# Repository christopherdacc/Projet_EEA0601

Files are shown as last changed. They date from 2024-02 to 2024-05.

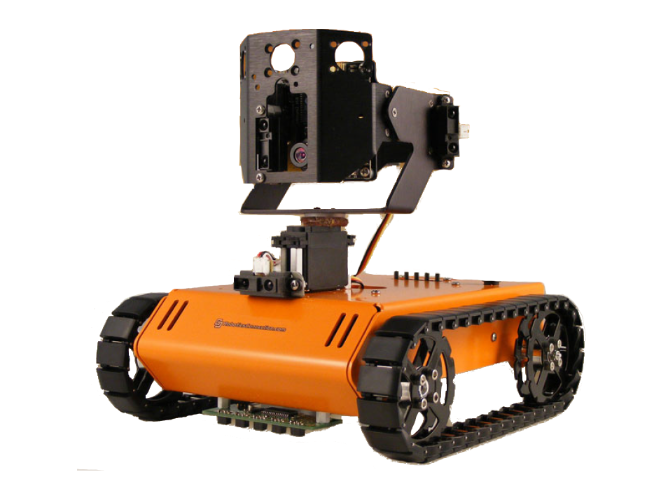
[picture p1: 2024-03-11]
Compte_rendu/pics and files/Screenshot 2024-02-27 at 23-01-09 Guide de réalisation du projet EEA0601.pdf.png

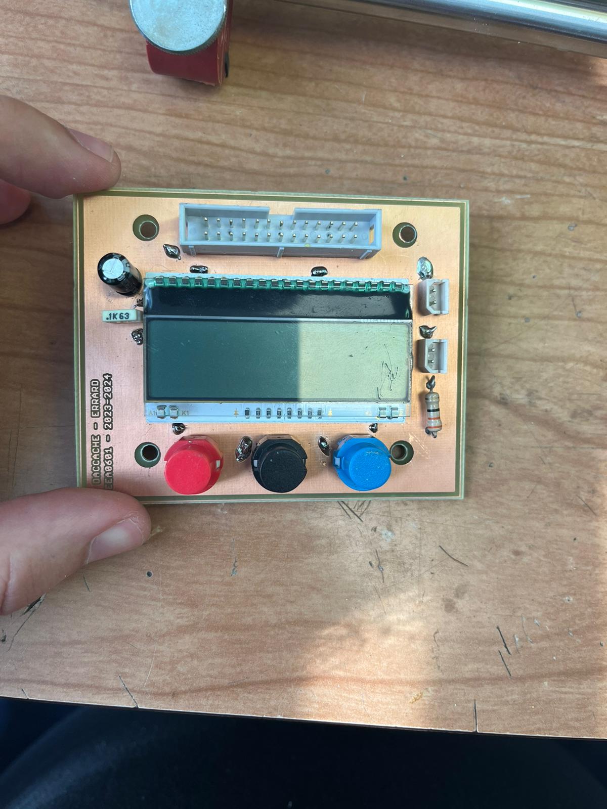
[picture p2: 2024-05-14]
Compte_rendu/IMG-20240328-WA0003.jpg

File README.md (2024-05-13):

# Projet_EEA0601 (Partie IHM)

Programmation en langage C sur MPLAB X IDE d'un microcontrôleur (dsPIC30F4012) pour un système d'IHM d'un robot.
Ce robot a pour fonction de suivre une trajectoire (suit une ligne dessinée par terre), détecter les obstacles et changer de direction pour poursuivre son chemin et une interface IHM pour pouvoir entrer des informations au microcontrôleur avec 3 boutons.

"Séances de travail surveillées et supplémentaires avec tâches réalisées"

* Séance 1 (24/01/2024):
      Explication du projet par les professeurs.
  
* Séance 2 (31/01/2024):
      Branchement d'un afficheur LCD (EA DOGM163W-A) et allumage du rétroéclairage.

* Séance 2.1 sup (02/02/2024):
      programmation et affichage de 'Bonjour le monde!' sur l'écran LCD.
  
* Séance 3 (07/02/2024):
      Branchement des boutons avec leurs résistances spécifiques.

* Séance 4 (14/02/2024):
      Programmation des boutons pour savoir s'ils sont appuyés ou non en affichant leurs états sur l'écran LCD.

* Séance 5 (21/02/2024):
      Rajout des librairies sur Eagle.
      Réalisation du schéma de la carte électronique sur Eagle.

* Séance 5.1 sup (22/02/2024):
      Finalisation du schéma de la carte électronique sur Eagle.
      Début de la réalisation de la carte électronique sur Eagle ainsi que le typon.
* Séance 5.2 sup (23/02/2024):
      Début de la programmation d'un menu avec les options de test des boutons et changement de l'éclairage de l'écran.

* Travail Vacances 6 (du 24/02/2024 au 02/03/2024):
      Finalisation du code menu (prototype)
      Erreur de Build du code.

* Séance 6.1 test du code (05/03/2024):
      Test du code et correction du build error.
      Nouveau probleme code ne marche pas comme on veux.

* Séance 7 (06/03/2024):
      Correction du Schéma de la carte.
      Correction de la carte par rapport au changements du schéma.
      Un peut de modification du code pour qu'il marche (ne marche toujours pas).

* Séance 7.1 sup (07/03/2024):
      Correction de l'affichage du menu (sélection de choix marche bien mais les choix ne marchent pas a 100%)

* Séance 7.2 sup (11/03/2024):
      Correction de la fonction délai.
      Travail sur le compte rendu.

* Séance 8 (13/03/2024):
      On a continué le routage des pistes.
      On a changer les pates des boutons et de l'ecran pour mettre les pates des boutons sur les pates CN qui permettent les interuptions sur front.
  
* Séance 9 (20/03/2024):
      On a finit la carte électronique avec le dimentionnement des pistes de +5V (0.05 inch) et pistes de signaux (0.024).
      On a cassé les angles et tout ca pour evité le rayonnement electromagnetique.

* Séance 10 (27/03/2024):
      On a percé la carte pour pouvoir souder les composants decu.

* Séance 10.1 sup (28/03/2024):
      On a réalisé le test de continuité a l'ohm mètre.
      On a resouder une piste défectueuse.
      On a souder tout les composants sur la carte.
* Séance 11 (03/04/2024):
      Reprogrammation du test des boutons en utilisant des iterruptions.
      Interruptions fonctionnent mais que sur le bouton 3.

* Séance 11.1 sup (09/04/2024):
      Correction du code de l'interruption (Fonctionnement parfait des boutons).
      Essai d'integrer la structure Keyboard avec les objets, mais pas de success.
      Changement du bouton rouge.
      Pendant le test du code, on a rencontrer un probleme de fonctionnement du microcontrolleur.
      Probleme de cablage au niveau de l'alimentation du microcontrolleur.

* Séance 12 (10/04/2024):
      Réglage du probleme de cablage au niveau de l'alimentation du microcontrolleur.
      Le code fonctionne a nouveau.
      Ajout de la fonction menu_principale() pour afficher le menu avec les different choix.
      Programmation de la navigation du curseur pour selectionner 1 des 3 choix avec prog de la saisier du choix 1 (Actions).
* Pour la prochaine séance :        - Essayer de remplacer les statusB, statusN et statusR par la structure keyboard.
                                    - Implémanter cette structure dans la fonction menu_principale().
                                    - Continuer la programmation de l'affichage.
  
* Séance 12.1 sup (13/04/2024):
      On a realiser les taches pécedantes (remplacement statusB.../implementer la struct keyboard.../ continuer la programmation de l'affichage).
      On a essayer d'implémenter les strcutures Menu, MenuItem et MenuValue mais on a pas réussi.

* Séance 12.2 sup (16/04/2024):
      On a continuer l'affichage du menu et differente options du menu avec des if et else if.
      On a réessayer d'implenter les structures Menu, MenuItem et MenuValue maus on a toujours pas réussi.
      On a essayer d'ajouter le keybord->upstate=2 pour une appuie de 2s sur le bouton rouger, mais on a pas réussi.

* To do: try using macros to simplify and reduce memory usage.

* Séance 13 (17/04/2024):
      On a utiliser macros (#define) pour l'operation moyenne%3
      On pu utiliser ticks.c pour pouvoir determiner l'appui de 2s sur un bouton.
      On a continuer la partie parametres->reglage detection obs pour essayer d'afficher un chiffre et l'incrémenter mais l'addition de chiffre et considere comme un char.
      On a vite fait compris le fonctionnement des differentes struct du menu(Menu, MenuItem et MenuValue) et l'utilisation d'une array pour stocker les differents MenuItems.

* To do: implementer les 3 structures du menu a la fonction menu_principale, réessayer la configuration de l'affichage d'un int modifiable sur l'ecran,

* Séance 13.1 sup (19/04/2024):
      On a réussi a configurer l'affichage d'un int qu'on peut incrémenter et décrémenter a l'aide des boutons pour la partie Parametres->Detection obstacle.
  
* Séance 14 (07/05/2024):
      On a finaliser le menu (partie affichage et manupulation du menu).
      Il nous reste la partie parametre (PID et vitesse) a réglé.
      Il nous reste les interruption pour recevoir et transmettre les info des capteurs et moteurs.
      il nous reste a configurer la structure MenuValues pour pouvoir envoyer les parametres au moteur.

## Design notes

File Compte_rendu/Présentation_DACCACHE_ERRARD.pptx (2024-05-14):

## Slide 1

SOMMAIRE

I. Introduction
II. Initiation à la programmation
III. Construction du programme final
IV. Conclusion

## I. Introduction

- Conception d’un robot suiveur de ligne
- Divisé en trois parties
- 13 séances obligatoires
- Capteurs de position et détecteur d’obstacles
- 2 moteurs indépendamment
- Ecran LCD
- Trois boutons
- Microcontrôleurs (carte DsPic)

## II. Initiation à la programmation

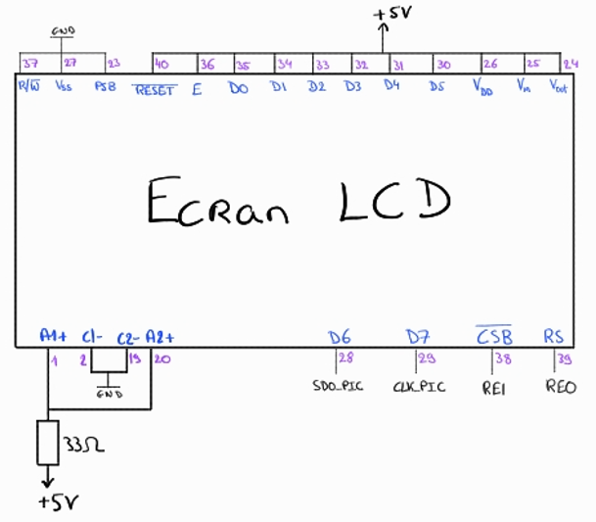
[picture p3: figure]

a) Câblages

- Ecran : 22 pin sur 40 d’utilisés
- Résistance : 33Ω
- 2 Capacités : 100µF et 100nF

## II. Initiation à la programmation

a) Câblages

- 3 Boutons sur le port B : CN

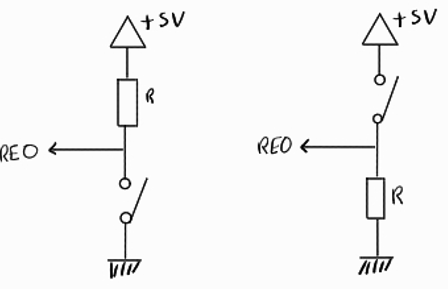
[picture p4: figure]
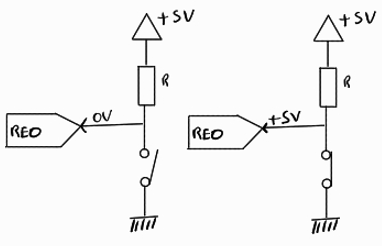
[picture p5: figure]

## II. Initiation à la programmation

b) Eagle

- Schéma électronique
- Carte élecronique
- Dimensionnement
- Cassure des coudes
- Perçage et soudure

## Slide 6

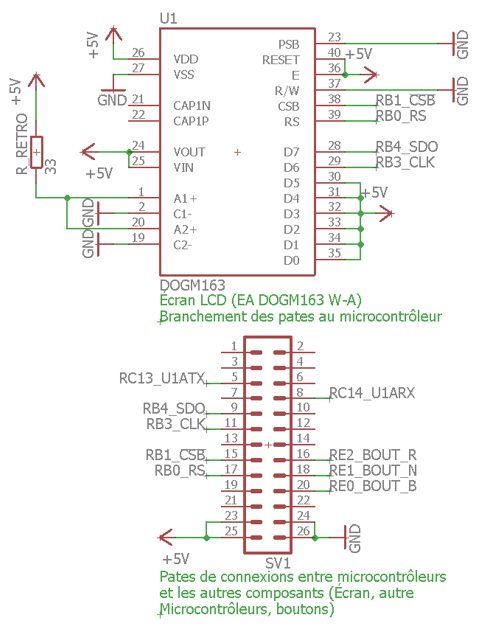
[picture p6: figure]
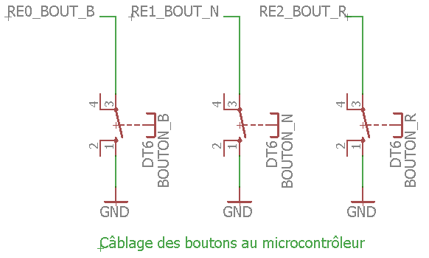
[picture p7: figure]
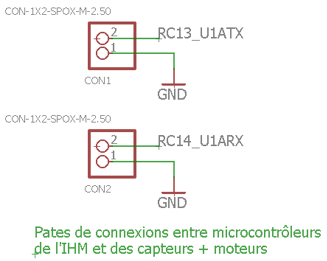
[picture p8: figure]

Schéma de la carte électronique

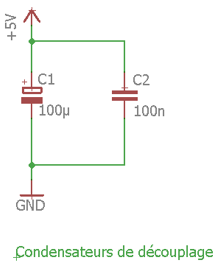
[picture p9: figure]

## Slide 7

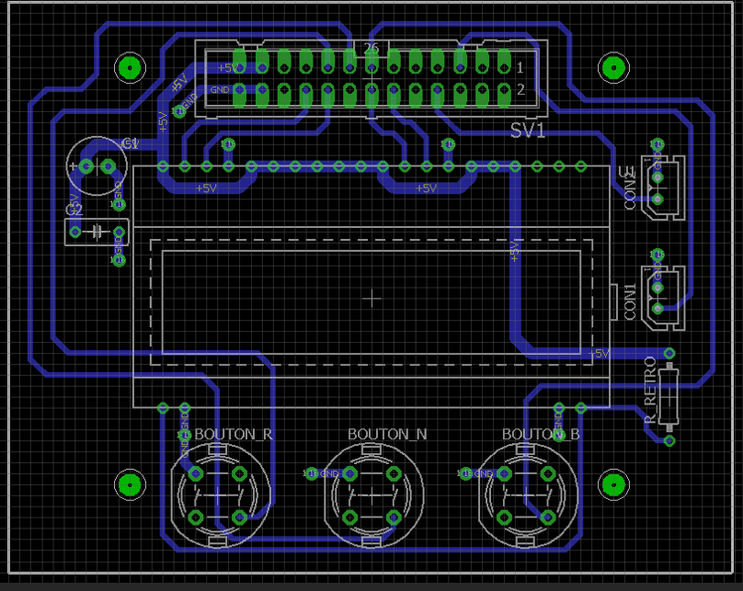
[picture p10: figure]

Board de la carte électonique

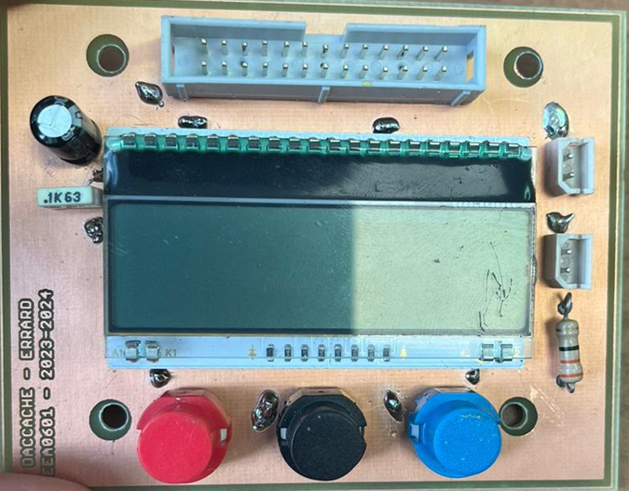
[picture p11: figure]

Carte électronique après soudure

## II. Initiation à la programmation

c) Affichage et test des boutons

- Premier programme simple :
« InitLCD();
LCDDisplayOn();
LCDGoto(0,0);
LCDWriteStr(« Bonjour"); »
- LCDGoto(X,Y);
X : nombre de ligne
Y : Position sur la ligne

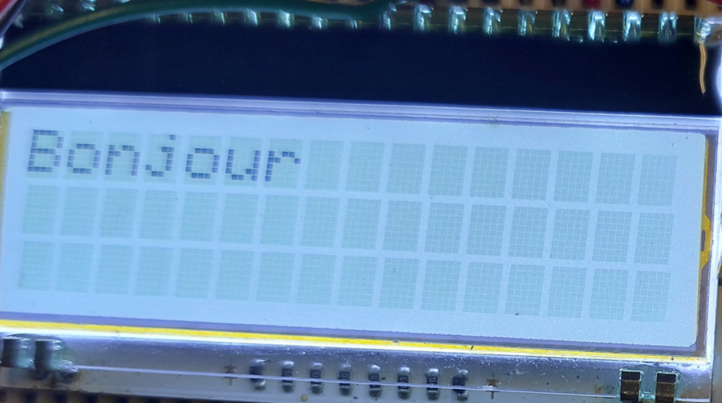
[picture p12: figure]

## II. Initiation à la programmation

c) Affichage et test des boutons

- Programmation des boutons :
« #define BUTTON1_PIN PORTBbits.RB0
#define BUTTON2_PIN PORTBbits.RB1

#define BUTTON3_PIN PORTBbits.RB2

void init_pins() {
TRISBbits.TRISB0 = 1;
TRISBbits.TRISB1 = 1;
TRISBbits.TRISB2 = 1;
CNPU1bits.CN2PUE = 1;
CNPU1bits.CN3PUE = 1;
CNPU1bits.CN4PUE = 1;
}»

do{
while (myKeyboardptr->enterEdge==1)
{
LCDGoto(0,0);
LCDWriteStr("Button 1 = 1");
}

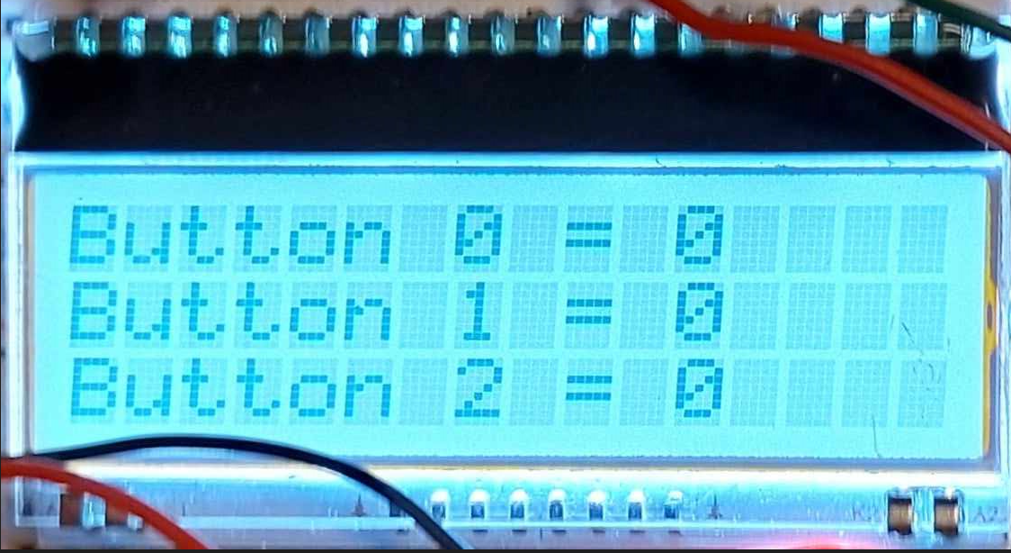
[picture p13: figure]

## II. Construction du programme final.

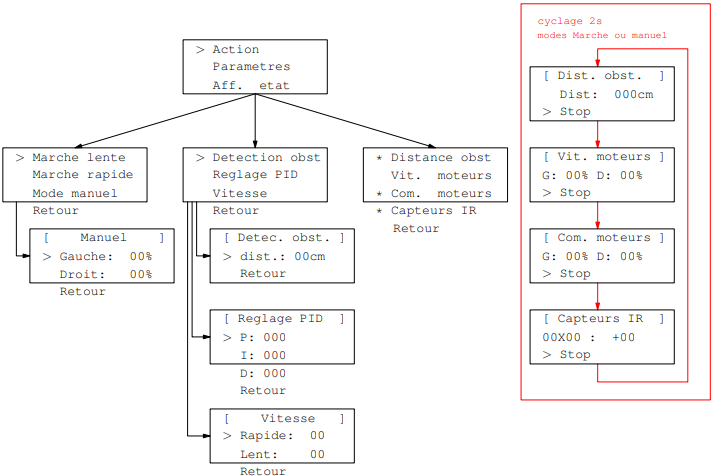
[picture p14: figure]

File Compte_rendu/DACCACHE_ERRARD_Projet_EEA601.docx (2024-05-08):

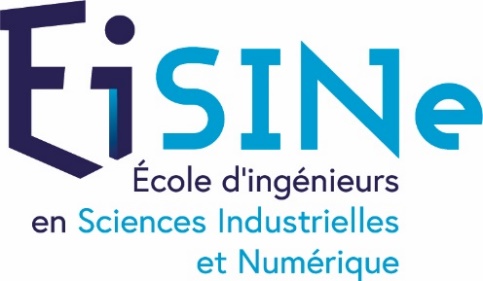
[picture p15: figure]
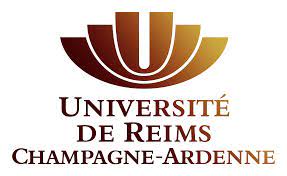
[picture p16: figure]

DACCACHE Christopher

ERRARD Mathéo

Licence 3 – EEEA

Projet : Robot suiveur de ligne

Module EEA 0601

TP Transdisciplinaire

# ---------- INTRODUCTION ----------

Dans le cadre de la matière EEA0601, nous avions comme responsabilité de mettre en place la conception d'un robot suiveur de ligne. Ce projet est une opportunité d'appliquer les connaissances que l’on a pu acquérir tout au long de nos études dans le domaine de l’électronique et de l’automatique. Pour mener à bien ce projet, il a été divisé en trois parties distinctes :

- Motorisation,
- Interface Homme-Machine (IHM)
- Capteurs

Chaque groupe possédait de treize séances obligatoire dont dix encadrées et trois en autonomie. Ce rajoute à ça, les séances personnelles. Un planning récapitulatif de nos séances est affiché un peu plus loin dans ce rapport.

Ce projet vise à développer une solution technique complète pour un robot capable de suivre une trajectoire préalablement tracée sur le sol qu’il détecte grâce à des capteurs à photodiodes. Muni de deux moteurs indépendants, il peut se déplacer de manière linéaire et angulaire en modifiant la vitesse de rotation des moteurs. Ainsi, par le biais de ces moteurs, il peut corriger sa position selon son décalage par rapport à la trajectoire voulue.

Notre binôme s’est concentré sur la partie IHM, une composante essentielle qui permet la communication entre l'utilisateur et le robot. Notre objectif principal est de concevoir une interface intuitive et fonctionnelle, intégrant des éléments de contrôle permettant à l'utilisateur de communiquer efficacement avec le robot. Pour ce faire, nous disposons de trois boutons et d'un écran d'affichage, des éléments clés qui seront utilisés pour configurer les paramètres du robot et définir ses actions.

Le succès de notre projet dépendra de la collaboration étroite entre les différentes équipes travaillant sur les différentes parties du robot. Nous devons assurer une intégration fluide de notre système IHM avec les systèmes de motorisation et de capteurs, garantissant ainsi le bon fonctionnement global du robot suiveur de ligne.

La présentation du travail effectué par notre binôme sera présentée en trois parties. La première consistera à présenter le cahier des charges, le matériel utilisé ainsi qu’un planning d’avancement du projet. La seconde, elle, décrira toute la partie électronique que nous avons pu réaliser. Quant à la dernière qui expliquera la partie programmation et asservissement du moteur.

# ---------- DEVELOPPEMENT ----------

I) Initialisation
a) Cahier des charges

La cahier des charges peut se décrire en plusieurs points.

Le premier est de concevoir et implémenter une interface homme-machine pour un robot suiveur de ligne afin de pouvoir configurer différents paramètres.

En deux, l’IHM doit être équipée de trois boutons, chaque bouton étant assigné à une fonction spécifique.

Un écran d'affichage doit y être intégré, permettant à l'utilisateur de visualiser les paramètres du robot et de sélectionner différentes actions.

Le troisième point est de pouvoir afficher différentes informations telles que la vitesse du robot, les données des capteurs comme la distance par rapport à un obstacle ou encore sa déviation par rapport à la ligne. Mais également la sélection des actions à effectuer par le robot, comme une marche lente ou rapide ou encore la correction de trajectoire.

En quatrième point, l'IHM doit être capable de recevoir et de traiter les données des capteurs du robot et de pouvoir envoyer des instructions aux moteurs du robot en fonction des informations reçues des capteurs et de la configuration que souhaite l'utilisateur.

b) Description du matériel

Pour mener à bien à bien ce projet une liste du matériel nécessaire pour chaque partie a été établit :

Capteurs | Moteurs | IHM
Carte DsPic | Carte DsPic | Carte DsPic
Capteurs de position (photos diodes) IR TCRT 5000 | Moteur | 3 boutons de type DT6
Capteurs d’obstacles (à ultrasons) : SRF 05 | BTN 8982 | Ecran LCD: EA DOGM163W-A

c) Planning

Date | Descriptions | Membre
31/01 | Câblage de l’écran LCD et allumage du rétroéclairage. | C /M[^1]
02/02 | Programmation et affichage d’un message sur l’écran LCD. | C/M
07/02 | Branchement des boutons et choix des résistances qui leurs sont associées. | C/M
14/02 | Programmation des boutons et affichage de leurs états (appuyé ou relâché) sur l’écran. | C/M
21/02 | Début sur Eagle : ajout des librairies et réalisation du schéma de la carte électronique. | C/M
24/02 au 02/03 | Réalisation d’un programme « Menu » permettant de choisir une action à l’aide des boutons. (Vacances) | C
05/03 | Test du code « Menu » mais échec. | C/M
06/03 | Correction du schéma de la carte de la carte et début de réalisation du typon et correction du code « Menu » mais non opérationnel à 100% | C/M
13/03 | Routage des pistes. Modification du choix des pattes des boutons : utilisation des CN (port B) pour les interruptions | C/M
20/03 | Finalisation de la carte électronique sur Eagles. | C/M
27/03 | Perçage de la carte, test de continuité à l’ohmmètre, soudure | C/M
03/04 | Modification du programme en utilisant les interruptions sur les boutons | C/M
09/04 | Essai de la structure Keyboard (échec). Changement du bouton rouge car légèrement défectueux. Problème au niveau des câbles d’alimentation de la carte µC. | C/M
10/04 | Changement de carte µC. Ajout de la fonction menu_principale() et affichage du menu demandé (Actions/ Paramètres/Affiche Etat) | C/M
13/04 | Insertion de la structure Keyboard dans le programme. Essai d’insertion des structures Menu, MenuItem et ManuValue | C/M
16/04 | Avancement de l’affichage avec la réalisation des sous menu. Essai de la programmation de la durée d’appui sur les boutons (échec) | C/M
17/04 | Utilisation de « ticks.c » pour gérer la durée d’appui sur les boutons. Finalisation des sous menus et insertion des structures Menu, MenuItem et MenuValue | C/M

II) Conceptions électroniques.
1. Câblage de l’afficheur

L’afficheur utilisé est un afficheur LCD sept segment de référence EA DOGM163W-A alimenté en 5V. Il possède 40 pins de connection et permet d’afficher seize carctères par ligne. Il est piloté par une interface SPI. Le branchement entre le micro-contrôleur et l’afficheur se fait par une nappe.

D’après la notice de celui-ci, il faut brancher une résistance de 30Ω relié au +5V, branché en parallèle entre les pins 1/2 et 19/20 comme on peut le voir sur la figure suivante. Dans notre cas, nous avons utilisé une résistance de 33Ω car il n’y avait de 30Ω. Les pins 1 et 20 correspondent à des anodes et les pins 2 et 19 à des cathodes. Sur les 40 pins du µC, seulement 22 ont été utilisés.

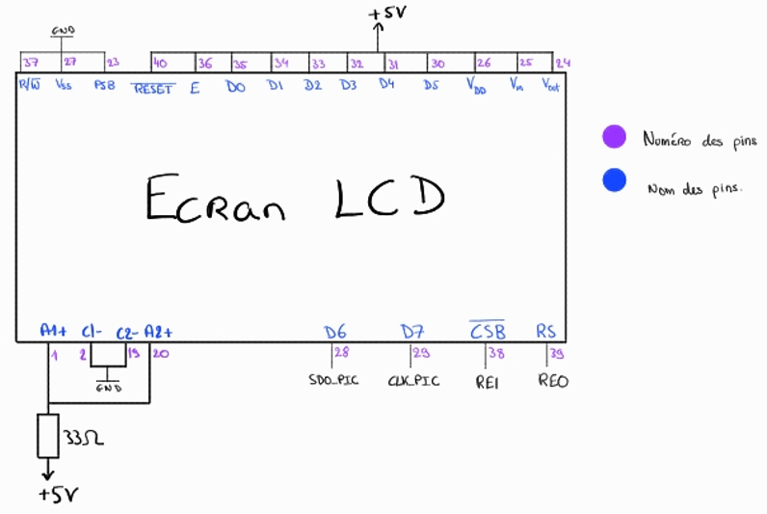
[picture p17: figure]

FIGURE

D’après la documentation qui nous a été transmise, les pins correspondant au RS, CSB, RESET sont branché sur le port B. Cependant, nous avons du changer le port B pour le port E pour garder les pattes du port B pour pouvoir utililser les interruptions du port B. Le pin 40 correspondant au RESET a été mit au +5V au lieu du port RE2 pour éviter tout problème de reset.

Pour éviter les distorsions de la tension d’entrée et donc avoir une entrée non bruitée, on a placé deux capacités de découplage en parallèle afin de protéger l’écran des fluctuation de tension. L’une est une électrochimique de valeur 100µF et l’autre est en plastique de valeur plus faible de 100nF.

2. Câblage des boutons

Pour le branchement de noq trois boutons DT6, il nous a fallut mettre des résistances en série avec les boutons et nous avons pris des résistances de 10kΩ. Dans un circuit, ils se comportent comme des interrupteurs normalement ouvert ou normalement fermé selon la configuration. La figure suivante nous montre les deux façons possibles de câbler les boutons.

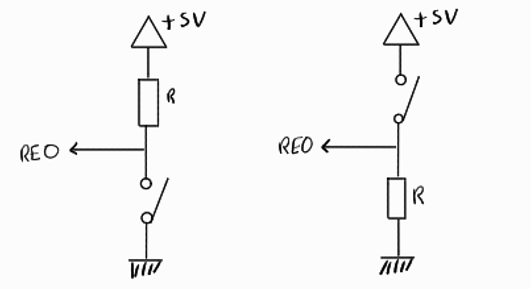
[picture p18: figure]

FIGURE CONFIGURATION BOUTON

Dans notre cas nous avons choisit la configuration 1. Dans celle-ci les boutons sont normalement ouvert et renvoient donc 0V sur les pattes sur lesquelles ils sont connectés. Un appui sur un bouton envoi du 5V sur sa patte de connection. La figure suivante nous résume ceci :

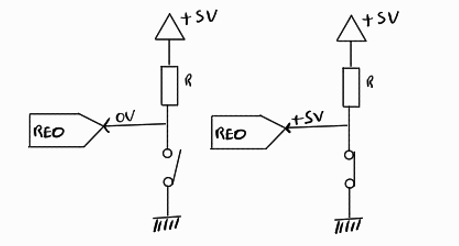
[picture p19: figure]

FIGURE LECTURE D’APPUI SUR UN BOUTON

Pour savoir si un bouton est appuyé ou non il suffit de lire la valeur reçue sur la pin correspondante.

Nos trois boutons sont de couleurs différentes : un rouge, un bleu et un noir. Leurs actions sont les suivantes :

- Rouge (+) : Incrémenter des valeurs numériques ou de monter dans un menu ou sous-menu
- Bleu (-) : Décrementer des valeurs numériques ou de descendre dans un menu ou sous-menu
- Noir (entrée) : Valider une valeur ou sélectionner une entrée dans un menu ou sous-menu

Ils vont nous permettre de naviguer, de rentrer, de sortir des menus et sous menus ainsi que d’y sélectionner différentes actions.

3. Construction schématique de la carte électronique

Après le câblage de l’écran ainsi que des boutons sur plaque à essai, nous avons réalisé sur l’application Eagles le schéma de la carte électronique comme on peut le constater sur la figure suivante.

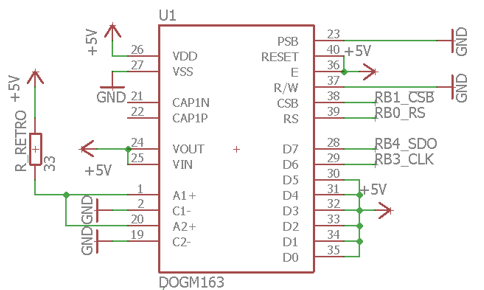
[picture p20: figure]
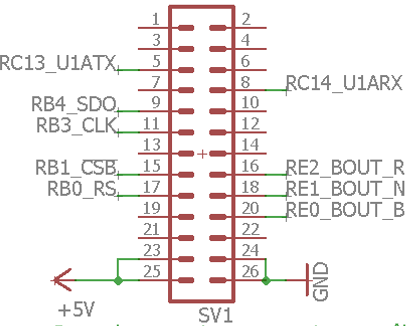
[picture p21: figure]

FIGURE ECRAN EAGLE

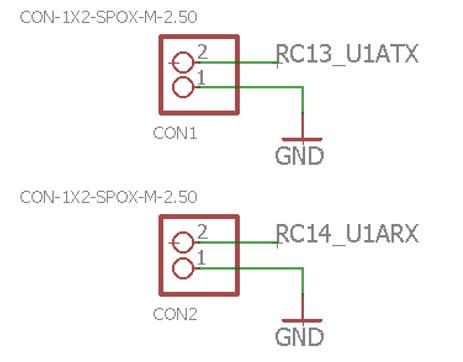
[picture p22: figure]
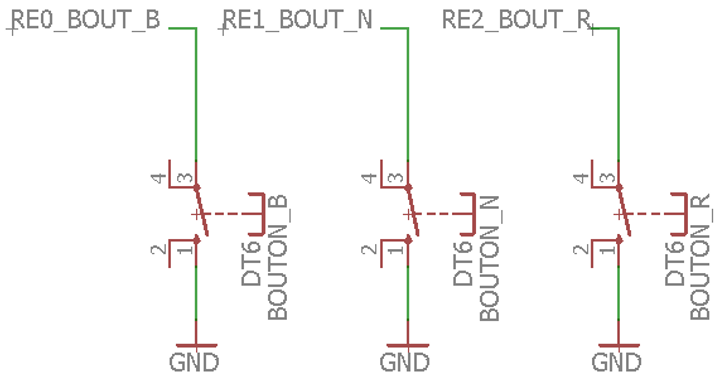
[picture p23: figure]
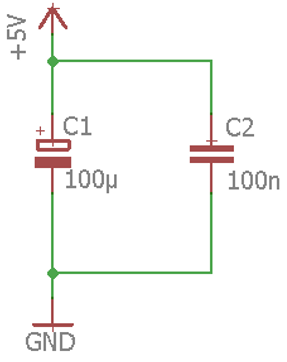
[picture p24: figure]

Pour pouvoir communiqué avec les autres groupes (capteurs et motorisaton) à l’aide d’une liaison RS232, nous avons donc placé deux connectiques Molex 22035025. L’un servira à recevoir des informations des capteurs et l’autre d’envoyer des informations à la motorisation. L’image suivante nous montre comment se fait la connexion :

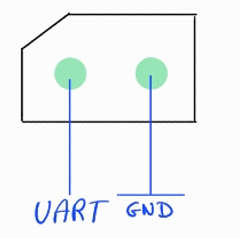
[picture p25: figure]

FIGURE CONNECTIQUES

La connexion se fait par les pattes UART du µC. La patte U1ATX sert à la réception de données et la patte U1ARX sert à la transmission de données.

III) Conceptions informatique.
1. Initiation à la programmation

Dans un premier temps, nous avons commencé par programmer et afficher un message simple pour se familiariser avec le logiciel. Nous avons afficher le message « Bonjour le monde ». Le code d’affichage de ce message est en annexe 1 et la figure suivante correspond à l’organigramme de ce message.

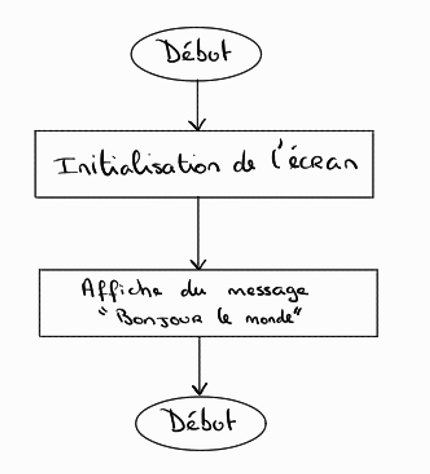
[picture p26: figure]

Figure : Organigramme du premier code

Dans un second temps, nous avons fait le branchement des boutons qu’on peut retrouver sur l’annexe 2. Nous avons d’abord programmé l’appui d’un seul bouton à la fois est d’afficher à 1 lorsque le bouton est appuyé. La figure suivante nous montre l’organigramme de ce code. Ensuite, on a modifié ce code pour pouvoir lire et afficher l’appuie sur un ou plusieurs bouton. Dans cette étape, on a d’abord fait la programmation sans utiliser les interruptions seulement avec des « if » ou « else if » puis après avec les interruptions. Et en faisant ces deux méthodes, on a observé que la méthode des interruptions étaient plus rapide.


[^1] C : Christopher / M : Mathéo

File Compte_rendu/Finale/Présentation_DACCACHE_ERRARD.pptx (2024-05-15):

## Projet : Robot suiveur de ligne


Sujet : Interface Homme Machine d’un Robot Suiveur de Ligne
Réalisé par ERRARD Mathéo et DACCACHE Christopher
Enseignants responsables : COLAS Maxime et CARTON David

Module EEA 0601
TP Transdisciplinaire Année 2023/2024

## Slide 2

SOMMAIRE

- Introduction
- Conceptions électroniques
- Conceptions Informatiques
- Conclusion


## I. Introduction

- Cahier des charges
- Matériel Utilisé


## I. Introduction


- Planning

## II. Conceptions électroniques

a) Câblages

- Ecran : 22 pins sur 40 d’utilisés
- Résistance : 33Ω
- 2 Capacités : 100µF et 100nF


## II. Conceptions électroniques

a) Câblages

- 3 Boutons sur le port RB : CN


## II. Conceptions électroniques

b) Réalisation Carte Électronique

- Schéma électronique
- Carte électronique
- Dimensionnement
- Prévention des perturbations électromagnétiques
- Perçage et soudure

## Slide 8


Schéma de la carte électronique


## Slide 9


Board de la carte électonique


Carte électronique après soudure

## III. Conceptions Informatiques

a) Affichage et test des boutons

- Premier programme simple :
« InitLCD();
LCDDisplayOn();
LCDGoto(0,0);
LCDWriteStr(« Bonjour"); »
- LCDGoto(X,Y);
X : nombre de ligne
Y : Position sur la ligne


## III. Conceptions Informatiques

a) Affichage et test des boutons

- Programmation des boutons :
#define BUTTON1_PIN PORTBbits.RB0

#define BUTTON2_PIN PORTBbits.RB1

#define BUTTON3_PIN PORTBbits.RB2

void init_pins() {
TRISBbits.TRISB0 = 1;
TRISBbits.TRISB1 = 1;
TRISBbits.TRISB2 = 1;
CNPU1bits.CN2PUE = 1;
CNPU1bits.CN3PUE = 1;
CNPU1bits.CN4PUE = 1;
}

do{
while (myKeyboardptr->enterEdge==1)
{
LCDGoto(0,0);
LCDWriteStr("Button 1 = 1");
}


## III. Conceptions Informatiques

b) Structure du Menu


## III. Conceptions Informatiques

b) Structure du Menu


## III. Conceptions Informatiques

c) Initialisation du Menu


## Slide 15

d) Paramètres du Menu


## IV. Conclusion

- Difficultés
- Solutions
- Projet finale
- Conclusion

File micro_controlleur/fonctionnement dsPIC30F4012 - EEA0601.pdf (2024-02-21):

EEA0601

L3 EEEA
année 2022-2023

### TP transdisciplinaire en EEA Principes de programmation du dsPIC30F4012

## 1 Structure d’un microcontrôleur

Un microcontrôleur est un composant associant dans un même boitier un coeur de microprocesseur, de la mémoire et des périphériques.

### 1.1 Microprocesseur

Le microprocesseur a pour rôle d’éxécuter un programme composé d’une succession d’instructions rangées en mémoire. Pour cela, il dispose d’une unité de décodage d’instructions, d’une unité arithmétique et logique et de registres. Ces derniers sont destinés :
- à manipuler les données (registres de travail ou W) ;
- à indiquer l’état du processeur (registres SR) ;
- ou à piloter le moteur DSP intégré au microprocesseur.

SFR; RAM; Flash; EEPROM; µProc; PWM; Timers; ADC; Osc.; Watch D; DCI; SPI; UART; CAN; m´emoire donn´ee; m´emoire prog.; bus synchrones bus asynchrones; Interruption Config./Contrˆole; Microcontrˆoleur

Fig. 1 : Structure interne d’un micro-contrôleur
Dans un langage évolué tel que le C, les registres ne sont presque jamais manipulés par le programmeur.

### 1.2 Mémoire

Le programme et les données sont stockées différemment selon l’architecture du microcontrôleur. Dans le cas de la structure de type Harvard utilisée par Microchip, trois types de mémoires sont disponibles et utilisés comme suit :
- la RAM représente quelques ko de mémoire volatile : elle accueille les variables utilisées par le programme ;
- la FLASH représente quelques centaines de ko voire quelques Mo : elle accueille le programme ainsi que les données constantes. Cette mémoire est conservée en cas de rupture de l’alimentation ;
- l’EEPROM est disponible pour stocker les données de configuration critiques d’un programme en cas de perte d’alimentation et les restituer au redémarrage. Généralement chaque microcontrôleur en embarque 1 ou 2 ko.
M. COLAS | 1

Espace programme
Les mémoires FLASH et l’EEPROM sont accédées par un bus de 24bits permettant d’adresser potentiellement 16Mo appelés espace programme. l’espace programme est pointé par un registre appelé compteur programme ou PC dont le rôle est de dépiler les instructions du programme. L’ensemble de cet espace d’adressage n’est pas uniquement occupé par du code programme ou par les données de l’EEPROM. Le début de la zone accueille la table des adresses des routines d’interruption et les 8Mo d’adresse haute sont réservés pour stocker quelques éléments tels l’identifiant du microcontrôleur ou ses bits de configuration. Finalement, la majorité de l’espace programme ne contient pas réellement de mémoire physique. Une grande partie des adresses sont inutilisées et pointent dans le vide.
M´emoire donn´ees | M´emoire programme

0x0000

0x07FE
0x0800

0x1000

0x8000

0xFFFE

SFR

RAM dsPIC30F4012 (2ko)

Non utilis´e

Fenˆetre m´emoire prog.

Vecteurs
d’interruption

0x000000

0x0000FE

M´emoire prog. 48kInst.

Non utilis´e

EEPROM 1ko

Zone de config.

0x017FFE
0x018000

0x7FEFFE
0x7FF000

0x7FFFFE
0x800000

0xFFFFFE

Fig. 2 : Espaces d’adressage données et programme

Espace données
Le microprocesseur accède à la mémoire RAM à l’aide d’un bus de données 16bits qui ne permet d’adresser que 64ko de mémoire. Une partie de cet espace d’adressage (environ 2ko) est réservée pour accéder aux registres de périphériques appelés SFR (special function registers). Ces registres permettent de configurer et de piloter chacun des périphériques présents dans le microcontrôleur. Le découpage des espaces mémoire est présenté sur la figure 2 dans le cas spécifique du pic30F4012.

### 1.3 Périphériques

Les périphériques intégrés au microcontrôleur sont nombreux et aux fonctionnalités multiples :
- interfaces dédiées aux bus de communications synchrones (SPI, DCI, I2C) ;
- interfaces dédiées aux bus de communication asynchrones (UART, CAN) ;
- entrées-sorties TTL ou à collecteur ouvert ;
- timers ;
- input-capture ;
M. COLAS | 2

- output-compare ;
- générateur de modulation de largeurs d’impulsions (PWM).
Grâce au mécanisme d’interruption décrit en section 2.1, chacun de ces périphériques est apte à indiquer au microprocesseur l’ocurrence d’évènements nécessitant un traitement immédiat.

## 2 Structure d’un programme sur microcontrôleur

Les programmes implantés sur les microcontrôleurs possèdent tous la même structure : les actions périodiques ou déclenchées par les périphériques sont insérées au sein de routines d’interruption. Parmi ces actions, on peut citer :
- l’acquisition de valeurs analogiques à intervalle de temps régulier ;
- la lecture d’une valeur reçue sur un bus de communication ;
- la détection d’un front sur une entrée à fréquence élevée ou lorsque l’instant du front doit être consigné avec précision.
Les actions dont la prise en charge n’est pas urgente ou dont le traitement est long sont insérées dans une boucle sans fin. Il s’agit généralement des actions d’interaction avec un opérateur humain parmi lesquelles on trouve :
- la détection d’un appui sur un bouton (méthode de scrutation aussi appelée pooling) ;
- la mise à jour d’un afficheur LCD.

### 2.1 Routines d’interruption

Une routine d’interruption est une fonction particulière qui ne prend pas de paramètre et qui ne retourne
aucun résultat.Elle n’est jamais explicitement appelée par le programme mais son exécution est
déclenchée sur évènement d’un périphérique (timer, réception d’un octet sur un bus de communcation, fin de transmission d’un octet, fin de conversion analogique, détection d’un front, overflow de certains registres …)

### 2.1.1 Fonctionnement

Lorsqu’un périphérique souhaite signaler un évènement, un drapeau est positionné dans l’un des registres IFSx. L’interruption n’est appelée que si le programme l’a autorisée. A cet effet, les registre nommés IECx contiennent un ensemble de bits dont chacun est lié à une interruption autorisée (valeur à 1) ou non prise en compte (valeur à 0). Lorsque l’interruption est autorisée, le passage à 1 du drapeau correspondant du registre IFSx déclenche immédiatement les actions suivantes :
1. les contenus du pointeur d’exécution et du registre d’état sont mémorisés sur la pile ;
2. le registre d’exécution est chargé avec l’adresse de la routine d’interruption qui s’éxécute immédiatement ;
3. la routine efface le drapeau d’interruption pour éviter une relance immédiate de l’interruption une fois la routine quittée ;
4. après exécution de la dernière instruction de la routine, le pointeur d’exécution et l’état du processeur sont restitués ;
5. l’exécution du programme principal reprend là où il avait été quitté.
Pour le compilateur C30, chaque source d’interruption est liée à une routine grâce à son nom : ainsi l’interruption du timer 1 doit être nommée _T1Interrupt(), l’interruption indiquant la réception d’un octet sur l’UART se nomme _U1RXInterrupt().
M. COLAS | 3

### 2.2 Structure type d’un programme

Le code est organisé comme suit :
1. les routines d’interruptions sont définies ;
2. au sein de la fonction main, les périphériques sont initialisés, puis activés ;
3. les sources d’interruptions pour lesquelles les routines ont été définies sont autorisées (i.e. demasquées) ;
4. une boucle sans fin est ajoutée, vide si l’ensemble des actions est déclenchée sur interruption ou contenant les actions dont le traitement ne revet pas de caractère d’urgence.
Un tel code type est présenté ci-dessous et l’organigramme correspondant sur la figure 3 .
La communication de données entre les routines d’interruption et le corps du programme (main) est assurée par des variables globales, c’est à dire déclarées en dehors de tout corps de fonction.

### 1 void __attribute__((__interrupt__,no_auto_psv)) _[Periph1Name]Interrupt( void ){

2
3 | ... | // Actions à exécuter dans la routine

4
5 | IFSxbits.[Periph1Name]IF=0; | // Acquittement de l'interruption
6 }

7
8 ...

### 9 void main(void){

10
11 | init[Periph1Name]([Init args]); | // Appel des fonctions
12 | init[Periph2Name]([Init args]); | // d'initialisation des périphériques
13 ...
14 | enable[Periph1Name]Interrupt(); | // autorisation des interruptions
15 // déclenchées par Periph1

16

### 17 while(1){ 18 if([Event]){

19 | [Low priority action]; | // pooling d'évènements peu prioritaires
20 }
21 }
22 }

### 2.3 Les entrées-sorties numériques (I/O)

Les entrées-sorties numériques sont groupées en ports 16 bits (A0 à A15, B0 à B15, …) et sortent sur des broches respectivement nommés RA0 à RA15, RB0 à RB15 ... Le nombre de broches dédiés aux I/O effectivement présentes sur un microcontrôleur dépend de sa taille et tous les bits d’un port ne sont pas nécessairement présents physiquement sous forme d’une broche. La figure ?? présente le brochage du
| dsPIC30F4012.
Chaque broches I/O admet en entrée ou fixe en sortie, selon sa direction, des tensions TTL. Par défaut, après reset du microcontrôleur, les broches configurées pour utiliser les ports d’entrées-sorties sont programmeés en entrées pour éviter d’imposer des tensions sur des broches connectées à des circuits externes fixant leur propre niveau de tension. Sur le dsPIC30F4012, il n’est pas possible de fournir ou d’absorber un courant supérieur à 25mA par broche avec une limite supérieure à 200mA pour l’ensemble du
| microcontrôleur.
M. COLAS | 4

Action interrupt.

Acquittement

Initialisations; D´emasquage interruptions; Action 1; Action 2; Oui; Non

Programme principal

Routine d’interruption

´ev`enement IT

Fig. 3 : Organigramme d’un programme type sur micro-contrôleur


Fig. 4 : Brochage du dsPIC30F4012

☞ Attention :
Les broches d’un microcontrôleur sont généralement associées à différentes fonctionnalités multiplexées : le nom de la broche indique alors ces fonctionnalités par priorité décroissante. Ainsi, une broche AN7/RE8 est utilisée en entrée analogique dès lors que le module de conversion analogique est activé et que la programmation de la voie AN7 le prévoit. Selon cette nomenclature, le module I/O est généralement le moins prioritaire : il est donc important de vérifier qu’aucun périphérique ne masque ce module sur les broches devant être utilisées en I/O.

### 2.3.1 Programmation

Chaque bit d’un port est paramétrable en entrée ou en sortie individuellement. Pour cela, on utilise le registre TRISn où n indique le port (A, B C, ...). Un bit à 1 place de bit en entrée alors qu’un bit à 0 le programme en sortie. Une fois la direction du port choisie, on lit l’état électrique ou on écrit la valeur TTL à imposer sur la broche à l’aide du registre PORTn. Enfin, il est possible que l’état électrique d’une broche soit différent de l’état logique fixé par le programme (court circuit, pilotage d’un circuit capacitif en fréquence élevée). L’état logique peut alors être relu à l’aide du registre LATn alors que la lecture de PORTn fournira l’état électrique de la broche. La circuiterie interne des entrées-sorties est illustrée sur la figure 5 .

M. COLAS | 5

IO pad; data; WR DATA; WR TRIS; RD TRIS; RD LAT; RD PORT

Fig. 5 : Circuiterie des entrées-sorties

### 2.4 Programmation des timers

Les timers sont des modules utilisés pour produire des actions à intervalle de temps constant ou pour mesurer des durées entre deux évènements successifs. Dans le premier cas, on parle du mode output-compare et dans le second de mode input-capture. Sur les microcontrôleurs Microchip, chacun de ces modes est mis en oeuvre en combinant un timer et un module spécifique au mode. Le dsPIC30F4012 dispose de 3 timers indépendants.

### 2.4.1 Utilisation du timer seul

Chaque timer est constitué d’un compteur de 16 bits permettant de balayer les valeurs de 0 à 65535. Le quantum temporel d’incrémentation est donné par le temps de cycle Tcy =
1
Fcy

où la fréquence de cycle
Fcy est donnée par :

Fcy =

7.372 × 10⁶ × MP LL
4

Hz
MP LL est un facteur multiplicatif programmable qui vaut au maximum 16. Ainsi on obtient la fréquence
maximale Fcy = 29.488Mhz soit Tcy = 34ns.
A ce rythme, chaque compteur 16 bits atteint 65535 en 0,2ms, ce qui est un temps souvent trop court en regard des signaux à générer ou à mesurer. Pour allonger la durée de comptage, on peut exploiter deux pistes :
- cascader les timers 2 et 3 afin de produire un timer 32 bits et atteindre une durée de comptage pouvant atteindre de 145s ;
- ralentir l’horloge de comptage en divisant Fcy : c’est le rôle des prescalers.

Principe de fonctionnement
Le fonctionnement du timer est le suivant (voir figure 6) :
1. le compteur 16 bits TMRi s’incrémente toute les αTcy où α représente la valeur de prescaler ;
2. lorsqu’il atteint la valeur cible définie dans le registre PRi,
- il est remis à 0 ;
- une demande d’interruption est levée ;
En mode 32 bits le fonctionnement est identique, la valeur finale de comptage est inscrite dans la concaténation des registres PR3 (mot de poids fort) et PR2 (mot de poids faible). le registre de comptage TMR3 est incrémenté sur overflow du registre de comptage TMR2. Lorsque TMR3:TMR2 = PR3:PR2, les registres de comptage sont remis à 0 et une demande d’interruption est levée émanant du timer 3.
M. COLAS | 6

Fcy | Prescaler 1,8,64,256 | 16bits counter

TMRi

Target

PRi

=

reset

Interrupt

Fig. 6 : Utilisation d’un timer en générateur d’évènements périodiques

Programmation du Timer pour le déclenchement d’actions périodiques
Une librairie constituée des fichiers periph_tmr.c et periph_tmr.h, disponible sur votre environnement numérique de travail (Moodle du cours EEA0601) permet de simplifier le déclenchement d’actions à intervalles réguliers. Afin de répondre à la majorité des besoins, cette librairie exploite les timers 2 et 3 en mode 32 bits. Les fonctions disponibles sont :
- InitTimer3(unsigned long periode) permet d’initialiser le timer 3 en mode 32bits afin qu’il lève une demande d’interruption toute les 3, 39 × periodeµs avec period ∈ {0, . . . , 2

32 − 1}.
- Timer3InterruptEnable(void) autorise le déclenchement d’interruptions par le timer 3 et active le comptage.
☞ Attention :
La déclaration de la routine d’interruption _T3Interrupt( void) est indispensable préalablement à l’utilisation de la fonction Timer3InterruptEnable(void) sous
peine de plantage.

### 2.4.2 Mode output-compare

En association avec le module output-compare, un timer peut être utilisé pour activer une sortie TTL à chaque fois que le compteur atteint une valeur cible primaire inscrite dans le registre OCxR puis la désactiver lorsqu’il atteint une valeur cible secondaire inscrite dans le registre OCxSR. On peut ainsi générer des impulsions de durée variable et précise sans gestion logicielle ou même des modulations de largeur d’impulsion (MLI¹

). Ce mode n’étant généralement pas utilisé dans les projets d’EEA0601, il n’est pas décrit davantage ici.

### 2.4.3 Mode input-capture

En association avec le module input-capture, un timer est utilisé pour mesurer précisément l’intervalle de temps entre deux évènements sans scrutation logicielle. Le fonctionnement de ce mode est illustré sur la figure 7.
Sur l’occurrence d’un front sur la broche ICx, le contenu du timer y est instantanément mémorisé dans le registre ICxBUF. Le type de front détecté est paramétrable. Simultanément, l’exécution de la routine d’interruption ICxInterrupt est déclenchée (voir section 2.1) : cette routine a principalement pour objectif de traiter la valeur du timer mémorisée. Ainsi pour calculer la largeur ∆t = t2 − t1 de l’impulsion rectangulaire illustrée sur la figure 7, on utilisera l’organigramme présenté sur la figure 8 . Le PIC30F4012 ne propose que deux broches d’entrées en input-capture (IC7 et IC8).

Programmation du mode input-capture
Le mode input-capture est facilement utilisable grâce à la librairie constituée de periph_ic.c et periph_ic.h présents sur votre environnement numérique de travail.
Toutefois, il sera souvent nécessaire de modifier cette librairie ainsi que periph_tmr afin de les adapter aux spécificités de votre application. En particulier la gestion du timer destiné à horodater l’instant d’occurrence des fronts (timer 3 par défaut) est laissée à la charge du développeur qui doit veiller à ne

1Cette dernière fonctionnalité est plus simple à implémenter au moyen du module PWM spécifique décrit en section 15 de la documentation de référence.

M. COLAS | 7

ICx; Prescaler; TMRy Fcy; ICxBUF

Fig. 7 : Fonctionnement du mode input-capture

´ev`enement IT; Front ↓; Non; Oui; b ← ICxBUF; a ← ICxBUF; Acquittement

Fig. 8 : Détermination d’un intervalle de temps entre deux fronts (∆n est une image de ∆t)

pas interférer avec les timers en charge de la génération d’évènements à intervalles réguliers (c.f. section 2.4.1).
La librairie ne contient qu’une fonction déclinée pour chaque entrée ICx x ∈ {7, 8} :
- ICxInterruptEnable(unsigned int edge) active la détection de fronts de type edge sur l’entrée ICx et autorise le déclenchement d’une interruption lors de l’occurrence de cet évènement. edge peut prendre les valeurs RISING, FALLING, ou EVERY.
☞ Attention :
- La déclaration de la routine d’interruption _ICxInterrupt( void)
est indispensable préalablement à l’utilisation de la fonction ICxInterruptEnable(unsigned int edge) sous peine de plantage.
- Si vous êtes amené à modifier ou compléter la librairie, il est important de renommer les fichiers associés afin de ne pas confondre votre code avec sa version originelle.

### 2.4.4 Détermination de la valeur d’un prescaler

Comme expliqué précédemment, le prescaler a pour rôle de diviser la fréquence d’horloge Fcy et donc de ralentir la vitesse d’incrémentation des timers. Sa valeur doit être fixée en fonction :
- de la durée ∆t maximale souhaitée entre deux déclenchements d’actions successives ;
- de l’estimation de l’intervalle de temps maximum observable ∆t entre deux fronts successifs sur ICx en mode input-capture.
M. COLAS | 8

Dans les deux cas, le prescaler doit satisfaire :

P r > ∆tFcy
2

16
☞ Attention :
Dès lors que cette condition est respectée, il est préjudiciable de surévaluer la valeur du prescaler sous peine de perdre en résolution temporelle (incréments par seconde) : en particulier, la mesure d’intervalle entre 2 fronts rapprochés sur ICx peut devenir imprécise.

### 2.5 Le module de génération d’une modulation de largeur d’impulsion

Le microcontrôleur dsPIC30F4012 intègre un module permettant de générer jusqu’à 6 signaux PWM (Pulse Width Modulation) de période commune dont les sorties sont couplées deux à deux. Le fonctionnement de ce module est précisément décrit en section 15 du dsPIC30F Family reference manual
. (http://ww1.microchip.com/downloads/en/devicedoc/70046d.pdf)

### 2.5.1 Fonctionnement du module PWM

Chaque broche PWMxH et PWMxL, x∈ {1, 2, 3} peut, au choix être utilisée par le module PWM ou comme une I/O logique. La période de la modulation est commune et produite par un unique timer 16 bits programmable intégré au module PWM et incrémenté au rythme Fcy
N

où N ∈ {1, 4, 16, 64} désigne une valeur de prescaler programmable.
Dans le mode Edge aligned, l’ensemble des sorties PWMxH utilisées passent à l’état haut lorsque le compteur du timer PTMR atteint sa valeur finale . En revanche, chaque sortie passe et à l’état bas lorsque le timer atteint une valeur spécifiée dans le registre DCYx pour cette voie comme le montre la figure 9 . Ce fonctionnement permet de générer un signal MLI de période et de rapport cyclique souhaités. Lorsque des voies PWMxL sont utilisées par le module PWM, elles fonctionnent en opposition des voies PWMxH associées à moins que le mode independent output n’ait été explicitement requis. Ce fonctionnement complémenté facilite la commande des hacheurs en interdisant aux transistors haut et bas d’un même bras de pont d’être simultanément passants ou bloqués (avec l’adjonction d’un éventuel temps mort

programmable).; PTPER; Prescaler; PTMR; Fcy; reset; DCY1; DCY2; PEN1H; PEN2H

Fig. 9 : Fonctionnement du module PWM

### 2.5.2 Programmation du module PWM

Les fichiers periph_pwm.c et periph_pwm.h présents sur le cours Moodle offrent une librairies de fonctions de base permettant de programmer le module PWM. Les fonctions disponibles sont :
- InitPWM(unsigned int period,enum PWM_PIN_INIT_FLAGS PIN_Init) : initialise le module PWM pour un signal de période period × 2.17µs. PWM_PIN_INIT_FLAGS PIN_Init fixe les broches à utiliser pour la PWM et doit être choisi selon une combinaison (et logique) de PEN1L, PEN2L, PEN3L,
M. COLAS | 9

PEN1H, PEN2H et PEN3H. Il est aussi possible de dissocier les broches L et H de la voie i (independant mode) en adjoignant l’élément INDEPi.
Ainsi InitPWM(460,PEN1L&PEN1H) initialise une PWM de période 1ms dont les sorties sont en opposition sur PEN1L et PEN1H.
- PWMEnable(enum MOD_ENABLE onoff) : active le module PWM.
- PWM1PulseWidth(unsigned int Ton) : fixe le rapport cyclique sur la voie 1 selon α =

Ton
period.
- PWM2PulseWidth(unsigned int Ton) : fixe le rapport cyclique sur la voie 2.

### 2.6 Le module de conversion analogique-numérique

Le dsPIC30F4012 possède 9 entrées analogiques multiplexées vers quatre échantillonneurs bloqueurs étiquetés CH0 à CH3. Les sorties de ces bloqueurs sont quantifiées séquentiellement sur 10 bits par un unique convertisseur analogique-numérique à approximations successives. L’étendue de mesure des données converties est paramétrable
- soit entre AVSS et AVDD (images filtrées de la tension d’alimentation du microcontrôleur) i.e. entre 0 et 5V
- soit entre Vref- et Vref+ qui doivent cependant rester tels que AVSS≤Vref-<Vref+≤AVDD Comme présenté sur la figure 10, le multiplexeur 1 permet de choisir les voies à numériser, en mode single ended (référencées à la masse) ou différentiel (différence de potentiel entre deux ANx). Toutes les combinaisons d’entrées ne sont pas disponibles et on se réfèrera à la documentation du microcontrôleur
- (http://ww1.microchip.com/downloads/en/devicedoc/70046e.pdf) pour plus de détails. Lorsque les entrées à numériser sont connectées à différents bloqueurs, cela rend possible l’acquisition d’une image simultanée des tensions présentes sur ces entrées. L’unique convertisseur analogique-numérique est alors successivement connecté à chaque bloqueur (multiplexeur 2) afin de quantifier les tensions bloquées. Les valeurs converties sont ensuite stockées dans les registres ADCBUFx,
x ∈ {0, · · · 15}.
Selon la programmation du module, il est possible de numériser en séquence une même voie ou plusieurs voies bloquées simultanément. De même les registres ADCBUFx peuvent être utilisés comme une FIFO ou au contraire en correspondance (stockage de la valeur associée à ANi dans ADCBUFi).

Multiplexeur 1; Multiplexeur 2; CAN; Vref+ Vref-; contrˆole; ADCBUF15; ADCBUF14; ADCBUF13; ADCBUF12; ADCBUF11; ADCBUF10; ADCBUF9; ADCBUF8; ADCBUF7; ADCBUF6; ADCBUF5; ADCBUF4; ADCBUF3; ADCBUF2; ADCBUF1; ADCBUF0

Fig. 10 : Fonctionnement du module de conversion analogique-numérique

### 2.6.1 Programmation du module de conversion analogique-numérique

La programmation du module de conversion analogique-numérique est grandement facilitée par la librairie constituée des fichiers periph_adc.c et periph_adc.h présents sur le cours Moodle de la matière. Les fonctions fournies sont les suivantes :
- InitADC0(void), InitADC0and1(void), InitADC4and5(void) et InitADC0to3(void) sont destinées à initialiser le module pour une acquisition simultanée sur les voies AN indiquées.
M. COLAS | 10

- InitADC0Seq0to4(void) et InitADC0Seq0to5(void) sont destinées à initialiser le module pour une acquisition séquentielle des voies AN indiquées.
- StartADC0(unsigned int* ADCxValue0) bloque la valeur analogique présente sur AN0 puis lance la quantification de la voie bloquée et attend la fin de conversion. Le résultat est stocké dans la variable ADCxValue0 qui doit être déclarée préalablement à l’appel de la fonction (passage par adresse).
- StartADC0to3(unsigned int* ADCxValue0, unsigned int* ADCxValue1, unsigned int* ADCxValue2, unsigned int* ADCxValue3) bloque simultanément les valeurs analogiques présentes sur ANi
i ∈ {0, 1, 2, 3} puis lance successivement la conversion de chaque voie bloquée et attend la fin de l’ensemble des conversions. Les résultats sont stockés dans les variables ADCxValuei, i ∈ {0, 1, 2, 3}
qui doivent être déclarée préalablement à l’appel de la fonction (passage par adresse).
- StartADC0seq0to4(unsigned int* ADCxValue0, unsigned int* ADCxValue1, unsigned int* ADCxValue2, unsigned int* ADCxValue3, unsigned int* ADCxValue4) bloque et convertit successivement les entrées AN0 à AN4.

### 2.7 Le module de communication série asynchrone

Le module UART (Universal Asynchronous Receiver Transmitter) est un contrôleur de communication série présent dans de très nombreux équipements (microcontrôleurs, PC, automates, appareillage de mesure …) et habituellement associé au standards RS-232. Une communication asynchrone série consiste en l’envoi successif de valeurs binaires transcodées en impulsions électriques sur une paire filaire. Le caractère asynchrone de cette communication provient du fait que le signal d’horloge cadençant la communication n’est pas transmis en parallèle des données : cette horloge doit être reconstituée coté réception à l’aide d’informations a priori communes à l’émetteur et au récepteur (le débit par exemple) ou/et de l’observation des trames reçues. Ce format de communication nécessite de fixer certains paramètres identiquement à l’émission et à la réception :
- niveaux électriques ;
- débit symbole (en Bauds) ;
- longueur des trames ;
- signalétique de début et de fin de trame ;
- contrôle d’erreur.
Le premier item est fixé par une norme d’interconnexion électrique telle le standard RS-232. Les autres paramètres sont réglés par programmation de l’UART.

### 2.7.1 Fonctionnement du module UART

La structure du module UART est illustrée sur la figure 11. A l’émission, les données à transmettre sont écrites dans une pile FIFO à 4 emplacements. la donnée la plus ancienne dans la pile est mise en trame (ajout de la signalisation de start, de stop et de l’éventuel bit de parité) puis transférée dans le registre à décalage d’émission dès que ce dernier est vide. La trame est alors immédiatement transmise bit par bit sur TxD au rythme de l’horloge du Baud Rate Generator (BGR). Une interruption peut être déclenchée dès que la pile FIFO est vidée, ce qui permet à l’application de venir à nouveau la remplir.
A la réception du bit de start, le signal électrique acquis sur RxD est suréchantillonné à un rythme 16 fois plus rapide que l’horloge BGR pour pouvoir se synchroniser au mieux à l’émetteur et les données sont stockées dans le registre à décalage de réception. Lorsque la trame est complète et sans erreur, la donnée utile est transférée dans une FIFO à 4 emplacements et prète à être lue par le programme. Une interruption peut éventuellement être générée lors de l’occurrence de cet évènement.
Le fonctionnement de ce module est précisément décrit en section 19 du dsPIC30F Family reference
manual . (http://ww1.microchip.com/downloads/en/devicedoc/70046d.pdf)
M. COLAS | 11

Fcy; BRG; Tx shift register; Rx shift register; TxD; RxD; Tx FIFO Rx FIFO; Control reg.; Parity Start bit Stop bit

Fig. 11 : Fonctionnement du module UART

### 2.7.2 Programmation du module UART

Afin de faciliter la programmation du module, un ensemble de fonctions sont mises à votre disposition dans les fichiers uart_periph.c et uart_periph.h présents sur le Moodle du cours. Ainsi :
- serialInit(baudRate) permet d’initialiser la liaison UART sur les broches alternatives (broches 11 et 12 sur la figure 4) sans contrôle de parité et avec un débit fixé à baudRate ;
- serialCharReceived() retourne une valeur non nulle lorsqu’un ou plusieurs octets sont présents dans la FIFO de réception ;
- serialRead() lit un octet dans la FIFO de réception et supprime l’octet lu de cette pile ;
- serialWrite() écrit un octet dans la FIFO d’émission et attend la fin de transmission.
Cette librairie n’exploite pas le mécanisme d’interruption sur occurrence d’un évènement de réception : par conséquent le programme doit capter l’évènement de réception par polling.
M. COLAS | 12

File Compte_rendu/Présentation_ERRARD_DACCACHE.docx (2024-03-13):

I. Cahier des charges

1. Contexte du projet

Le but de ce projet est de réaliser un robot autonome qui pourra suivre une trajectoire à l’aide de marqueurs au sol et de corriger sa trajectoire selon les obstacles qu’il rencontre ou encore le décalage qu’il a suivant les marqueurs. Ce robot, doit interagir avec l’homme qu’on appelle IHM (Interactions Homme-Machine) :

- Boutons Marche/Arrêt,
- Affichage des informations en temps réel (position par rapport aux marqueurs, vitesse, par exemple)
- Choix d’une fonctionnalité dans un menu

2. Description du matériel

Pour mener à bien à bien ce projet, trois équipes vont travailler sur un sujet différent. Les trois sujets sont les suivants :

- Capteurs
- Moteurs
- IHM

Voici la liste du matériel pour chaque sujet :

Capteurs | Moteurs | IHM
Carte DsPic | Carte DsPic | Carte DsPic
Capteurs de position (photos diodes) IR TCRT 5000 | Moteur | 3 boutons
Capteurs d’obstacles (à ultrasons) : SRF 05 | BTN 8982 | Écran LCD: EA DOGM163W-A

Le sujet choisi par notre binôme est celui de l’IHM. Jusqu’à présent, nous avons réalisé les câblages sur la plaque à essai, les premiers programmes et la réalisation de la carte schématique sur Eagle. Chacune des réalisations est présentée dans les pages suivantes.

Dans un premier temps, voici le calendrier d’avancement de notre projet :

Date | Objectifs | Résultats | Membre
31/01 | Câblage de l’écran LCD et allumage du rétroéclairage. | Réussite. | C /M[^1]
02/02 | Affichage d’un message sur l’écran LCD. | Réussite. | C/M
07/02 | Branchement des boutons et résistances. | Branchement non convenable. | M
14/02 | Programmation des boutons et affichage de leurs états (appuyé ou relâché) sur l’écran. | Réussite + Correction du branchement des Boutons. | C/M
21/02 | Début sur Eagle : réalisation du schéma de la carte électronique. | Réussite sans capacités de découplage. | C/M
24/02 au 02/03 | Réalisation d’un programme « Menu » permettant de choisir une action à l’aide des boutons. (Vacances) | Erreur de construction du projet. | C
05/03 | Test du code « Menu » et correction. | Réussite. | C/M
06/03 | Correction du schéma électrique et début de réalisation de la carte. | Réussite + en cours de réalisation de la carte. | C/M

II. Câblage électronique et raccordement au Micro-crontrôleur

1. Connexion Ecran/Micro-contrôleur (µC)

Pour ce projet, l’écran LCD utilisé est le EA DOGM163W-A. Il est composé de 40 pins mais seulement 22 sont utilisés.


On peut lire sur la figure ci-dessous : C̅S̅B̅, RS, SDO et CLK qui correspondent à des pins du µC. Ces pins ont été choisis vu leur fonction de contrôle d’affichage. Afin d’éviter tout problème avec le RESET, le pin 40 à été mit au +5V et non relié au RB2 du µC. Afin d’éviter un tirage trop important en courant, le +5V nécessaire à l’éclairage de l’écran à être prit par la plaque à essai. Après lecture de la datasheet de cet écran, on y lit qu’il faut placer entre les pins 1, 2, 3, 4 une résistance de 30Ω. De plus, pour avoir une entrée non bruitée, on a branché 2 capacités de découplages, une électrochimique de 100µF en parallèle avec une en plastique de 100nF.

2. Connexion Boutons/Micro-contrôleur


Comme premier code nous avons affiché sur l’écran « Bonjour le monde ». Nous avons ensuite câblé les boutons sur les pins RE0, RE1, et RE2 du micro-contrôleur. Après câblage, nous avons codé les boutons afin d’afficher leur état sur l’écran LCD (cf figure suivante).

Dans notre cas R=10kΩ.

Nous avons choisi les pins RE0, RE1 et RE2 vu que ses pates ont une fonction d’interruption à des évènements externes. Dans le câblage des boutons nous avons retiré les résistances vues la présence de résistance (Pull-up resistors) dans le micro-contrôleur sur les pates RE0, RE1 et RE2.

3. Connexion avec les Micro-contrôleur des capteurs et du moteur

Pour finaliser la réalisation du schéma de la carte il nous restait à ajouter des supports de pins pour pouvoir brancher et connecter d’autres micro-contrôleurs avec la nôtre. Ceci a été realisé à l’aide de 2 connecteurs avec lesquels on a connecté les pates RC13(UA1TX) et RC14(U1ARX) de notre micro-contrôleur avec celui des capteurs et celui du moteur. La pâte RC13 va nous servir à envoyer des commandes au moteur et la pâte RC14 à recevoir des informations des capteurs.


II. Programmation

1. Affichage du message d’allumage


Afin d’avoir une interface simple on a programmé l’affichage d’un message de bienvenue qui dure 5 secondes afin de vérifier d’un premier temps que le programme fonctionne bien et d’informer l’utilisateur du démarrage de l’écran. Ce code, ci-contre, situé dans la fonction main, va nous permettre d’afficher le message du démarrage du programme.

2. Initialisation du menu


Nous avons créé une fonction menue qu’on a mis dans un fichier nommé « fonctions_sup.c ». Ensuite nous avons créé le fichier nommé « fonctions_sup.h » pour les prototypes des fonctions créées dans « fonctions_sup.c ». La première fonction qu’on a codée est la fonction ‘ delay_en_s(temps) ’. Cette fonction nous permet de créer un délai en seconde pour pouvoir bien visualiser les messages sur l’écran. Ensuite on a créé la fonction « menu_principale() » qui va nous permettre de faire la sélection des différentes options dans le menu. Lors du déclenchement de la fonction « menu_principale() », un message s’affichera pour indiquer à l’utilisateur qu’il est dans le menu. Ensuite l’utilisateur aura la possibilité de sélectionner une des 2 options dans le menu en utilisant le bouton rouge pour monter, le bouton noir pour descendre et le bouton bleu pour confirmer la sélection.

Fichier « fonction_sup.h »

Fonction délai en secondes dans « fonctions_supp .c »

Code dans « menu_principale() » qui affiche le message dans « fonctions_supp .c »

Code dans « menu_principale() » qui nous permet de sélectionné une option dans « fonctions_supp .c »

III. Conclusion

En conclusion, la réalisation de notre partie (IHM) est sur la bonne voie. Nous n'avons pas de retard dans notre planning. Actuellement, nous sommes en train de finaliser les dernières optimisations nécessaires dans la partie programmation, tandis que la carte est pratiquement achevée. De plus, le menu de l'IHM est en phase finale de développement. Nous sommes persuadés que ces dernières étapes seront menées à bien dans les délais impartis. Nous sommes impatients de présenter un produit final de qualité, prêt à être intégré harmonieusement dans le projet global du robot suiveur de ligne.

[^1] C : Christopher / M : Mathéo

DACCACHE Christopher EEA 0601 L3 EEA ERRARD Mathéo IHM Pilotage

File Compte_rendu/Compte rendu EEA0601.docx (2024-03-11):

# Compte Rendu de Travail Personnel


EEA0601 - TP Longue Durée Transdisciplinaire

Sujet : Interface Homme Machine d’un Robot Suiveur de Ligne

Réalisé par ERRARD Mathéo et DACCACHE Christopher

Enseignants responsables : COLAS Maxime et CARTON David

# Sommaire

No table of contents entries found.

# Introduction

EEA0601-TP Longue Durée Transdisciplinaire ERRARD-DACCACHE

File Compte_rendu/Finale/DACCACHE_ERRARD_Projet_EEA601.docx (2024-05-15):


Projet : Robot suiveur de ligne

Module EEA 0601

TP Transdisciplinaire Année 2023/2024

Sujet : Interface Homme Machine d’un Robot Suiveur de Ligne

Réalisé par ERRARD Mathéo et DACCACHE Christopher

Enseignants responsables : COLAS Maxime et CARTON David

# a. Description du matériel3

# b. Planning 4

  c. Câblage de l’afficheur5
  d. Câblage des boutons6
  e. Schéma électronique7
  f. Carte électronique8
  g. Premier programme9
  h. Programme Boutons 19
  i. Programme Boutons 2 10
  j. Programme Menu10
  k. Programme Paramètres Menu14
  l. Programme Acquisition Données Capteurs15
  m. Programme Envoi Correction Moteur16

Références18

Annexe19

SOMMAIR

Dans le cadre de la matière EEA0601, notre responsabilité consistait à concevoir un robot suiveur de ligne. Ce projet représente une opportunité précieuse d'appliquer les connaissances acquises tout au long de notre formation en électronique et en automatique. Pour mener à bien cette mission, le projet a été subdivisé en trois composantes distinctes :

- Motorisation
- Interface Homme-Machine (IHM)
- Capteurs

Chaque groupe a bénéficié de treize séances, dont dix encadrées et trois en autonomie, en plus des séances personnelles. Un planning détaillé des séances est présenté ultérieurement dans ce rapport.

L'objectif global du projet est de développer une solution technique complète pour un robot capable de suivre une trajectoire prédéfinie grâce à des capteurs à photodiodes. Muni de deux moteurs indépendants, il peut se déplacer de manière linéaire et angulaire en modifiant la vitesse de rotation des moteurs. Ainsi, par le biais de ces moteurs, il peut corriger sa position selon son décalage par rapport à la trajectoire voulue.

Notre binôme s'est focalisé sur la conception de l'interface Homme-Machine (IHM), un élément crucial facilitant la communication entre l'utilisateur et le robot. Notre objectif principal était de développer une interface intuitive et fonctionnelle, intégrant des éléments de contrôle permettant à l'utilisateur de communiquer efficacement avec le robot. Pour ce faire, nous avons travaillé avec trois boutons et un écran d'affichage, des composants clés utilisés pour configurer les paramètres du robot et définir ses actions.

Le succès de notre projet dépendra de la collaboration étroite entre les différentes équipes travaillant sur les différentes parties du robot. Nous devons assurer une intégration fluide de notre système IHM avec les systèmes de motorisation et de capteurs, garantissant ainsi le bon fonctionnement global du robot suiveur de ligne.

La présentation de notre travail sera articulée en trois parties principales. La première consistera à présenter le cahier des charges, le matériel utilisé ainsi qu’un planning d’avancement du projet. La deuxième partie décrira la partie électronique réalisée, tandis que la dernière partie expliquera la programmation et l'asservissement des moteurs.

I. Section Préliminaire

# a. Cahier des charges

    i) Concevoir et implémenter une interface homme-machine pour un robot suiveur de ligne afin de pouvoir configurer différents paramètres.
    ii) L’IHM doit être équipée de trois boutons, chaque bouton étant assigné à une fonction spécifique. Un écran d'affichage doit y être intégré, permettant à l'utilisateur de visualiser les paramètres du robot et de sélectionner différentes actions.
    iii) Afficher différentes informations telles que la vitesse du robot, les données des capteurs comme la distance par rapport à un obstacle ou encore sa déviation par rapport à la ligne. Mais également la sélection des actions à effectuer par le robot, comme une marche lente ou rapide ou encore la correction de trajectoire.
    iv) L'IHM doit être capable de recevoir et de traiter les données des capteurs du robot et de pouvoir envoyer des instructions aux moteurs du robot en fonction des informations reçues des capteurs et de la configuration que souhaite l'utilisateur.

# b. Description du matériel

Pour mener à bien à bien ce projet une liste du matériel nécessaire pour chaque partie a été établit :

Capteurs | Moteurs | IHM
Carte DsPic | Carte DsPic | Carte DsPic
Capteurs de position (photos diodes) IR TCRT 5000 | Moteur | 3 boutons de type DT6
Capteurs d’obstacles (à ultrasons) : SRF 05 | BTN 8982 | Ecran LCD : EA DOGM163W-A

Partie Interface Homme-Machine
Composants | Quantité
Boutons DT6 | 3
LCD (EA DOGM163W-A) | 1
Nape électrique (26 pates) | 1
Résistance (33ohm) | 1
Condensateur électrochimique (100µF) | 1
Condensateur électrique (100nF) | 1
CON-1X2 | 2

# c. Planning

Voici un tableau indiquant les dates et descriptions de toutes les séances réalisées (Encadrées et Autonomie).

Date | Descriptions | Membre
24/01 | Explication du projet par les professeurs. | C /M[^1]
31/01 | Câblage de l’écran LCD et allumage du rétroéclairage. | C /M
07/02 | Programmation : Affichage d’un message sur l’écran LCD. Branchement des boutons et leurs résistances. | C/M
14/02 | Programmation : Affichage de l’état des boutons (appuyé ou relâché) sur l’écran. | C/M
21/02 | Eagle : Ajout des librairies et réalisation du schéma de la carte électronique. Réalisation de la carte électronique. | C/M
24/02 au 02/03 | Programmation : « Menu » permet de choisir une action à l’aide des boutons. (Vacances). | C
06/03 | Eagle : Correction du schéma et de la carte électronique. Programmation : Correction du code « Menu ». | C/M
13/03 | Eagle : Routage des pistes. Modification du choix des pattes des boutons : utilisation des CN (port B) pour les interruptions. | C/M
20/03 | Eagle : Finalisation de la carte électronique. | C/M
27/03 | Perçage de la carte, test de continuité à l’ohmmètre et soudure. | C/M
03/04 | Programmations : Modification du programme en utilisant les interruptions sur les boutons. Ajout des structures (Keyboard et Menu) | C/M
10/04 | Changement de carte µC. Ajout de la fonction menu_principale() et affichage du menu demandé (Actions/ Paramètres/Affiche Etat) | C/M
17/04 | Programmation : on a géré la durée d’appui des boutons. Finalisation des sous menus et insertion des structures MenuItem et MenuValue | C/M
22/04 au 29/04 | Programmation : Fonction menu_principale() quasiment fini. Affichage d’un int qu’on peut modifier à l’aide des boutons (Vacances). | C/M
07/05 | Finalisation du menu avec paramétrages | C/M

Un total de 9 séances ont été réalisé en dehors des horaires de TP afin d’avancer le plus possible sur le projet.

Séances | Nombre de Séances | Travail Effectué
Encadré | 10 | Développement
Autonomie | 5 (2 vacances) | Tests et Développement
Supplémentaires | 9 | Tests

II. Conception électronique

# a. Câblage de l’afficheur

L’afficheur utilisé est écran LCD de référence EA DOGM163W-A de dimention 16x3. Il possède 24 pates de connection dont treize sont relié au +5V, cinq a la masse, quatre au microcontrôleur et deux non utilisé. Le branchement entre le micro-contrôleur et l’afficheur se fait par une nappe de 26 pates.

Selon les spécifications fournies dans la notice (document 10 en référence), pour activer l’écran (rétro-éclairage), il est nécessaire de connecter une résistance de 30Ω en parallèle avec les broches 1 et 20 vers le +5V, tel que représenté sur la figure ci-dessous. Dans notre cas, nous avons utilisé une résistance de 33Ω a cause de l’indisponibilité d’une resistance de 30Ω. Les pins 1 et 20 correspondent à des anodes et les pins 2 et 19 à des cathodes.


FIGURE 1 : Brochage de l’écran LCD

Pour les broches de communication RS, CSB, D6 et D7 celles-ci sont respectivement connectées aux broches RE0, RE1, RE3 et RE4. Initialement, nous avions sélectionné les broches RB pour cette fonctionnalité. Cependant, ce choix a été revu afin de réserver les broches RB pour le raccordement des boutons, ces broches représentant également les broches CN utilisées pour les interruptions. La broche 40, correspondant à la fonction RESET, a été relié au +5V plutôt qu'au port RE2, afin d'éviter toute interférence potentielle avec la fonction de réinitialisation.

Afin de maintenir une alimentation stable et minimiser les distorsions de tension d'entrée, deux condensateurs de découplage ont été installés en parallèle, à proximité des broches d'alimentation de l'écran. Le premier est un condensateur électrochimique de 100 µF, utilisé pour atténuer les variations lentes de tension sur l'alimentation. Le second est un condensateur en plastique de 100nF, destiné à lisser les fluctuations rapides de tension sur l'alimentation, assurant ainsi une tension stable sur une plage de fréquences élevées.

# b. Câblage des boutons

Pour le câblage de nos trois boutons DT6, nous avons inclus des résistances (10KΩ) en série avec ces derniers. Dans un circuit, ces boutons fonctionnent comme des interrupteurs, pouvant être configurés en tant qu'interrupteurs normalement ouverts ou normalement fermés, selon la configuration requise. La figure ci-dessous illustre les deux configurations possibles pour le câblage des boutons.


FIGURE 2 : CONFIGURATION BOUTON

Dans notre cas, nous avons opté pour la configuration de gauche. Dans cette configuration, les boutons sont normalement ouverts, ce qui signifie qu'ils renvoient un signal de 0V sur les broches auxquelles ils sont connectés lorsqu'ils ne sont pas enfoncés. Lorsqu'un bouton est enfoncé, il envoie un signal de 5V sur sa broche de connexion. La figure suivante nous résume ceci :


FIGURE 3 : LECTURE D’APPUI SUR UN BOUTON

Pour déterminer si un bouton est enfoncé ou non, il suffit de lire la valeur reçue sur la broche correspondante du microcontrôleur. Nos trois boutons sont de couleurs différentes : un rouge, un bleu et un noir, et leurs fonctions sont définies comme suit :

- Rouge (+) : Incrémenter des valeurs numériques ou de monter dans un menu ou sous-menu.
- Bleu (-) : Décrementer des valeurs numériques ou de descendre dans un menu ou sous-menu.
- Noir (entrée) : Valider une valeur ou sélectionner une entrée dans un menu ou sous-menu .

Ces boutons nous permettent de naviguer dans les menus et les sous-menus, de sélectionner des options et de valider des actions.

Ce cablage de boutons a été modifié, puisque le microcontroleur a des résistances intégrer aux pates RB appeler pull-up resistors. Ces resistances vont guarentire un état logique (0) lorsque le bouton n’est pas enfoncé.

  c. Schéma électronique


Après le câblage de l’écran ainsi que des boutons sur la plaque à essai, et après verification du bon fonctionnement de notre circuit, nous avons réalisé sur le logiciel Eagle le schéma de la carte électronique.

FIGURE 4 : SCHÉMA EAGLE


Pour pouvoir communiqué avec les autres microcontroleurs (capteurs et motorisaton) à l’aide d’une liaison RS232, nous avons donc placé deux connectiques Molex 22035025. L’un servira à recevoir des informations des capteurs et l’autre à envoyer des informations à la motorisation. L’image suivante nous montre comment se fait le branchement:


FIGURE 5 : CONNECTIQUES

La connexion se fait par les pattes UART du µC. La patte U1ATX sert à la réception de données et la patte U1ARX sert à la transmission de données.

# d. Carte électronique


Figure 6 : carte électronique finale

Après la conception du schéma électrique, le logiciel Eagle a permis la génération des composants à placer pour la fabrication de la carte. La réalisation de la carte s'est déroulée en trois étapes principales :

- Placement des composants :

Les composants ont été positionnés initialement de manière à faciliter l’utilisation des boutons, à optimiser la visibilité de l'écran et à simplifier le raccordement de la nappe et des connecteurs au microcontrôleur.

- Routage des pistes :

Lors de la conception du routage des pistes, une réorganisation de l'emplacement des condensateurs a été réalisée afin de les placer aussi près que possible de l'entrée d'alimentation de l'écran. Ceci visait à garantir une alimentation la plus stable possible en entrée, limitant ainsi les interférences et les distorsions du signal.

- Optimisation :

Des mesures d'optimisation ont été prises, notamment la création d'un plan de masse, la réduction de la longueur des pistes et la minimisation des angles droits. Ces actions visaient à atténuer les perturbations électromagnétiques potentielles et à améliorer la qualité globale du signal.

Enfin, des trous ont été prévus et dimensionnés pour permettre une fixation appropriée de la carte sur le support du robot, assurant ainsi une intégration harmonieuse dans le système global.

III. Conceptions informatiques

# a. Premier programme

Initialement, nous avons entamé la programmation et l'affichage d'un message simple afin de nous familiariser avec le logiciel. Nous avons choisi d'afficher le message "Bonjour le monde". La figure suivante correspond à l’organigramme de ce message.


InitLCD();

LCDDisplayOn();

LCDGoto(0,0);

LCDWriteStr("Bonjour le monde");

Figure 8 : Code du premier programme

Figure 7 : Organigramme du premier code

# b. Programme Boutons 1

Initialement, nous avons élaboré un code de test afin de vérifier le bon fonctionnement de la fonction detect_button_pressed(). L'organigramme de ce code est illustré dans la figure suivante. Par la suite, nous avons apporté des modifications à ce code afin de détecter et afficher l'appui sur un ou plusieurs boutons. Durant cette phase, nous avons commencé par programmer sans utiliser les interruptions.


Le programme de cet organigramme est présent dans la partie annexe (III.b.1)du compte rendu.

FIGURE 9 : Organigramme Programme Boutons 1

  c. Programme Boutons 2


Dans une deuxième étape, nous avons réécrit cette même fonction en utilisant des interruptions. L'utilisation des interruptions garantit une exécution plus fluide du programme. En plus de l'implémentation des interruptions, pour rendre le code plus structuré, nous avons utilisé une structure de type "typedef" déclarée globalement, qui enregistre l'état des trois boutons lors de l'interruption. La figure suivante illustre l'organigramme de ce code.

Figure 10 : Organigramme Programme Bouton 2

*Le programme de cet organigramme est présent dans la partie annexe (III.b.2).

  d. Programme Menu

Une fois la conception et les tests du programme de contrôle des boutons terminés, et leur bon fonctionnement confirmé, nous avons entrepris le développement du menu permettant l'interaction avec notre robot. Ce menu a été divisé en trois parties principales, chacune comprenant ses propres sous-parties. Dans sa première version, le menu était peu structuré et principalement implémenté à l'aide d'instructions conditionnelles "if" et "else if". Afin d'améliorer la lisibilité et la maintenabilité de notre code, nous avons décidé de restructurer notre programme en le dissociant de notre code principal. Pour ce faire, nous avons créé deux fichiers distincts : un fichier .c (fonctions_sup.c) et un fichier .h (fonctions_sup.h), où nous avons déplacé les fonctionnalités liées au menu.

fonctions_sup.c fonctions_sup.h mains.c

Ensuite, nous avons ajouté des structures "typedef" dans le fichier .h pour initialiser de manière plus structurée les différentes parties et sous-parties du menu de façon globale. La structure du menu est représentée par l'organigramme suivant (référence : Guide de réalisation du projet EEA0601.pdf) :


Figure 11 : Organigramme de la structure du menu

Les structures "typedef" qui renferment toutes les informations du menu ont été nommées "Menu, MenuItem, MenuValue". La structure Menu contient 5 types d'informations (titre, root, items, offset et selected), la structure MenuItem contient 4 types d'informations (label, action, type et checked) et enfin, la structure MenuValue contient 5 types d'informations (tuningValue, tunedValue, min, max et type). Le code d'initialisation des structures est présenté ci-dessous :

Lexique :


La structure Menu comprendra 8 sous-parties (root, action, param, affetat, manu, detec, PID et vit). Pour accéder aux paramètres de chaque Menu, la syntaxe sera la suivante : par exemple, « rootMenu.title = NULL ».

La structure MenuItem comportera 7 sous-parties (root, action, param, manu, detec, PID et vit). Pour accéder aux paramètres de chaque MenuItem, la syntaxe sera de la forme : par exemple, « rootItems[0].label = ‘Actions’ ».

La structure MenuValue comprendra 4 sous-parties (manu, dist, pid, vit). Pour accéder aux paramètres de chaque MenuValue, la syntaxe sera de la forme : par exemple, « distValue[0].tuningValue = 10 ».

Figure 12 : Programme initialisation Structures

*La definition de chaque valeur dans les structures Menu, MenuItem et MenuValue est expliquer en annexe (III.d.1).


Ensuite, nous avons créé une fonction void menu_principale() qui contient l'intégralité du code du menu. Après la création de cette fonction, nous avons initialisé toutes les structures du menu en leur attribuant leurs valeurs désignées. Voici ci-dessous un exemple de chaque structure:

Figure 13 : Exemple Initialisation des Structures

*Le code complete de l’initialisation des structures est en annexe (III.d.2).

*N.B : les #define ACTIONS ‘’Actions’’ sont appeler des macros

Après la création et l'initialisation de toutes les structures du menu, nous avons commencé à programmer l'affichage du menu sur l'écran LCD. Cette partie a été réalisée à l'aide d'une boucle "do while". Cette boucle comporte plusieurs niveaux, représentés par la variable "choix_menu", qui est de type "int". Cette variable peut prendre 3 valeurs : {0 = menu principal, 1 = sous-menu 1 (Actions, Paramètres et Aff. État), et 2 = sous-menu 2 (Mode Manuel, Détection obst., Réglage PID et Vitesse)}.

À chaque pression du bouton "entrer", si une option de sous-menu est sélectionnée par le curseur, "choix_menu" s'incrémente de 1. Si le curseur est positionné sur l'option "retour", "choix_menu" subit une décrémentation de 1. Si une modification de variable des paramètres est en cours et que le bouton "entrer" est pressé, "choix_menu" subit une décrémentation de 1 pour revenir au menu ou sous-menu précédent.

La fonction menu_principale(Keyboard *keyboard) prend comme paramètre une structure de type Keyboard. Cette structure nous permet d'utiliser les valeurs qu'elle contient pour détecter l'appui des boutons et assurer le bon fonctionnement fluide du menu.

*L’organigramme du menu sera réalisé d’une facon simplifier vue la grandeur et complexiter du code du menu.


Figure 14 : Organigramme Simplifié du Menu

*Le code complet du menu est en annexe (III.d.3).

Enfin, après la configuration et la programmation du menu, nous sommes capables de naviguer librement. La partie suivante est cruciale car c'est là que les données nécessaires au déplacement du robot entrent en jeu.

  e. Programme Paramètres Menu

Cette section de la programmation est intégrée dans le menu mais elle fait également partie du programme de correction de trajectoire. Les paramètres que nous devons spécifier avant de lancer le code de démarrage du robot sont les suivants :

- Distance d'Obstacle : Cette configuration nous permet de définir une distance maximale [0, distmax] à laquelle le robot doit corriger sa trajectoire avant de heurter l'obstacle.
- PID : Il comprend trois valeurs (facteur proportionnel, facteur intégrateur et facteur dérivatif). Ces trois valeurs sont utiles pour obtenir une réponse plus précise lors de la correction de la trajectoire du robot avec le moins de fluctuations possible.
- Vitesse : Cette valeur nous permet de définir la vitesse maximale pour la "Marche Rapide" et la "Marche Lente" dans le menu "Actions".


L’organigramme du programme des paramètres du menu est ci-dessous :

Figure 15 : Organigramme code paramètres du menu

* Le code complet du paramètrage du menu est en annexe (III.d.4).

Nous avons eu un problème concernant l’affichage de variable sur le menu, car la fonction d’affichage de l’écran ne prend qu’un paramètre de type « char ». Pour résoudre ce problème, nous avons créé une chaîne de caractères, « distance[]={'0','1','2','3','4','5','6','7','8','9'}, contenant les chiffres de 0 à 9, et nous avons configuré l'appui du bouton "+" pour incrémenter et l'appui du bouton "-" pour décrémenter l'indice de la chaîne de caractères "distance[]".

  f. Programme Acquisition Données Capteurs

Pour faciliter la communication entre notre microcontrôleur et celui des capteurs, nous connectons la broche U1ATX de notre microcontrôleur à la broche U1RTX de celui des capteurs. Après avoir établi cette liaison physique, il est nécessaire de programmer une interruption des deux parties à une fréquence égale afin de recevoir toutes les données envoyées. La période des signaux envoyés et reçus est de 100 ms.

Nous recevrons deux types de données : une valeur variant entre [-64, 64], qui représente l'information envoyée par les capteurs infrarouges, et une autre valeur variant entre [0, 127], qui correspond à la distance en centimètres entre le capteur ultrasonore et l'obstacle.

Les informations seront reçues sous forme binaire de taille 8 bits. Si le bit 7 est égal à 0, il s'agit de la donnée envoyée par les capteurs infrarouges, tandis que si le bit 7 est égal à 1, il s'agit de la donnée envoyée par le capteur ultrasonore.

Pour recevoir correctement ces informations et les stocker, nous devons créer une interruption au niveau du Timer3, qui s'active toutes les 100 ms et stocke l'information reçue des capteurs dans des variables qui seront mises à jour toutes les 100 ms.

Une fois les données du capteur stockées, il est nécessaire de les analyser et de générer une correction de trajectoire afin que le robot continue à suivre la ligne et évite de heurter des obstacles.

*La partie réception des informations n'a pas pu être réalisée en raison de contraintes de temps.

  g. Programme Envoi Correction Moteur

Pour permettre la communication entre notre microcontrôleur et celui du moteur, nous relions la broche U1RTX de notre microcontrôleur à la broche U1ATX de celui du moteur. Après avoir établi cette liaison physique, il est nécessaire de programmer une interruption des deux parties à une fréquence égale pour pouvoir envoyer la correction de la trajectoire sous forme de vitesse linéaire et de vitesse de rotation. La période des signaux envoyés et reçus est de 100 ms.

Les informations à envoyer seront déterminées à l'aide de l'algorithme écrit pour corriger la trajectoire du robot en fonction des données reçues par les capteurs. Une fois cette correction générée, nous la traduirons en vitesse linéaire et vitesse de rotation pour changer la direction du robot.

*L'algorithme de correction de trajectoire et le code des interruptions et de l'envoi des données aux moteurs n'ont pas été réalisés en raison de contraintes de temps.

IV. Conclusion

Après un investissement de 15 séances régulières et 9 supplémentaires dédiées, nous avons réussi à mettre en place le programme complet du menu, incluant le système de modification des paramètres. Le menu fonctionne de manière fluide et répond parfaitement à nos attentes. Cependant, nous avons été confrontés à une contrainte majeure : le temps. Malheureusement, cette contrainte ne nous a pas permis de finaliser notre contribution au projet à 100 %. En particulier, la mise en œuvre de la communication entre les cartes et la correction de trajectoire reste inachevée. Malgré cette limitation temporelle, nous avons consacré tous nos efforts à la conception de l'interface de communication homme-machine, tant du point de vue électronique que du point de vue programmation. Si nous avions disposé de plus de temps, nous aurions pu mener à bien ces aspects manquants du projet.

Références :

⁽¹⁾ Schema_de_la_carte_Dspic.pdf

⁽²⁾dspic30f4012-2010-02-23-maj-2018-03-21.pdf

⁽³⁾dsPIC30F_Family_Reference_Manual_-_70046E.pdf

⁽⁴⁾dsPIC30F4011-4012_Data_sheet_-_70135G.pdf

⁽⁵⁾16-bit_MCU_and_DSC_Programmer_s_Reference_Manual_-_70157F.pdf

⁽⁶⁾EEA0601 - Communications.pdf

⁽⁷⁾Guide de réalisation du projet EEA0601.pdf

⁽⁸⁾EEA0601 - Mode demploi synthétique du logiciel Eagle - 2022-2023.pdf

⁽⁹⁾EEA0601 - Principes de réalisation dune carte électronique - 2022-2023.pdf

⁽¹⁰⁾dog-me_DOG_SERIES_3.3V.pdf

Annexe:

Github : https://github.com/christopherdacc/Projet_EEA0601

II.b.1) Programme Boutons 1


II.b.2) Programme Boutons 2 (+Appuie de 2s detecter)

Keyboard *myKeyboardptr;

Keyboard myKeyboard;

void initCN(void)

{

CNEN1bits.CN2IE=1;

CNEN1bits.CN3IE=1;

CNEN1bits.CN4IE=1;

}

void CNInterruptEnable(void)

{

IFS0bits.CNIF=0;

IEC0bits.CNIE=1;

}

void __attribute__(( __interrupt__ ,__auto_psv__ )) _CNInterrupt(void) {

if(detect_button_press(1))

{

myKeyboardptr->upEdge=1;

myKeyboardptr->upState=1;

}

else if(!detect_button_press(1))

{

myKeyboardptr->upEdge=0;

myKeyboardptr->upState=0;

}

if(detect_button_press(2))

{

myKeyboardptr->downEdge=1;

myKeyboardptr->downState=1;

}

else if(!detect_button_press(2))

{

myKeyboardptr->downEdge=0;

myKeyboardptr->downState=0;

}

if(detect_button_press(3))

{

myKeyboardptr->enterEdge=1;

myKeyboardptr->enterState=1;

}

else if(!detect_button_press(3))

{

myKeyboardptr->enterEdge=0;

myKeyboardptr->enterState=0;

}

IFS0bits.CNIF=0;

}

#define BUTTON1_PIN PORTBbits.RB0

#define BUTTON2_PIN PORTBbits.RB1

#define BUTTON3_PIN PORTBbits.RB2

void init_pins() {

TRISBbits.TRISB0 = 1;

TRISBbits.TRISB1 = 1;

TRISBbits.TRISB2 = 1;

CNPU1bits.CN2PUE = 1;

CNPU1bits.CN3PUE = 1;

CNPU1bits.CN4PUE = 1;

}

int16_t main(void)

{

init_pins();

initTime();

initCN();

IFS0bits.CNIF=0;

CNInterruptEnable();

myKeyboardptr=&myKeyboard;

do{

Time tm7 = getTime();

while (myKeyboardptr->enterEdge==1)

{

LCDGoto(0,0);

LCDWriteStr("Button 1 = 1");

}

while (myKeyboardptr->downEdge==1)

{

LCDGoto(1,0);

LCDWriteStr("Button 2 = 1");

}

while (myKeyboardptr->upEdge==1)

{

LCDGoto(2,0);

LCDWriteStr("Button 3 = 1");

while(isTimeOver(tm7,2000)&&detect_button_press(1)){

LCDGoto(2,0);

LCDWriteStr("Button 3 = 2");

}

}

while(myKeyboardptr->downEdge==0&&myKeyboardptr->upEdge==0&&myKeyboardptr->enterEdge==0)

{

LCDGoto(0,0);

LCDWriteStr("Button 1 = 0");

LCDGoto(1,0);

LCDWriteStr("Button 2 = 0");

LCDGoto(2,0);

LCDWriteStr("Button 3 = 0");

}

}while(xxx==1);

while(1)

{

}

}

III.d.1) Explication des valeurs dans les structures Menu, MenuItem et MenuValue :

Structure Menu : (référence : Guide de réalisation du projet EEA0601.pdf)

– title représente le titre du menu. Il est insrit sur la première ligne entre crochets et ne peut se déplacer. Si le pointeur associé est nul, il n’y a pas de titre au menu et les trois lignes de l’afficheur sont alors utilisées pour présenter les items de menu

– root est un pointeur vers le menu parent ou celui vers lequel se brancher après appui sur la touche retour.

– items pointe sur le tableau des items du menu. Ils sont affichés à partir de la seconde ligne de l’écran (si un titre est présent) et dans leur ordre d’apparition. Les items non visibles peuvent être affichés à l’aide des touches + et - par scrolling. Par exemple, l’item d’indice 2 du menu [ Reglage PID ] n’est initialement pas visible. Un premier appui sur sur - déplace le curseur de sélection > devant l’item 1 (I: 000) puis un second appui remplace l’item d’indice 0 par celui d’indice 1 et l’item d’indice 1 (P: 000) par celui d’indice 2 (D: 000).

– offset mémorise le décalage vertical compté algébriquement (positif vers le haut) de l’item d’indice 0 par rapport à l’affichage initial du menu. Ainsi, suite aux opérations décrites ci- dessus, l’offset du menu vaut 1 .

– selected indique la ligne de l’élément sélectionné : dans l’exemple précédent, selected vaut 2.

Structure MenuItems :

– label est la chaine de caractère affichée à l’écran pour cette entrée du menu ;

– action est un pointeur dont la signification dépend de la valeur du champ type ;

– type peut prendre les valeurs suivantes : 0 : selectable, 1 : function, 2 : submenu ou 3:value. selectable désigne une entrée commutable par appui sur la touche entrée. Lors- qu’une telle entrée est active, elle est précédée d’une étoile (*) et d’une espace dans le cas contraire. function indique qu’action est un pointeur vers une fonction à exécuter sur appui de la touche entrée. submenu indique qu’action est un sous-menu à afficher sur appui de la touche entrée, enfin value indique une valeur numérique modifiable et dans ce cas, action pointe vers une structure de type MenuValue décrite ci-dessous.

– checked indique soit un item sélectionné (type selectable) ou une action engagée (type action).

Structure MenuValues:

• 0:direct : ce paramétrage indique une variable à évolution immédiate , i.e. dont la grandeur pilotée change instantanément lors du réglage ;

• 1:batch : ce paramétrage indique une variable dont l’évolution ne sera prise en compte qu’après appui sur la touche entrée.

tuningValue correspond à la valeur temporaire de la grandeur pilotée (mode batch). tunedValue est la variable abritant la grandeur pilotée. min et max indiquent respectivement les valeurs minimales et maximales admissibles sur la grandeur pilotée.

III.d.2) Code complete de l’initialisation des structures : Fichier fonctions_sup.h

#ifndef FONCTIONS_SUP_H

#define FONCTIONS_SUP_H

// forward declaration

typedef struct menu Menu;

typedef struct menuitem MenuItem;

typedef struct menuvalue MenuValue;

typedef struct{

int upState:2;

int downState:2;

int enterState:2;

int upEdge:2;

int downEdge:2;

int enterEdge:2;

}Keyboard;

struct menu{

char *title; //titre du menu

Menu *root; //menu precedent

MenuItem *items; //option du menu specifique

short offset:6; //decalage verticale de la selection

short selected:4; //indique l'option selectionner

};

struct menuitem{

char *label; //chaine de char pour l'option selectionner

void *action; //depend de type (si type=1 on execute une fonction/si 2 affiche submenu/si 3 on pointe vers MenuValue)

short type:2; //0=selectable, 1=action, 2=submenu, 3=value

short checked:1; //0=selectable, 1=action->(action, submenu, value)

};

struct menuvalue{

int tuningValue;

int *tunedValue;

int min;

int max;

short type; //0 la valeu change lors du changement, 1 la valeur change apres appuie sur entree

};

void menu_principale(Keyboard *keyboard);

int detect_button_press(int button);

void delay_en_s(float time);

void _wait10mus(unsigned int tenmus);

#endif

Fichier fonctions_sup.c:

int gauche=0,droite=0,regP=0,regI=0,regD=0,distObs=0,maxG=0,maxD=0;

int *distObsptr=&distObs,*regPptr=&regP,*regIptr=&regP,*regDptr=&regD,*maxGptr=&maxG,*maxDptr=&maxD;

Menu rootMenu,actionMenu,paramMenu,affetatMenu,manuMenu,detecMenu,PIDMenu,vitMenu;

void menu_principale(Keyboard *keyboard)

{

MenuValue manuValue[]={{0,0,0,100,0},{0,0,0,100,0}};

MenuValue distValue[]={{0,0,0,100,1}};

MenuValue pidValue[]={{0,0,0,100,1},{0,0,0,100,1},{0,0,0,100,1}};

MenuValue viteValue[]={{0,0,0,100,1},{0,0,0,100,1}};

// déclarer les items

MenuItem rootItems []={{ACTIONS,&actionMenu,2,0},{PARAMETRES,&paramMenu,2,0},{AFFETAT,&affetatMenu,2,0}};

MenuItem actionItems []={{MALENTE,NULL,1,1},{MARAPIDE,NULL,1,1},{MOMANUEL,&manuMenu,2,0},{RETOUR,&rootMenu,2,0}};

MenuItem paramItems []={{DEOBST,&detecMenu,2,0},{REGPID,&PIDMenu,2,0},{VITESSE,&vitMenu,2,0},{RETOUR,&rootMenu,2,0}};

MenuItem manuItems []={{GAUCHE,manuValue,3,0},{DROITE,manuValue,3,0},{RETOUR,&actionMenu,2,0}};

MenuItem detObsItems[]={{"Dist: ",distValue,3,0},{RETOUR,&paramMenu,2,0}};

MenuItem PIDItems[]={{"P: ",pidValue,3,0},{"I: ",pidValue,3,0},{"D: ",pidValue,3,0},{RETOUR,&paramMenu,2,0}};

MenuItem vitItems[]={{"Rapide: ",viteValue,3,0},{"Lent: ",viteValue,3,0},{RETOUR,&paramMenu,2,0}};

// déclarer les menus

//Menu Principale

rootMenu.title = NULL;

rootMenu.root =NULL;

rootMenu.items = rootItems;

rootMenu.selected = 0;

rootMenu.offset = 0;

//Menu Action

actionMenu.title = NULL;

actionMenu.root = &rootMenu;

actionMenu.items = actionItems;

actionMenu.selected = 0;

actionMenu.offset = 0;

//Menu Parametres

paramMenu.title = NULL;

paramMenu.root = &rootMenu;

paramMenu.items = paramItems;

paramMenu.selected = 0;

paramMenu.offset = 0;

//Menu Affiche Etat

affetatMenu.title = NULL;

affetatMenu.root = &rootMenu;

//affetatMenu.items = ;

affetatMenu.selected = 0;

affetatMenu.offset = 0;

//Menu Mode Manuel

manuMenu.title = "[Manuel]";

manuMenu.root = &actionMenu;

manuMenu.items = manuItems;

manuMenu.selected = 0;

manuMenu.offset = 0;

//Menu Detection Obstacles

detecMenu.title = "[Detec. Obs.]";

detecMenu.root = &paramMenu;

detecMenu.items = detObsItems;

detecMenu.selected = 0;

detecMenu.offset = 0;

//Menu PID

PIDMenu.title = "[Reglage PID]";

PIDMenu.root = &paramMenu;

PIDMenu.items = PIDItems;

PIDMenu.selected = 0;

PIDMenu.offset = 0;

//Menu Vitesse

vitMenu.title = "[Vitesse]";

vitMenu.root = &paramMenu;

vitMenu.items = vitItems;

vitMenu.selected = 0;

vitMenu.offset = 0;

}

III.d.3) Fichier fonction_sup.c

III.d.4) Fichier fonction_sup.c :

https://github.com/christopherdacc/Projet_EEA0601/blob/main/Programmation/modele.X/lib/fonctions_sup.c

[^1] C : Christopher / M : Mathéo

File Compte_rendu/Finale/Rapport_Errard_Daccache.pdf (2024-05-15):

# Projet : Robot suiveur de ligne

## Module EEA 0601


TP Transdisciplinaire Année 2023/2024

Sujet : Interface Homme Machine d’un Robot Suiveur de Ligne

Réalisé par ERRARD Mathéo et DACCACHE Christopher

Enseignants responsables : COLAS Maxime et CARTON David

# SOMMAIR


Dans le cadre de la matière EEA0601, notre responsabilité consistait à concevoir un robot suiveur de ligne. Ce projet représente une opportunité précieuse d'appliquer les connaissances acquises tout au long de notre formation en électronique et en automatique. Pour mener à bien cette mission, le projet a été subdivisé en trois composantes distinctes :

- Motorisation
- Interface Homme-Machine (IHM)
- Capteurs

Chaque groupe a bénéficié de treize séances, dont dix encadrées et trois en autonomie, en plus des séances personnelles. Un planning détaillé des séances est présenté ultérieurement dans ce rapport.

L'objectif global du projet est de développer une solution technique complète pour un robot capable de suivre une trajectoire prédéfinie grâce à des capteurs à photodiodes. Muni de deux moteurs indépendants, il peut se déplacer de manière linéaire et angulaire en modifiant la vitesse de rotation des moteurs. Ainsi, par le biais de ces moteurs, il peut corriger sa position selon son décalage par rapport à la trajectoire voulue.

Notre binôme s'est focalisé sur la conception de l'interface Homme-Machine (IHM), un élément crucial facilitant la communication entre l'utilisateur et le robot. Notre objectif principal était de développer une interface intuitive et fonctionnelle, intégrant des éléments de contrôle permettant à l'utilisateur de communiquer efficacement avec le robot. Pour ce faire, nous avons travaillé avec trois boutons et un écran d'affichage, des composants clés utilisés pour configurer les paramètres du robot et définir ses actions.

Le succès de notre projet dépendra de la collaboration étroite entre les différentes équipes travaillant sur les différentes parties du robot. Nous devons assurer une intégration fluide de notre système IHM avec les systèmes de motorisation et de capteurs, garantissant ainsi le bon fonctionnement global du robot suiveur de ligne.

La présentation de notre travail sera articulée en trois parties principales. La première consistera à présenter le cahier des charges, le matériel utilisé ainsi qu’un planning d’avancement du projet. La deuxième partie décrira la partie électronique réalisée, tandis que la dernière partie expliquera la programmation et l'asservissement des moteurs.

## I. Section Préliminaire

a. Cahier des charges
i) Concevoir et implémenter une interface homme-machine pour un robot suiveur de ligne afin de pouvoir configurer différents paramètres.

ii) L’IHM doit être équipée de trois boutons, chaque bouton étant assigné à une fonction spécifique. Un écran d'affichage doit y être intégré, permettant à l'utilisateur de visualiser les paramètres du robot et de sélectionner différentes actions.

iii) Afficher différentes informations telles que la vitesse du robot, les données des capteurs comme la distance par rapport à un obstacle ou encore sa déviation par rapport à la ligne. Mais également la sélection des actions à effectuer par le robot, comme une marche lente ou rapide ou encore la correction de trajectoire.

iv) L'IHM doit être capable de recevoir et de traiter les données des capteurs du robot et de pouvoir envoyer des instructions aux moteurs du robot en fonction des informations reçues des capteurs et de la configuration que souhaite l'utilisateur.

b. Description du matériel

Pour mener à bien à bien ce projet une liste du matériel nécessaire pour chaque partie a été établit :

Capteurs | Moteurs | IHM
Carte DsPic | Carte DsPic | Carte DsPic
Capteurs de position (photos diodes) IR TCRT 5000 | Moteur | 3 boutons de type DT6
Capteurs d’obstacles (à ultrasons) : SRF 05 | BTN 8982 | Ecran LCD : EA DOGM163W-A

Partie Interface Homme-Machine
Composants | Quantité
Boutons DT6 | 3
LCD (EA DOGM163W-A) | 1
Nape électrique (26 pates) | 1
Résistance (33ohm) | 1
Condensateur électrochimique (100µF) | 1
Condensateur électrique (100nF) | 1
CON-1X2 | 2

c. Planning

Voici un tableau indiquant les dates et descriptions de toutes les séances réalisées (Encadrées et Autonomie).

Date | Descriptions | Membre
24/01 | Explication du projet par les professeurs. | C /M¹
31/01 | Câblage de l’écran LCD et allumage du rétroéclairage. | C /M
07/02 | Programmation : Affichage d’un message sur l’écran LCD. Branchement des boutons et leurs résistances. | C/M
14/02 | Programmation : Affichage de l’état des boutons (appuyé ou relâché) sur l’écran. | C/M
21/02 | Eagle : Ajout des librairies et réalisation du schéma de la carte électronique. Réalisation de la carte électronique. | C/M
24/02 au 02/03 | Programmation : « Menu » permet de choisir une action à l’aide des boutons. (Vacances). | C
06/03 | Eagle : Correction du schéma et de la carte électronique. Programmation : Correction du code « Menu ». | C/M
13/03 | Eagle : Routage des pistes. Modification du choix des pattes des boutons : utilisation des CN (port B) pour les interruptions. | C/M
20/03 | Eagle : Finalisation de la carte électronique. | C/M
27/03 | Perçage de la carte, test de continuité à l’ohmmètre et soudure. | C/M
03/04 | Programmations : Modification du programme en utilisant les interruptions sur les boutons. Ajout des structures (Keyboard et Menu) | C/M
10/04 | Changement de carte µC. Ajout de la fonction menu_principale() et affichage du menu demandé (Actions/ Paramètres/Affiche Etat) | C/M
17/04 | Programmation : on a géré la durée d’appui des boutons. Finalisation des sous menus et insertion des structures MenuItem et MenuValue | C/M
22/04 au 29/04 | Programmation : Fonction menu_principale() quasiment fini. Affichage d’un int qu’on peut modifier à l’aide des boutons (Vacances). | C/M
07/05 | Finalisation du menu avec paramétrages | C/M

Un total de 9 séances ont été réalisé en dehors des horaires de TP afin d’avancer le plus possible sur le projet.

Séances | Nombre de Séances | Travail Effectué
Encadré | 10 | Développement
Autonomie | 5 (2 vacances) | Tests et Développement
Supplémentaires | 9 | Tests

1 C : Christopher / M : Mathéo

## II. Conception électronique

a. Câblage de l’afficheur

L’afficheur utilisé est écran LCD de référence EA DOGM163W-A de dimention 16x3. Il possède 24 pates de connection dont treize sont relié au +5V, cinq a la masse, quatre au microcontrôleur et deux non utilisé. Le branchement entre le micro-contrôleur et l’afficheur se fait par une nappe de 26 pates.

Selon les spécifications fournies dans la notice (document 10 en référence), pour activer l’écran (rétroéclairage), il est nécessaire de connecter une résistance de 30Ω en parallèle avec les broches 1 et 20 vers le +5V, tel que représenté sur la figure ci-dessous. Dans notre cas, nous avons utilisé une résistance de 33Ω a cause de l’indisponibilité d’une resistance de 30Ω. Les pins 1 et 20 correspondent à des anodes et les pins 2 et 19 à des cathodes.


FIGURE 1 : Brochage de l’écran LCD

Pour les broches de communication RS, CSB, D6 et D7 celles-ci sont respectivement connectées aux broches RE0, RE1, RE3 et RE4. Initialement, nous avions sélectionné les broches RB pour cette fonctionnalité. Cependant, ce choix a été revu afin de réserver les broches RB pour le raccordement des boutons, ces broches représentant également les broches CN utilisées pour les interruptions. La broche 40, correspondant à la fonction RESET, a été relié au +5V plutôt qu'au port RE2, afin d'éviter toute interférence potentielle avec la fonction de réinitialisation.

Afin de maintenir une alimentation stable et minimiser les distorsions de tension d'entrée, deux condensateurs de découplage ont été installés en parallèle, à proximité des broches d'alimentation de l'écran. Le premier est un condensateur électrochimique de 100 µF, utilisé pour atténuer les variations lentes de tension sur l'alimentation. Le second est un condensateur en plastique de 100nF, destiné à lisser les fluctuations rapides de tension sur l'alimentation, assurant ainsi une tension stable sur une plage de fréquences élevées.

b. Câblage des boutons

Pour le câblage de nos trois boutons DT6, nous avons inclus des résistances (10KΩ) en série avec ces derniers. Dans un circuit, ces boutons fonctionnent comme des interrupteurs, pouvant être configurés en tant qu'interrupteurs normalement ouverts ou normalement fermés, selon la configuration requise. La figure ci-dessous illustre les deux configurations possibles pour le câblage des boutons.


FIGURE 2 : CONFIGURATION BOUTON

Dans notre cas, nous avons opté pour la configuration de gauche. Dans cette configuration, les boutons sont normalement ouverts, ce qui signifie qu'ils renvoient un signal de 0V sur les broches auxquelles ils sont connectés lorsqu'ils ne sont pas enfoncés. Lorsqu'un bouton est enfoncé, il envoie un signal de 5V sur sa broche de connexion. La figure suivante nous résume ceci :


FIGURE 3 : LECTURE D’APPUI SUR UN BOUTON

Pour déterminer si un bouton est enfoncé ou non, il suffit de lire la valeur reçue sur la broche correspondante du microcontrôleur. Nos trois boutons sont de couleurs différentes : un rouge, un bleu et un noir, et leurs fonctions sont définies comme suit :

- Rouge (+) : Incrémenter des valeurs numériques ou de monter dans un menu ou sous-menu.
- Bleu (-) : Décrementer des valeurs numériques ou de descendre dans un menu ou sous-menu.
- Noir (entrée) : Valider une valeur ou sélectionner une entrée dans un menu ou sous-menu .

Ces boutons nous permettent de naviguer dans les menus et les sous-menus, de sélectionner des options et de valider des actions.

Ce cablage de boutons a été modifié, puisque le microcontroleur a des résistances intégrer aux pates RB appeler pull-up resistors. Ces resistances vont guarentire un état logique (0) lorsque le bouton n’est pas enfoncé.

c. Schéma électronique

Après le câblage de l’écran ainsi que des boutons sur la plaque à essai, et après verification du bon fonctionnement de notre circuit, nous avons réalisé sur le logiciel Eagle le schéma de la carte électronique.


FIGURE 4 : SCHÉMA EAGLE


Pour pouvoir communiqué avec les autres microcontroleurs (capteurs et motorisaton) à l’aide d’une liaison RS232, nous avons donc placé deux connectiques Molex 22035025. L’un servira à recevoir des informations des capteurs et l’autre à envoyer des informations à la motorisation. L’image suivante nous montre comment se fait le branchement:


FIGURE 5 : CONNECTIQUES

La connexion se fait par les pattes UART du µC. La patte U1ATX sert à la réception de données et la patte U1ARX sert à la transmission de données.

d. Carte électronique


Figure 6 : carte électronique finale

Après la conception du schéma électrique, le logiciel Eagle a permis la génération des composants à placer pour la fabrication de la carte. La réalisation de la carte s'est déroulée en trois étapes principales :

- Placement des composants :

Les composants ont été positionnés initialement de manière à faciliter l’utilisation des boutons, à optimiser la visibilité de l'écran et à simplifier le raccordement de la nappe et des connecteurs au microcontrôleur.

- Routage des pistes :

Lors de la conception du routage des pistes, une réorganisation de l'emplacement des condensateurs a été réalisée afin de les placer aussi près que possible de l'entrée d'alimentation de l'écran. Ceci visait à garantir une alimentation la plus stable possible en entrée, limitant ainsi les interférences et les distorsions du signal.

- Optimisation :

Des mesures d'optimisation ont été prises, notamment la création d'un plan de masse, la réduction de la longueur des pistes et la minimisation des angles droits. Ces actions visaient à atténuer les perturbations électromagnétiques potentielles et à améliorer la qualité globale du signal.

Enfin, des trous ont été prévus et dimensionnés pour permettre une fixation appropriée de la carte sur le support du robot, assurant ainsi une intégration harmonieuse dans le système global.
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

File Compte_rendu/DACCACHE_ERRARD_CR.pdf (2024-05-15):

DACCACHE Christopher | EEA 0601 | L3 EEA
ERRARD Mathéo | IHM Pilotage
I. Cahier des charges

### 1. Contexte du projet

Le but de ce projet est de réaliser un robot autonome qui pourra suivre une trajectoire à l’aide de marqueurs au sol et de corriger sa trajectoire selon les obstacles qu’il rencontre ou encore le décalage qu’il a suivant les marqueurs. Ce robot, doit interagir avec l’homme qu’on appelle IHM (Interactions Homme-Machine) :
- Boutons Marche/Arrêt,
- Affichage des informations en temps réel (position par rapport aux marqueurs, vitesse, par exemple)
- Choix d’une fonctionnalité dans un menu

### 2. Description du matériel

Pour mener à bien à bien ce projet, trois équipes vont travailler sur un sujet différent. Les trois sujets sont les suivant :
- Capteurs
- Moteurs
- IHM

Voici la liste du matériel pour chaque sujet :
Capteurs | Moteurs | IHM
Carte DsPic | Carte DsPic | Carte DsPic
Capteurs de position (photos diodes) IR TCRT 5000 | | 3 boutons
Capteurs d’obstacles (à ultrasons) : SRF 05 | | Écran LCD : EA DOGM163W-A

Le sujet choisit par mon binôme et moi est celui de l’IHM. Jusqu’à présent, nous avons réalisé les câblages sur la plaque à essai, les premiers programmes et la réalisation de la carte schématique sur Eagle. Chacune des réalisations sont présentés dans les pages suivantes.

Dans un premier temps, voici le calendrier d’avancement de notre projet :
Date | Objectifs | Résultats | Membre
31/01 | Câblage de l’écran LCD et allumage du rétroéclairage. | Réussite. | C /M¹
02/02 | Affichage d’un message sur l’écran LCD. | Réussite. | C/M
07/02 | Branchement des boutons et résistances. | Branchement non convenable. | M
14/02 | Programmation des boutons et affichage de leurs états (appuyé ou relâché) sur l’écran. | Réussite + Correction du branchement des Boutons. | C/M
21/02 | Début sur Eagle : réalisation du schéma de la carte électronique. | Réussite sans capacités de découplage. | C/M
24/02 au 02/03 | Réalisation d’un programme « Menu » permettant de choisir une action à l’aide des boutons. (Vacances) | Erreur de construction du projet. | C
05/03 | Test du code « Menu » et correction. | Réussite. | C/M
06/03 | Correction du schéma de la carte de la carte et début de réalisation de la carte. | Réussite + en cours de réalisation de la carte. | C/M

### 1 C : Christopher / M : Mathéo

II. Câblage électronique et raccordement au Micro-crontrôleur

### 1. Connexion Ecran/Micro-contrôleur (µC)

Pour ce projet, l’écran LCD utilisé est le EA DOGM163W-A. Il est composé de 40 pins mais seulement 22 sont utilisés.
On peut lire sur la figure ci-contre : C̅S̅B̅, RS, SDO et CLK qui correspondent à des pins du µC. Ces pins on été choisi vu leur fonction de contrôle d’affichage. Afin d’éviter tout problème avec le RESET, le pin 40 à été mit au +5V et non relié au RB2 du µC. Afin d’éviter un tirage trop important en courant, le +5V nécessaire à l’éclairage de l’écran à été prit par la plaque à essai. Après lecture de la datasheet de cet écran, on y lit qu’il faut placer entre les pins 1, 2, 3, 4 une résistance de 30Ω. De plus, pour avoir une entré non bruité, on a brancher 2 capacités de découplages, une electrochimique de 100µF en parallele avec une en plastique de 100nF.


### 2. Connexion Boutons/Micro-contrôleur

Comme premier code avons afficher sur l’écran « Bonjour le monde ». Nous avons ensuite câbler les boutons sur les pins RE0, RE1, et RE2 du micro-contrôleur. Après câblage, nous avons coder les boutons afin d’afficher leurs états sur l’écran LCD (cf figure suivante).

Dans notre cas R=10kΩ.


Nous avons choisi les pins RE0, RE1 et RE2 vu que ses pates ont une fonction d’interruption à des évènements externes. Dans le câblage des boutons nous avons retiré les résistances vues la prestance de résistances (Pull-up resistors) dans le micro-contrôleur sur les pates RE0, RE1 et RE2.

### 3. Connexion avec les Micro-contrôleur des capteurs et du moteur

Pour finalisé la realisation du schema de la carte il nous restait a ajouter des support de pins pour pouvoir brancher et connecté d’autre micro-contrôleurs avec la notre. Ceci a été realisé a l’aide de 2 connecteurs avec lesquels on a connectés les pates RC13(UA1TX) et RC14(U1ARX) de notre micro-contrôleur avec le micro-contrôleur des capteurs et celui du moteur. La pate RC13 va nous servire a envoyer des commandes au moteur et la pate RC14 a recevoir des informations des capteurs.


II. Programmation

### 1. Affichage du message d’allumage

Afin d’avoir une interface simple on a programmé l’affichage d’un message de bien venu qui dure 5 secondes afin de vérifier d’un premier temps que le programme fonctionne bien et d’informer l’utilisateur du démarrage de l’écran. Ce code, ci-dessous, situé dans la fonction main, va nous permettre d’afficher le message du démarrage du programme.
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

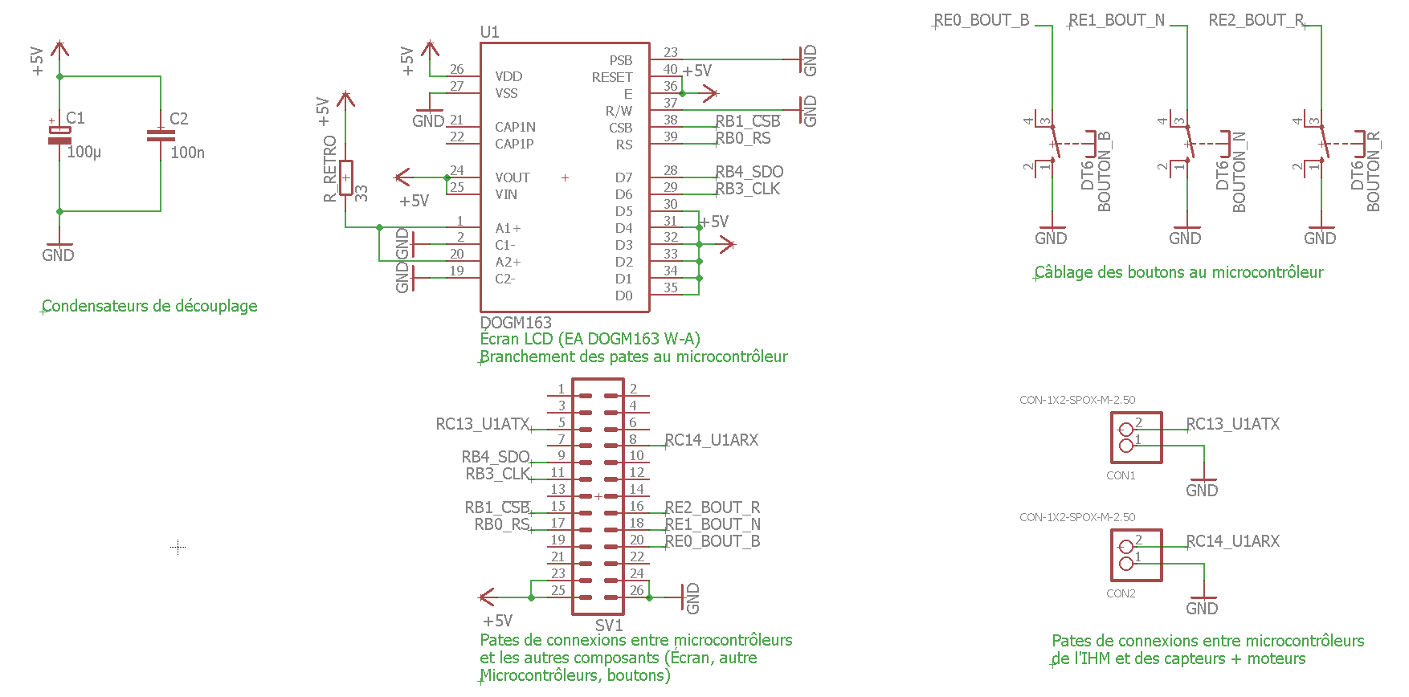
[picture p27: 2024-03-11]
Carte_eagle/carte_realise/Screenshot_schematics.PNG

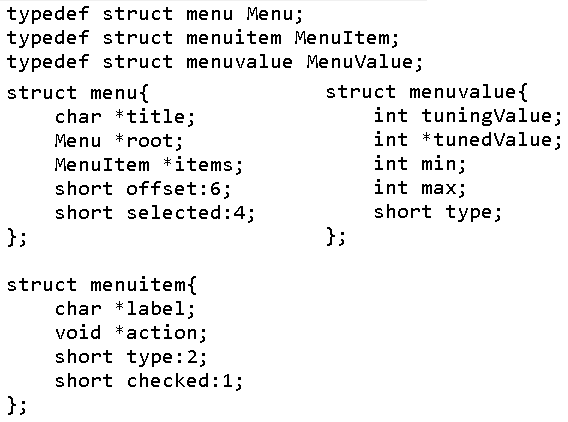
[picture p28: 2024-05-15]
Compte_rendu/pics and files/Finale/code structure menu.PNG

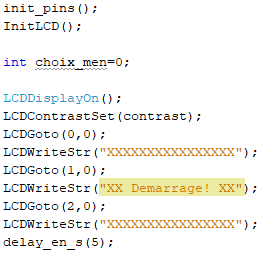
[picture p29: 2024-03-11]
Compte_rendu/pics and files/code/display demarrage.PNG

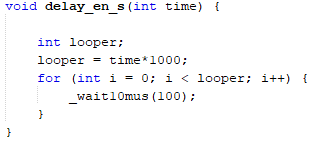
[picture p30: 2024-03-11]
Compte_rendu/pics and files/code/fonction delay.PNG

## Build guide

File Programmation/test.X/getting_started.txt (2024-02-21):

This is a general template for the dsPIC30 family of microcontrollers.  It's
purpose is to provide a project shell for users to get started designing their
own applications.  Final qualification and testing of this project is left to
the user.

ADVANCED USER TIP

From the main menu, refer to the Task list by going to Window > Tasks (Ctrl+6).
As long as the task window is not configured to filter out any tasks,
the getting started TODO list embedded in this project will be displayed.

Make sure the 'Show tasks for the main project and for the open projects which
depend on it' option is selected on the left hand side of the Tasks window so
that tasks related to other projects are not active.

HOW TO ADD YOUR OWN CODE TO A TEMPLATE

STEP 1

First install the appropriate C compiler if you have not done so already.

See www.microchip.com/compilers

Next, build this project by clicking the Clean and Build Icon (the hammer and
broom symbol) in the MPLAB X IDE Toolbar.  If this project builds, then you are
ready to make changes for your own application.  If the project does not build,
you need to troubleshoot why the project does not build before moving on.

STEP 2

Embed your device's configuration bits into the code.  Instructions for this
are commented in configuration_bits.c

STEP 3

Unless interrupts are not used in your application, add the interrupt vectors
you intend to use to interrupts.c.  Code stubs are provided in interrupts.c.
Make sure that you check the device datasheet to confirm that the interrupt
you are using is present in the device selected, and check the device .h
file for the most up to date list of interrupt vector mnemonics.

STEP 4

Define system parameters such as the system operating frequency in system.h.

Add system level functions to system.h and system.c.  For example, if
you want a function to determine the reset source of the device to know if you
need to backup data, do an oscillator switch, enter a low power mode, etc...
these types of functions may be added to system.c and prototypes can go in
system.h.

Refer to the oscillator chapter of the device FRM to learn about available
clock switching options as well as the compiler documentation for information
about compiler __builtins.  

STEP 5

Add user level functions to user.h and user.c.  User level functions are
functions that initialize I/O, initialize user peripherals like the ADC,
compute user algorithms, perform calculations on sampled user data, and so on.
User function prototypes and macros may be placed in user.h, and user
functions themselves may go in user.c

STEP 6

Add code to main.c on the line that says <INSERT USER APPLICATION CODE HERE>.
For example, here you would call functions in user.c or system.c, or possibly
setup your own state machine or primary code loop.

Global variables may be added to main.c as well.  As a general practice, macros
and prototypes may go in header files, but variable declarations should not
go in .h files.  Variable declarations should be placed in .c files.

STEP 7

Design the rest of your application.  Add new files to the application, and
test the finished product.

STEP 8

Document what the project does and include other project information in
project_information.txt.

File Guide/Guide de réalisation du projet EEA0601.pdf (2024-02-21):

EEA0601

L3 EEEA
année 2023-2024

TP transdisciplinaire en EEA Robot suiveur de ligne

## 1 Objectif

L’objet du TP longue durée transdisciplinaire est d’associer vos connaissances en électronique, en automatique et en programmation autour d’un projet de développement de robot autonome capable de suivre une trajectoire matérialisée par une ligne noire non nécessairement rectiligne tracée au sol (cette ligne est créée à l’aide de ruban adhésif standard). A tout moment, ce robot doit être capable de stopper son avancée s’il détecte un obstacle sur son chemin. Ce robot, construit sur la base d’une plateforme TRAXSTER II est présenté sur la figure 1.

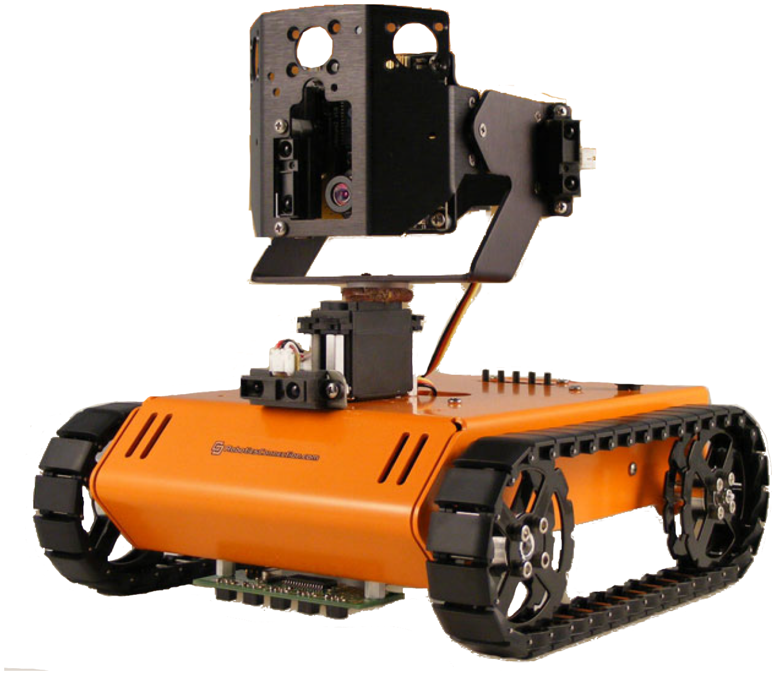
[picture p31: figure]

Fig. 1 : La plateforme roulante Traxster II

Ce document constitue une feuille de route destinée à fournir un support aux volets conception et programmation du projet. Il est découpé en 4 parties :

- principe de fonctionnement d’un microcontrôleur et de ses périphériques ;
- conception et programmation de l’acquisition et du traitement des données capteurs ;
- conception et programmation de la commande des moteurs ;
- conception et programmation d’une l’interface homme-machine et pilotage du robot.

La première partie (sections 2 et 3) est commune à l’ensemble du projet : elle doit être lue avec attention et comprise dès la première séance de la matière. Les sections 4, 5 et 6 constituent en revanche des sous-projets spécifiques et quasiment indépendants qui seront affectés lors de la première séance aux différents binômes du groupe. Toutefois, la lecture de la totalité du fascicule aidera à positionner chaque sous-projet dans son contexte global et n’est à ce titre pas facultative.
Lors de la première séance, chaque binôme du groupe se verra attribué la charge de réaliser un de ces sous-projets dans les 28 heures imparties. Le découpage du cahier des charges en trois sous-projets a pour objectif :
- de structurer le travail de chaque binôme et de le responsabiliser vis à vis des autres binômes et de l’enseignant ;
- de définir des interfaces minimales mais précises entre projets afin d’assurer leur indépendance mutuelle mais aussi de constituer des points de collaboration entre binômes de projets différents ;
M. COLAS/D. CARTON | 1

- de répartir la charge de travail afin de maximiser les chances d’aboutissement du projet ;

Chaque sous-projet est calibré afin de développer les mêmes compétences (réalisation électronique et programmation) et de présenter un niveau de complexité identique.

### 1.1 Description rapide et attributions relatives à chaque sous-projet

Comme illustré sur la figure 2, chaque sous-projet repose sur un contrôleur constitué d’une carte de programmation identique à base de microcontrôleur fournie lors de la première séance. En revanche, chaque binôme aura la charge de développer une carte électronique spécifique à sa partie et de programmer la carte micro-contrôleur pour atteindre l’objectif assigné. La carte à concevoir sera dotée :

- d’une nappe de connexion à la carte mirco-contrôleur ;
- selon le projet, de capteurs, d’une interface utilisateur ou d’organes de commande rapprochée ;
- d’une interface de communication permettant d’échanger des informations avec les autres sous-projets en vue d’aboutir à l’objectif global (le suivi de ligne).

Chaque sous-projet peut être mené indépendemment des autres car l’assemblage des réalisations en un projet complet repose sur la définition de deux interfaces — Capteurs→IHM et IHM→Moteurs — normalisées électriquement (liaison série sur niveaux TTL) et logiciellement (protocole d’échange présentés en section 4.3.2 et 5.5.1 .

Capteurs | IHM | Actionneurs
Carte µC | Carte µC | Carte µC
Carte capteurs | Carte moteursCarte IHM
Mesure | Commande

Param´etrage/Contrˆole

Utilisateur Ligne/obstacles | Moteurs

Fig. 2 : Découpage du projet en sous-projets

Les tâches propres à chaque sous-projet sont succinctement décrites ci-dessous :

Partie Capteurs

- Prototypage, test et calibrage des capteurs ;
- conception d’une carte électronique rassemblant les capteurs, leur électronique d’alimentation, l’interface de connexion à la carte micro-contrôleur, l’interface de communication avec la carte IHM ;
- implantation d’un algorithme élaborant la grandeur représentative de la distance entre le robot et un éventuel obstacle ;
- implantation d’un algorithme élaborant la grandeur représentative de la distance entre l’axe du robot et la ligne suivie ;
- encodage de ces deux valeurs selon le protocole imposé et transmission via une interface de communication filaire.
M. COLAS/D. CARTON | 2

Partie Interface (IHM)

- Prototypage et test de fonctionnement des éléments de l’interface homme-machine : écran LCD et boutons ;
- conception d’une carte électronique rassemblant l’IHM, l’interface de connexion à la carte microcontrôleur ainsi que les interfaces de communication avec la carte capteurs et la carte de commande des moteurs ;
- décodage des valeurs transmises par la carte capteur via une interface de communication filaire et selon un protocole imposé ;
- gestion de l’interface graphique et des boutons ;
- implantation de l’algorithme d’asservissement de la trajectoire du robot ;
- mise en place de la détection d’obstacle ;
- encodage des consignes de vitesse et d’orientation selon le protocole imposé et transmission vers la carte de commande des moteurs via une interface de communication filaire.

Partie actionneurs (Moteurs)

- Prototypage et test de fonctionnement des éléments de la commande rapprochée des moteurs ;
- cablage et acquisition des signaux issus des codeurs accouplés aux arbres moteurs ;
- conception d’une carte rassemblant l’électronique de commande des moteurs, les entrées d’information des codeurs, l’interface de connexion à la carte micro-contrôleur ainsi que l’interface de communication avec la carte IHM ;
- conversion des signaux issus des codeurs en une grandeur représentative des vitesses de rotation des moteurs ;
- décodage des consignes transmises par la carte IHM via une interface de communication filaire et selon un protocole imposé ;
- implantation de l’algorithme d’asservissement des vitesses de rotation des moteurs.

## 2 Structure d’un microcontrôleur

Un microcontrôleur est un composant associant dans un même boitier un coeur de microprocesseur, de la mémoire et des périphériques.

Microprocesseur : le microprocesseur a pour rôle d’éxécuter un programme composé d’une succession d’instructions rangées en mémoire. Pour cela, il dispose d’une unité de décodage d’instructions, d’une unité arithmétique et logique et de registres. Ces derniers sont destinés :

- à manipuler les données (registres de travail ou W) ;
- à indiquer l’état du processeur (registres SR) ;
- à pointer l’instruction à décoder (registre PC) ;
- ou à piloter le moteur DSP intégré au microprocesseur.

Dans un langage évolué tel que le C, les registres ne sont presque jamais manipulés par le programmeur.

M. COLAS/D. CARTON | 3

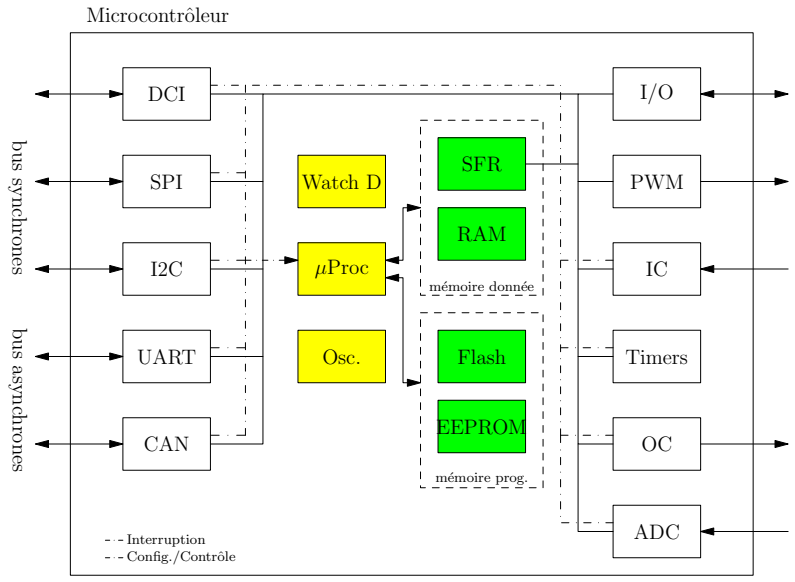
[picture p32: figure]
SFR; RAM; Flash; EEPROM; µProc; PWM; Timers; ADC; Osc.; Watch D; DCI; SPI; UART; CAN; m´emoire donn´ee; m´emoire prog.; bus synchrones bus asynchrones; Interruption Config./Contrˆole; Microcontrˆoleur

Fig. 3 : Structure interne d’un micro-contrôleur

Mémoire : la mémoire présente sur un microcontrôleur est utilisée différemment selon les architectures pour stocker programme et données. Dans le cas de la structure de type Harvard utilisée par Microchip, trois types de mémoires sont disponibles et utilisés comme suit :

- la RAM représente quelques ko de mémoire volatile : elle accueille les variables utilisées par le programme ;
- la FLASH représente quelques centaines de ko voire quelques Mo : elle accueille le programme ainsi que les données constantes. Cette mémoire est conservée en cas de perte de l’alimentation ;
- l’EEPROM est disponible pour stocker les données de configuration critiques d’un programme en cas de perte d’alimentation et les restituer au redémarrage. Généralement chaque microcontrôleur en embarque 1 ou 2 ko.

Les mémoires FLASH et l’EEPROM sont accédées par un bus de 24 bits permettant d’adresser potentiellement 16Mo appelés espace programme. l’espace programme est pointé par un registre qui dépile les instructions du programme appelé compteur programme ou PC. L’ensemble de cet espace d’adressage n’est pas uniquement occupé par du code programme ou par les données de l’EEPROM. Le début de la zone accueille la table des adresses des routines d’interruption et les 8Mo d’adresse haute sont réservés pour stocker quelques éléments tels l’identifiant du microcontrôleur ou ses bits de configuration. Finalement, la majorité de l’espace programme ne contient pas réellement de mémoire physique. Une grande partie des adresses sont inutilisées et pointent dans le vide.

Le microprocesseur accède à la mémoire RAM à l’aide d’un bus de données 16 bits qui ne permet d’adresser que 64ko de mémoire. Une partie de cet espace d’adressage (environ 2ko) est réservée pour accéder aux registres de périphériques appelés SFR (special function registers). Ces registres permettent de configurer et de piloter chacun des périphériques présents dans le microcontroleur. Le découpage des espaces mémoire est présenté sur la figure 4 dans le cas spécifique du pic30F4012.

Périphériques : Les périphériques intégrés au microcontrôleur sont nombreux et aux fonctionnalités multiples :

- interfaces dédiées aux bus de communications synchrones (SPI, DCI, I2C) ;
- interfaces dédiées aux bus de communication asynchrones (UART, CAN) ;
- entrées-sorties TTL ou à collecteur ouvert ;
- timers ;
M. COLAS/D. CARTON | 4

M´emoire donn´ees | M´emoire programme

0x0000

0x07FE
0x0800

0x1000

0x8000

0xFFFE

SFR

RAM dsPIC30F4012 (2ko)

Non utilis´e

Fenˆetre m´emoire prog.

Vecteurs
d’interruption

0x000000

0x0000FE

M´emoire prog. 48kInst.

Non utilis´e

EEPROM 1ko

Zone de config.

0x017FFE
0x018000

0x7FEFFE
0x7FF000

0x7FFFFE
0x800000

0xFFFFFE

Fig. 4 : Espaces d’adressage données et programme

- input-capture ;
- output-compare ;
- générateur de modulation de largeurs d’impulsions (PWM).

Grâce au mécanisme d’interruption décrit en section 3.1, chacun de ces périphériques est apte à indiquer au microprocesseur l’occurrence d’évènements nécessitant un traitement immédiat.

## 3 Structure d’un programme sur microcontrôleur

Les programmes implantés sur les microcontrôleurs possèdent tous la même structure : les actions périodiques ou déclenchées par les périphériques sont insérées au sein de routines d’interruption. Parmi ces actions, on peut citer :

- l’acquisition de valeurs analogiques à intervalle de temps régulier ;
- la lecture d’une valeur reçue sur un bus de communication ;
- la détection d’un front sur une entrée à fréquence élevée ou lorsque l’instant du front doit être consigné avec précision.

Les actions dont la prise en charge n’est pas urgente ou dont le traitement est long sont insérées dans une boucle sans fin. Il s’agit généralement des actions d’interaction avec un opérateur humain parmi lesquelles on trouve :

- la détection d’un appui sur un bouton (méthode de scrutation aussi appelée pooling) ;
- la mise à jour d’un afficheur LCD.
M. COLAS/D. CARTON | 5

### 3.1 Routines d’interruption

Une routine d’interruption est une fonction particulière qui ne prend pas de paramètre et qui ne retourne aucun résultat.Elle n’est jamais explicitement appelée par le programme mais son exécution est déclenchée sur évènement d’un périphérique (timer, réception d’un octet sur un bus de communication, fin de transmission d’un octet, fin de conversion analogique, détection d’un front, overflow de certains registres . . . )

Fonctionnement : Lorsqu’un périphérique souhaite signaler un évènement, un drapeau est positionné dans l’un des registres IFSx. L’interruption n’est appelée que si le programme l’a autorisée. A cet effet, les registre nommés IECx contiennent un ensemble de bits dont chacun est lié à une interruption autorisée (valeur à 1) ou non prise en compte (valeur à 0). Lorsque l’interruption est autorisée, le passage à 1 du drapeau correspondant du registre IFSx déclenche immédiatement les actions suivantes :

1. les contenus du pointeur d’exécution et du registre d’état sont mémorisés ;
2. le registre d’exécution (PC) est chargé avec l’adresse de la routine d’interruption qui s’éxécute immédiatement ;
3. après exécution de la dernière instruction de la routine, le pointeur d’exécution et l’état du processeur sont restitués automatiquement ;
4. l’exécution du programme principal reprend là où il avait été quitté.

Le code présent dans la routine est responsable de l’effacement du drapeau d’interruption (appelé acquittement) pour éviter une relance immédiate de l’interruption une fois la routine quittée ;
Pour le compilateur C30, chaque source d’interruption est liée à une routine grâce à son nom : ainsi l’interruption du timer 1 doit être nommée _T1Interrupt(), l’interruption indiquant la réception d’un octet sur l’UART se nomme _U1RXInterrupt(). . .

### 3.2 Structure type d’un programme

Le code d’un programme micro-contrôleur est usuellement organisé comme suit :

1. les routines d’interruptions sont définies ;
2. au sein de la fonction main, les périphériques sont initialisés, puis activés ;
3. les drapeaux d’interruptions (dans les registres IFSx) pour lesquels les routines ont été définies sont effacés par précaution afin d’éviter un départ non souhaité en interruption lié à un événement caduque ;
4. les sources d’interruptions pour lesquelles les routines ont été définies sont autorisées (i.e. demasquées) via les registres IECx ;
5. une boucle sans fin est ajoutée, vide si l’ensemble des actions est déclenchée sur interruption ou contenant les actions dont le traitement ne revet pas de caractère d’urgence.

Un tel code type est présenté ci-dessous et l’organigramme correspondant sur la figure 5. Comme le montre cette figure, une routine d’interruption doit toujours être traversant (i.e. non bloquante). De son coté, le programme principal se contente d’éxécuter des tâches non urgentes (Actions 1 et 2) après une phase d’initialisation. La communication de données entre les routines d’interruption et le corps du programme (main) est assurée par des variables globales, c’est à dire déclarées en dehors de tout corps de fonction.

1 | void __attribute__((__interrupt__,no_auto_psv)) _[Periph1Name]Interrupt( void ){
2 | ...

3
4 | IFSxbits.[Periph1Name]IF=0; | // Acquittement de l'interruption
5 | }

6
7 | ...
8 | void main(void){

9

M. COLAS/D. CARTON | 6

10 | init[Periph1Name]([Init args]); | // Appel des fonctions
11 | init[Periph2Name]([Init args]); | // d'initialisation des périphériques
12 | ...

13
14 | IFSxbits.[Periph1Name]IF=0; | // Acquittement préventif
15 | enable[Periph1Name]Interrupt(); | // Autorisation des interruptions
16 | | // déclenchées par Periph1
17 | ...
18 | while(1){
19 | if([Event]){
20 | [Low priority action]; | // Pooling sur évènements peu prioritaires
21 | }
22 | }
23 | }

24

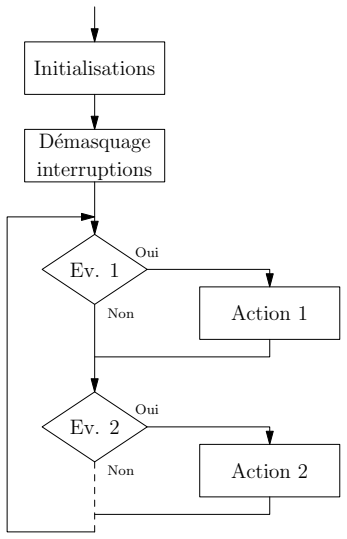
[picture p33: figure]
Initialisations; D´emasquage interruptions; Action 1; Action 2; Oui; Non

Action interrupt.

Acquittement

Programme principal

Routine d’interruption

´ev`enement IT

Fig. 5 : Organigramme d’un programme type sur micro-contrôleur

### 3.3 Les ports d’entrées-sorties (I/O)

Les broches d’un microcontrôleur sont généralement associées à différentes fonctionnalités multiplexées : le nom de la broche indique alors ces fonctionnalités par priorité décroissante. Ainsi, une broche AN7/RE8 est utilisée en entrée analogique dès lors que le module de conversion analogique est activé et que la programmation de la voie AN7 le prévoit. Selon cette nomenclature, le module I/O est généralement le moins prioritaire : il est donc important de vérifier qu’aucun périphérique ne masque ce module sur les broches devant être utilisées en I/O. Les entrées-sorties sont groupés en ports 16 bits (A0 à A15, B0 à B15, . . . ) et sont accessibles par des broches respectivement nommées RA0 à RA15, RB0 à RB15 ... Le nombre de broches dédiés aux I/O effectivement présentes sur un microcontrôleur dépend de sa taille et tous les bits d’un port ne sont pas nécessairement présents accessibles sous forme d’une broche. Par défaut, après reset du microcontrôleur, les broches configurées pour utiliser les ports d’entrées-sorties sont programmeés en entrées pour éviter d’imposer des tensions sur des broches connectées à des circuits externes fixant leur propre niveau de tension. Sur le dsPIC30F4012, il n’est pas possible de fournir ou d’absorber un courant supérieur à 25mA par broche avec une limite supérieure à 200mA pour l’ensemble du microcontrôleur.

M. COLAS/D. CARTON | 7

Programmation des ports d’entrées-sorties

Chaque bit d’un port est paramétrable en entrée ou en sortie individuellement. Pour cela, on utilise le registre TRISn où n indique le port (A, B C, ...). Un bit à 1 place de bit en entrée alors qu’un bit à 0 le programme en sortie. Une fois la direction du port choisie, on lit l’état électrique ou on écrit la valeur TTL à sortir sur la broche à l’aide du registre PORTn. Enfin, il est possible que l’état électrique d’une broche soit différent de l’état logique fixé par le programme (court-circuit, pilotage d’un circuit capacitif en fréquence élevée). Cet état logique peut alors être relu à l’aide du port LATn. La circuiterie interne des entrées-sorties est illustrée sur la figure 6 .

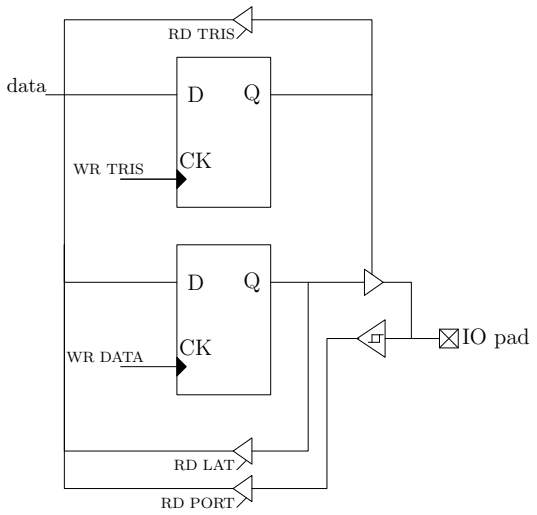
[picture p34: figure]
IO pad; data; WR DATA; WR TRIS; RD TRIS; RD LAT; RD PORT

Fig. 6 : Circuiterie des entrées-sorties

### 3.4 Les timers

Les timers sont des modules utilisés pour produire des actions à intervalle de temps constant ou pour mesurer des durées entre deux évènements successifs. Dans le premier cas, on parle du mode output-compare et dans le second de mode input-capture. Le dsPIC30F4012 dispose de 3 timers indépendants. Sur les microcontrôleurs Microchip, chacun de ces modes est mis en oeuvre en combinant un timer et un module spécifique au mode.

### 3.4.1 Utilisation du timer seul

Chaque timer est constitué d’un compteur de 16 bits permettant de balayer les valeurs de 0 à 65535. Le quantum temporel d’incrémentation est donné par le temps de cycle Tcy =

1

Fcy

où la fréquence de cycle
Fcy est donnée par :

Fcy =

7.372 × 106

4

MP LLHz

MP LL est un facteur multiplicatif programmable qui vaut au maximum 16. Ainsi on obtient la fréquence maximale Fcy = 29.488Mhz soit Tcy = 33ns.
A ce rythme, chaque compteur 16 bits atteint 65535 en 0,2ms, ce qui est un temps souvent trop court au regard des signaux à générer ou à mesurer. Pour allonger la durée de comptage, on peut exploiter deux pistes :
- cascader les timers 2 et 3 afin de produire un timer 32 bits et atteindre une durée de comptage pouvant atteindre de 145s ;
- ralentir l’horloge de comptage en divisant Fcy : c’est le rôle des prescalers.

Le fonctionnement du timer est le suivant (voir figure 7) :

1. le compteur 16 bits TMRi s’incrémente toutes les kTcy où k représente la valeur de prescaler ;
M. COLAS/D. CARTON | 8

2. lorsqu’il atteint la valeur cible définie dans le registre PRi :
- il est remis à 0 ;
- une demande d’interruption est levée ;
Fcy | Prescaler 1,8,64,256 | 16bits counter

TMRi

Target

PRi

=

reset

Interrupt

Fig. 7 : Utilisation d’un timer en générateur d’évènements périodiques

En mode 32 bits le fonctionnement est identique, la valeur finale de comptage est inscrite dans la concaténation des registres PR3 (mot de poids fort) et PR2 (mot de poids faible). le registre de comptage TMR3 est incrémenté sur overflow du registre de comptage TMR2. Lorsque TMR3:TMR2 = PR3:PR2, les registres de comptage sont remis à 0 et une demande d’interruption est levée émanant du Timer 3.

Programmation du Timer pour le déclenchement d’actions périodiques

Une librairie constituée des fichiers periph_tmr.c et periph_tmr.h, disponible sur votre environnement numérique de travail (Moodle du cours EEA0601) permet de simplifier le déclenchement d’actions à intervalles réguliers. Afin de répondre à la majorité des besoins, cette librairie exploite les timers 2 et 3 en mode 32 bits. Les fonctions disponibles sont :

- InitTimer3(unsigned long periode) permet d’initialiser le Timer3 en mode 32bits afin qu’il lève une demande d’interruption toute les 3, 39 × periodeµs avec periode ∈ {0, . . . , 2

32 − 1}.

- Timer3InterruptEnable(void) autorise le déclenchement d’interruptions par le Timer3 et active le comptage dans TMR3.

☞ Attention :

La définition de la routine d’interruption _T3Interrupt(void) est indispensable préalablement à l’utilisation de la fonction Timer3InterruptEnable(void) sous peine de plantage.

### 3.4.2 Mode output-compare

En association avec le module output-compare, un timer peut être utilisé pour activer une sortie TTL à chaque fois que le compteur atteint une valeur cible primaire inscrite dans le registre OCxR puis la désactiver lorsqu’il atteint une valeur cible secondaire inscrite dans le registre OCxSR. On peut ainsi générer des impulsions de durée variable et précise sans gestion logicielle ou même des PWM1
. Ce mode
n’étant généralement pas utilisé dans les projets d’EEA0601, il n’est pas décrit davantage ici.

### 3.4.3 Mode input-capture

En association avec le module input-capture, un timer est utilisé pour mesurer précisément l’intervalle de temps entre deux évènements sans scrutation logicielle. Le fonctionnement de ce mode est illustré sur la figure 8.
Sur l’occurrence d’un front sur la broche ICx, la valeur de comptage du Timer TMRy est instantanément mémorisé dans le registre ICxBUF. Le type de front détecté est paramétrable. Simultanément, l’exécution de la routine d’interruption ICxInterrupt est déclenchée (voir section 3.1) : cette routine a principalement pour objectif de traiter la valeur de comptage mémorisée du Timer y. Ainsi pour calculer la largeur

1cette dernière fonctionnalité est plus simple à implémenter au moyen du module PWM spécifique décrit en section 15 de la documentation de référence.

M. COLAS/D. CARTON | 9

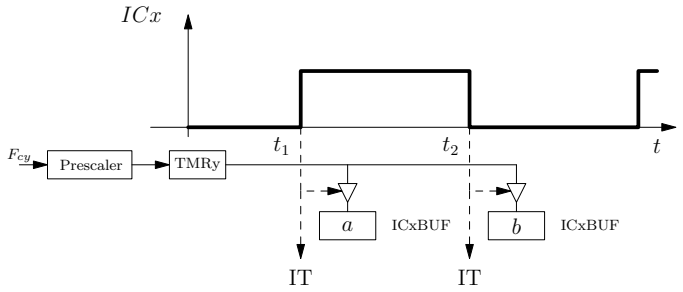
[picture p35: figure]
ICx; Prescaler; TMRy Fcy; ICxBUF

Fig. 8 : Fonctionnement du mode input-capture

∆t = t2 − t1 de l’impulsion rectangulaire illustrée sur la figure 8, on utilisera l’organigramme présenté sur la figure 9.

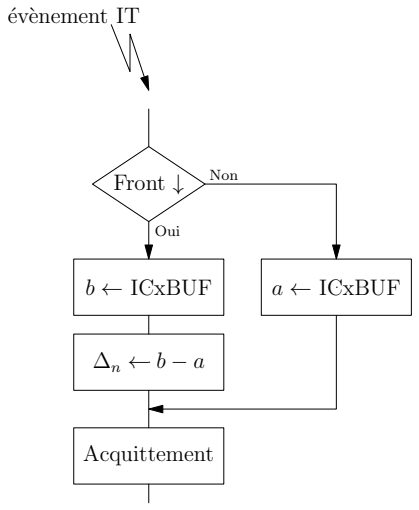
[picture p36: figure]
´ev`enement IT; Front ↓; Non; Oui; b ← ICxBUF; a ← ICxBUF; Acquittement

Fig. 9 : Détermination d’un intervalle de temps entre deux fronts (∆n est une image de ∆t)

Programmation du mode input-capture
Le mode input-capture est facilement utilisable grâce aux librairies periph_ic.c et periph_ic.h présentes sur votre environnement numérique de travail. Toutefois, il sera souvent nécessaire de compléter cette librairie afin de l’adapter aux spécificités de votre application. En particulier la gestion du timer destiné à horodater l’instant d’occurrence du front est laissé à la charge du développeur.
- ICxInterruptEnable(unsigned int edge) active la détection de fronts de type edge sur l’entrée ICx et autorise le déclenchement d’une interruption lors de l’occurrence de cet évènement. Sur un dsPic30F4012, x ∈ {7, 8}.

☞ Attention :

- La | définition | de | la | routine | d’interruption | _ICxInterrupt(void)
est | indispensable | préalablement | à | l’utilisation | de | la | fonction
ICxInterruptEnable(unsigned int edge) sous peine de plantage.
- Si vous êtes amené à modifier ou compléter la librairie, il est important de renommer les fichiers associés afin de ne pas confondre votre code avec sa version originale.
M. COLAS/D. CARTON | 10

### 3.4.4 Détermination de la valeur d’un prescaler

Comme expliqué précédemment, le prescaler a pour rôle de diviser la fréquence d’horloge Fcy et donc de ralentir la vitesse d’incrémentation des timers. Sa valeur doit être fixée en fonction :

- de la durée ∆t maximale souhaitée entre deux déclenchements d’actions successives ;
- de l’estimation de l’intervalle de temps maximum observable ∆t entre deux fronts successifs sur ICx en mode input-capture.

Dans les deux cas, le prescaler est choisi tel que :

P r > ∆tFcy
2

16

☞ Attention :

Dès lors que cette condition est respectée, il est préjudiciable de surévaluer la valeur du prescaler sous peine de perdre en résolution temporelle (incréments par seconde) : en particulier, la mesure d’intervalle entre 2 fronts rapprochés sur ICx peut devenir imprécise.

### 3.5 Le module de génération d’une modulation de largeur d’impulsion (MLI)

Le microcontrôleur dsPIC30F4012 intègre un module permettant de générer jusqu’à 6 signaux PWM (Pulse Width Modulation) de période commune dont les sorties sont couplées deux à deux. Le fonctionnement de ce module est précisément décrit en section 15 du dsPIC30F Family reference manual . (http://ww1.microchip.com/downloads/en/devicedoc/70046d.pdf)

### 3.5.1 Fonctionnement du module PWM

Chaque broche PWMxH et PWMxL, x∈ {1, 2, 3} peut au choix, être utilisée par le module PWM ou comme une I/O logique. La période de la modulation est commune aux PWM1, 2 et 3 et produite par un unique timer 16 bits programmable incrémenté au rythme Fcy
N

où N ∈ {1, 4, 16, 64} désigne une valeur de prescaler programmable. Dans le mode Edge aligned, l’ensemble des sorties PWMxH utilisées passent à l’état haut lorsque le compteur du timer PTMR atteint sa valeur finale . En revanche, chaque sortie passe à l’état bas lorsque le timer atteint une valeur spécifiée dans le registre DCYx pour cette voie comme le montre la figure 10 . Ce fonctionnement permet de générer un signal MLI de période et de rapport cyclique souhaités. Lorsque des voies PWMxL sont utilisées par le module PWM, elles prennent des valeurs complémentaires aux voies PWMxH associées à moins que le mode independent output n’ait été explicitement requis. Ce fonctionnement complémenté facilite la commande des hacheurs en interdisant aux transistors haut et bas d’un même bras de pont d’être simultanément passant ou bloqué (avec l’adjonction d’un éventuel

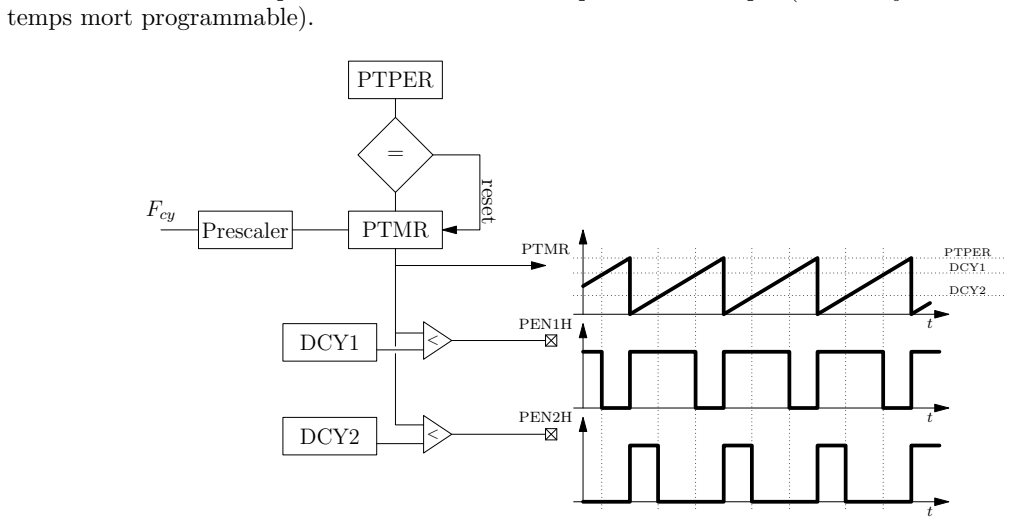
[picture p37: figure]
temps mort programmable).; PTPER; Prescaler; PTMR; Fcy; reset; DCY1; DCY2; PEN1H; PEN2H

Fig. 10 : Fonctionnement du module PWM

M. COLAS/D. CARTON | 11

### 3.5.2 Programmation du module PWM

Les fichiers periph_pwm.c et periph_pwm.h présents sur le cours Moodle offrent une librairie de fonctions de base permettant de programmer le module PWM. Les fonctions disponibles sont :

- InitPWM(unsigned int periode,enum PWM_PIN_INIT_FLAGS PIN_Init) : initialise le module PWM pour un signal de période periode×2.17µs. PWM_PIN_INIT_FLAGS PIN_Init fixe les broches à utiliser pour la PWM et doit être choisi selon une combinaison logique de PEN1L, PEN2L, PEN3L, PEN1H, PEN2H et PEN3H. Il est aussi possible de dissocier les broches L et H de la voie i (independant mode) en adjoignant l’élément INDEPi.

Ainsi InitPWM(460,PEN1L&PEN1H) initialise une PWM de période 1ms dont les sorties sont en opposition sur PEN1L et PEN1H.

- PWMEnable(enum MOD_ENABLE onoff) : active ou éteint le module PWM.
- PWM1PulseWidth(unsigned int Ton) : fixe le rapport cyclique sur la voie 1 selon α =

Ton
periode.
- PWM2PulseWidth(unsigned int Ton) : fixe le rapport cyclique sur la voie 2.

### 3.6 Le module de conversion analogique-numérique

Le dsPIC30F4012 possède 9 entrées analogiques multiplexées vers quatre échantillonneurs bloqueurs étiquetés CH0 à CH3. Les sorties de ces bloqueurs sont quantifiées séquentiellement sur 10 bits par un unique convertisseur analogique-numérique à approximations successives. L’étendue de mesure des données converties est paramétrable :

- soit entre AVSS et AVDD (images filtrées de la tension d’alimentation du microcontrôleur) i.e. entre 0 et 5V ;
- soit entre Vref- et Vref+ qui doivent cependant rester tels que AVSS < Vref- < Vref+ < AVDD.

Comme présenté sur la figure 11, le multiplexeur 1 permet de choisir les voies à numériser, en mode single ended (référencées à la masse) ou différentiel (différence de potentiel entre deux ANx). Toutes les combinaisons d’entrées ne sont pas disponibles et on se référera à la documentation du microcontrôleur
- (http://ww1.microchip.com/downloads/en/devicedoc/70046e.pdf) pour plus de détails. Lorsque les entrées à numériser sont connectées à différents bloqueurs, cela rend possible l’acquisition d’une image simultanée des tensions présentes sur ces entrées. L’unique convertisseur analogique-numérique est alors successivement connecté à chaque bloqueur pour afin de quantifier les tensions bloquées. Les valeurs converties sont ensuite stockées dans les registres ADCBUFx, x ∈ {0, · · · 15}. Selon la programmation du module, il est possible de numériser en séquence une même voie ou plusieurs voies bloquées simultanément. De même les registres ADCBUFx peuvent être utilisés comme une FIFO ou au contraire en correspondance (stockage de la valeur associée à ANi dans ADCBUFi.

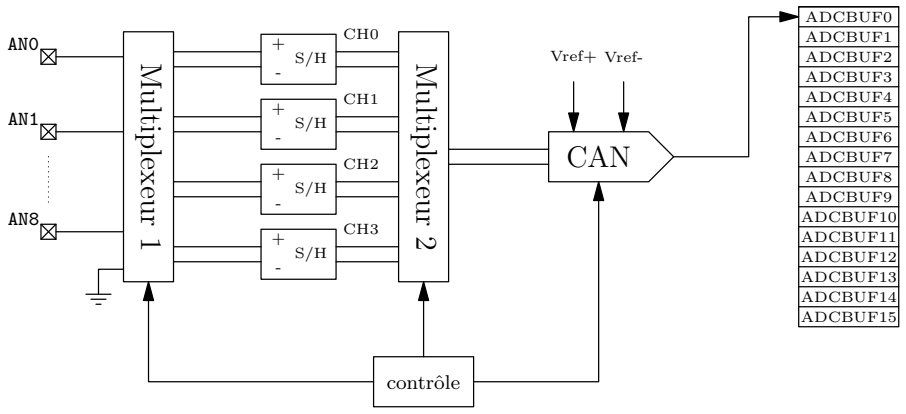
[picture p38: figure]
Multiplexeur 1; Multiplexeur 2; CAN; Vref+ Vref-; contrˆole; ADCBUF15; ADCBUF14; ADCBUF13; ADCBUF12; ADCBUF11; ADCBUF10; ADCBUF9; ADCBUF8; ADCBUF7; ADCBUF6; ADCBUF5; ADCBUF4; ADCBUF3; ADCBUF2; ADCBUF1; ADCBUF0

Fig. 11 : Fonctionnement du module de conversion analogique-numérique

M. COLAS/D. CARTON | 12

### 3.6.1 Programmation du module de conversion analogique-numérique

La programmation du module de conversion analogique-numérique est grandement facilitée par la librairie constituée des fichiers periph_adc.c et periph_adc.h présents sur le cours Moodle de la matière. Les fonctions fournies sont les suivantes :

- InitADC0(void), InitADC0and1(void), InitADC4and5(void) et InitADC0to3(void) sont destinées à initialiser le module pour une acquisition simultanée sur les voies AN indiquées.
- StartADC0(unsigned int* ADCxValue0) bloque la valeur analogique présente sur AN0 puis lance la quantification de la voie bloquée et attend la fin de conversion. Le résultat est stocké dans la variable ADCxValue0 qui doit être déclarée préalablement à l’appel de la fonction (passage par adresse).
- StartADC0to3(unsigned int* ADCxValue0, unsigned int* ADCxValue1, unsigned int* ADCxValue2, unsigned int* ADCxValue3) bloque simultanément les valeurs analogiques présentes sur ANi
i ∈ {0, 1, 2, 3} puis lance successivement la conversion de chaque voie bloquée et attend la fin de l’ensemble des conversions. Les résultats sont stockés dans les variables ADCxValuei, i ∈ {0, 1, 2, 3}
qui doivent être déclarée préalablement à l’appel de la fonction (passage par adresse).
- StartADC0seq0to4(unsigned int* ADCxValue0, unsigned int* ADCxValue1, unsigned int* ADCxValue2, unsigned int* ADCxValue3, unsigned int* ADCxValue4) bloque et convertit successivement les entrées AN0 à AN4.

### 3.7 Le module de communication série asynchrone

Le module UART (Universal Asynchronous Receiver Transmitter ) est un contrôleur de communication série présent dans de très nombreux équipements (microcontrôleurs, PC, automates, appareillage de mesure . . . ) et habituellement associé au standard RS-232. Une communication asynchrone série consiste en l’envoi successif de valeurs binaires transcodées en impulsions électriques sur une paire filaire ou un canal hertzien. Le caractère asynchrone de cette communication provient du fait que le signal d’horloge cadençant la communication n’est pas transmis en parallèle des données : cette horloge doit être reconstituée coté réception à l’aide d’informations a priori communes à l’émetteur et au récepteur (le débit par exemple) ou/et de l’observation des trames reçues. Ce format de communication nécessite donc de fixer certains paramètres identiquement à l’émission et à la réception :

- niveaux et modes électriques ;
- débit symbole (en Bauds) ;
- longueur des trames ;
- signalétique de début et de fin de trame ;
- contrôle d’erreur.

Le premier item est fixé par une norme d’interconnexion électrique telle le standard RS-232. Les autres paramètres sont réglés par programmation de l’UART.

### 3.7.1 Fonctionnement du module UART

A l’émission, les données à transmettre sont écrites dans une pile FIFO à 4 emplacements. la donnée la plus ancienne dans la pile est mise en trame (ajout de la signalisation de start, de stop et de l’éventuel bit de parité) puis transférée dans le registre à décalage d’émission dès que ce dernier est vide. La trame est alors immédiatement transmise bit par bit sur TxD au rythme de l’horloge du Baud Rate Generator (BRG). Une interruption peut être déclanchée dès que la pile FIFO est vidée, ce qui permet à l’application de venir à nouveau la remplir.
A la réception du bit de start, le signal électrique acquis sur RxD est suréchantillonné à un rythme 16 fois plus rapide que l’horloge BRG pour pouvoir se synchroniser au mieux à l’émetteur et les données sont stockées dans le registre à décalage de réception. Lorsque la trame est complète et sans erreur, la donnée utile est transférée dans une FIFO à 4 emplacements et prète à être lue par le programme. Une interruption peut éventuellement être générée lors de l’occurrence de cet évènement.
Le fonctionnement de ce module est précisément décrit en section 19 du dsPIC30F Family reference manual . (http://ww1.microchip.com/downloads/en/devicedoc/70046d.pdf)
M. COLAS/D. CARTON | 13

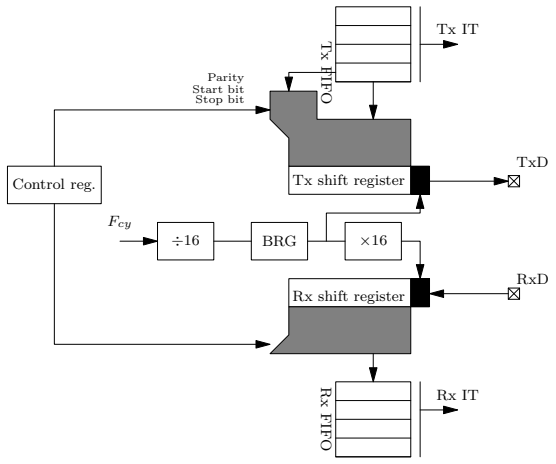
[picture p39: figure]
Fcy; BRG; Tx shift register; Rx shift register; TxD; RxD; Tx FIFO Rx FIFO; Control reg.; Parity Start bit Stop bit

Fig. 12 : Fonctionnement du module UART

### 3.7.2 Programmation du module UART

Afin de faciliter la programmation du module, un ensemble de fonctions est mise à votre disposition dans les fichiers periph_uart.c et periph_uart.h présents sur le Moodle du cours. Ainsi :

- serialInit(baudRate) permet d’initialiser la liaison UART sur les broches alternatives (voir datasheet du dsPIC30f4012) sans contrôle de parité et avec un débit fixé à baudRate ;
- serialCharReceived() retourne une valeur non nulle lorsqu’un ou plusieurs octets sont présents dans la FIFO de réception ;
- serialRead() lit un octet dans la FIFO de réception ;
- serialWrite() écrit un octet dans la FIFO d’émission.

Cette librairie n’exploite pas le mécanisme d’interruption sur occurrence d’un évènement de réception : par conséquent le programme doit capteur l’évènement de réception par polling.

### 3.8 Le module de communication série synchrone

Le module de communication série synchrone (SPI ou Serial Peripherical Interface), transmet ou/et reçoit des données au format 8 ou 16bits via un bus comportant quatre signaux :

- SDI qui porte le signal des données série entrant dans le module ;
- SDO qui porte le signal des données série sortant du module ;
- SS qui selectionne le module sur le bus ;
- CLK qui cadence le transfert des données.

Un bus SPI dont la connexion est présentée sur la figure 13, peut accueillir un maitre et autant d’esclaves que souhaité. Le maître a la responsabilité de générer l’horloge CLK et de sélectionner le ou les esclaves émetteurs ou destinataires des données du bus. Cette sélection est opérée en plaçant à 0V la ligne SS de chaque esclave à sélectionner durant le temps de la transmission. Cette dernière s’opère bit par bit, poids fort en premier au rythme de l’horloge CLK qui peut atteindre plusieurs MHz et doit rester inférieur à celui du module le plus lent.

### 3.8.1 Fonctionnement du module de communication série synchrone

Le module SPI dont le fonctionnement est précisé en détail en section 20 du dsPIC30F Family reference manual , (http://ww1.microchip.com/downloads/en/devicedoc/70046d.pdf) comporte principalement un registre à décalage SPIxSR configurable en 8 ou 16 bits et pour lequel chaque coup d’horloge CLK provoque le décalage à droite d’un bit de son contenu. Le bit de poids fort sortant du registre est transmis sur SDO alors que le bit de poids faible entrant provient de l’échantillonnage de SDI (voir figure 14).

M. COLAS/D. CARTON | 14

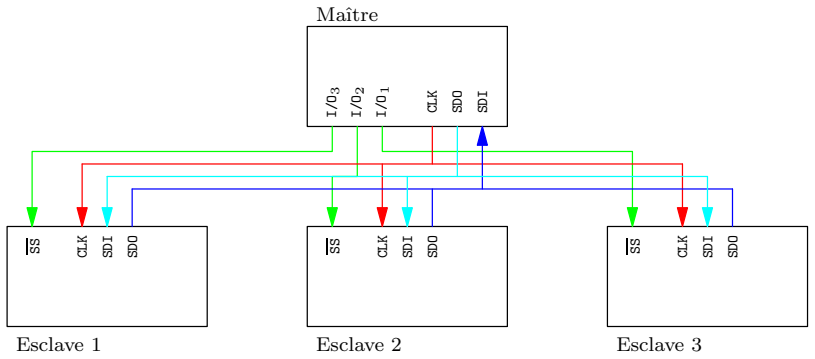
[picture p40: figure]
Maˆıtre; Esclave 3Esclave 2Esclave 1; CLK; SDO; SDI I/O1 I/O2 I/O3; SDI

Fig. 13 : Connexion du bus SPI

Lorsque le dsPIC est maître et le module est activé, l’écriture dans le registre SPIxBUF stocke d’abord la donnée à transmettre dans un registre de latch (SPIxTXB non directement accessible) puis cette donnée initialise le contenu de SPIxSR dès la fin de transmission précédente puis provoque la génération de 8 ou 16 périodes d’horloge (selon le mode 8/16 bits) et donc l’envoi du mot contenu dans le registre sur SDO, bit par bit. Simultanément, le niveau TTL présent sur SDI est acquis et stocké.
Contrairement au bus série asynchrone, la transmission de l’horloge par le maître sur le bus évite au récepteur d’avoir à connaitre a priori la fréquence de l’horloge. En revanche, la polarité initiale et le type de front d’horloge provoquant l’émission d’un bit doivent être identiques pour l’ensemble des modules présents sur le bus.
A l’issue de la transmission, une interruption peut être déclenchée pour indiquer cet évènement. Les 8 ou 16 bits reçus sur SDI sont accessibles par la lecture de SPIxBUF qui retourne les données latchées dans un registre de réception (SPIxRXB non directement accessible). Il est à noter que les données reçues sur l’entrée SDI restent disponibles à la lecture y compris durant la réception de la transmission suivante, ce qui permet d’accélerer les échanges. Evidemment l’achèvement d’une transmission écrase immédiatement

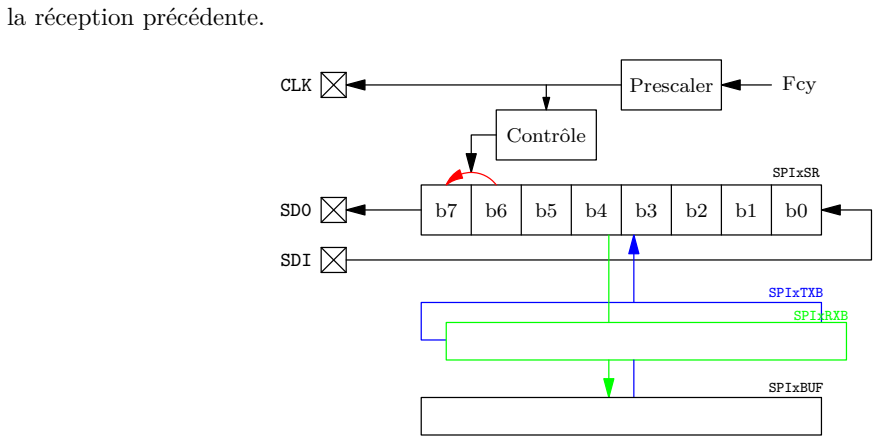
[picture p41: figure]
la réception précédente.; SDI; CLK; Prescaler; Fcy; Contrˆole; SPIxSR; SPIxRXB; SPIxTXB; SPIxBUF

Fig. 14 : Fonctionnement du module SPI en mode maître

### 3.8.2 Programmation du module de communication série synchrone

Les projets développés en EEA0601 ne nécessitent pas de programmer directement le bus SPI même si ce dernier est utilisé pour le pilotage de l’afficheur LCD mis en œuvre en section 6. Par ailleurs, l’absence de protocole standardisé reposant sur le bus SPI rend illusoire la proposition de fonctions génériques reutilisables au sein de projets mettant en oeuvre un panel diverssifié d’éléments communicant en SPI. Enfin l’utilisation du SPI est souvent complété d’autres signaux (Enable ou R/W par exemple) qui nécessitent de respecter des chronogrammes précis. C’est pourquoi il est recommandé de travailler directement avec les regitres du dsPIC associés à l’exploitation de ce bus.

M. COLAS/D. CARTON | 15

- SPIxCON permet de régler la vitesse de modulation du bus, les modes (8 ou 16 bits, Maître ou esclave) ainsi que le calage de l’horloge relativement aux données à émettre ;
- SPIxSTAT permet d’activer le module SPI et informe de l’état des registres d’émission et de réception ;
- SPIxBUF contient en lecture les données reçues à l’issue d’un transfert et accepte en écriture les données à transmettre.

Un exemple d’utilisation de ces registres est disponible au sein de la librairie permettant l’initialisation et l’écriture sur l’afficheur DOGM163 (fichiers LCD.c et LCD.h disponibles sur Moodle).

## 4 Acquisition et traitement des mesures issues des capteurs

Il s’agit ici de créer une carte permettant au robot de se repérer dans l’espace et embarquant

- un capteur ultra-sons destiné à détecter un obstacle ;
- des capteurs infra-rouge exploités pour effectuer un suivi de ligne ;

ainsi que de programmer le microcontrôleur afin de restituer ces informations toutes les 100ms via une liaison série de type RS232.

### 4.1 Acquisition et traitement des données issues du capteur ultra-sons (séance

3)

L’acquisition de l’information de distance à un obstacle repose sur l’émetteur-récepteur d’ultra-sons SRF05. Celui-ci s’interconnecte au micro-contrôleur grâce aux signaux trigger et echo dont le chronogramme est présenté sur la figure 15.

✔ | Q.4.1-1 Etudiez la datasheet de ce système, et expliquez en quelques phrases son principe et son fonc- tionnement.
✔ | Q.4.1-2 Câblez le capteur sur plaquette Labdec. On utilisera pour cela un générateur d’impulsions pour générer le signal trigger et un oscilloscope pour observer les signaux trigger et echo.
✔ | Q.4.1-3 Quelle est la durée minimale de l’impulsion du signal trigger, T min pulse. Donnez la relation entre la distance de l’obstacle et la largeur d’impulsion du signal echo ∆IC .
✔ | Q.4.1-4 Quelle période des impulsions trigger, TPWM vous semble adaptée au problème ? Justifiez.
| séance

t

trigger

echo

TPWM

∆TIC

Fig. 15 : Chronographe des signaux de pilotage du SRF05

✔ | Q.4.1-5 Vérifiez la conformité du fonctionnement du capteur ultrasons à celui indiqué dans la datasheet en traçant la courbe d’étallonnage distance de détection (d) vs durée de l’état haut de l’écho (∆TIC . Pour cela, on utilisera un obstacle sufisamment grand, plan et rigide pour permettre une réflexion franche des ondes (une plaque de carton par exemple).
| 4.1.1 Génération périodique du trigger 2 A présent, on souhaite utiliser la fonctionnalité PWM du microcontrôleur dont le fonctionnement est
| décrit au chapitre 15 du dsPIC30F Family Reference Manual (http://ww1.microchip.com/downloads/en/devicedoc/70046d.pdf) afin de générer l’impulsion trigger à intervalle régulier.
| 2Cette partie peut être réalisée à compter de la séance 8 lors de la phase de programmation.
M. COLAS/D. CARTON | 16

✔ | Q.4.1-6 Expliquez en quelques phrases le fonctionnement de ce module puis l’utilité des principaux registres mis en jeux.
| On choisit de générer une impulsion trigger de largeur 1ms et de période 100ms .
✔ | Q.4.1-7 Sachant que par défaut le registre 16 bits de comptage PTMR s’incrémente Fcy = 29488000 fois par seconde, quel prescaler (bits PTCKPS du registre PTCON) vous semble le plus adapté à ces durées ? Quelle doit alors être la valeur du registre PTPER ?
✔ | Q.4.1-8 Proposez une fonction void startTrigger(int Periode) qui enclenche la génération d’impul- sions trigger sur la pin RE01 de largeur souhaitée et de période Periode.
| ☞ Indications : Cette fonction devra :
| • Réinitialiser le compteur à 0 (registre PTMR) ;
| • initialiser la valeur limite de comptage ;
| • sélectionner la sortie PEN1L ;
| • règler le registre de rapport cyclique DCY pour obtenir la largeur d’im- pulsion souhaitée ;
| • positionner le prescaler et activer la génération du signal.
✔ | Q.4.1-9 Appelez cette fonction dans votre fonction main en la faisant suivre d’un while(1); pour mettre le programme en bouclage infini une fois la PWM activée. Visualiez la sortie PEN1L sur oscillo- scope. On enregistrera une copie d’écran où l’on fera apparaitre les périodes et largeur d’impulsion observées puis on comparera cette période et largeur d’impulsion aux valeurs attendues.
| 4.1.2 Acquisition de la largeur d’impulsion d’écho L’acquisition de la largeur d’impulsion de l’écho nécessite de détecter les instants d’un front montant Tr et du front descendant suivant Tf , puis de calculer ∆TIC = Tf − Tr. Pour cela, il est simple d’utiliser la fonctionnalité d’Input-Capture du microcontrôleur décrite en section 3.4 et de manière plus précise dans la section 13 du dsPIC30F Family Reference Manual . (http://ww1.microchip.com/downloads/en/devicedoc/70046d.pdf)
✔ | Q.4.1-10 Expliquez en quelques phrases le principe de l’input-capture ainsi que le rôle des registres de configuration associés (ICxCON et ICxBUF). Le dsPIC30F4012 dispose de 2 entrées d’input-capture (IC7 et IC8) et chacune de ces entrées est susceptible de déclencher une interruption sur occurence d’un front. Dans la suite, on utilise IC7 que l’on souhaite coupler au timer 3.
✔ | Q.4.1-11 Compte-tenu de la période du signal echo déterminée dans la question Q.4.1-4, quelle valeur de prescaler du timer 3 semble la plus adaptée ?
✔ | Q.4.1-12 En appelant Nf et Nr les valeurs respectives du compteur TMR3 aux instants respectifs de front descendant et montant, quelle est alors l’équation permettant de relier la valeur à renvoyer sur la liaison UART à la valeur ∆NIC = Nf − Nr mesurée .
✔ | Q.4.1-13 Vous êtes vous demandé ce qui se passe lorsque le compteur franchi sa limite de comptage (0xFFFF) entre les instants de front montant et descendant ? Pourquoi cela ne pose-t’il pas de problème lorsque les variables utilisées pour le calcul d’intervalle sont non signées ?
✔ | Q.4.1-14 Proposez une fonction void startIcMonitoring(void) qui :
| • initialise IC7CON pour utiliser le Timer 3 et détecter tout type de fronts ; • initialise les registres PR3 et TMR3 du Timer 3 aux valeurs respectives 0xFFFF et 0 ; • s’assure que les interruptions du Timer 3 sont masquées (registre IEC0) puis active le timer ; • efface le drapeau d’interruption IC7 (registre IFS1) puis démasque l’interruption (registre IEC1).
M. COLAS/D. CARTON | 17

A présent, il faut implémenter la routine d’interruption qui doit se déclencher lors de la détection des fronts.

✔ | Q.4.1-15 Proposez un organigramme décrivant les actions prises en charge par la routine.
✔ | Q.4.1-16 Programmez la routine d’interruption dont la syntaxe est la suivante :
1 | void __attribute__((__interrupt__,no_auto_psv)) _IC7Interrupt( void )
2 | {
3 | ...

4
5 | IFS1bits.IC7IF=0; | //raz flag
6 | }

☞ Indication :

En C, le mot clef static permet de conserver la valeur d’une variable locale à une fonction entre deux appels de celle-ci.

✔ | Q.4.1-17 Interfacez à présent le microcontrôleur en lieu et place du générateur d’impulsions et de l’os- cilloscope puis testez l’ensemble PWM/Input-Capture pour différentes distances de détection.
| ☞ Astuce :
| On pourra utiliser le mode pas à pas et la visualisation de variables (Win- dow|Debugging|Variables) pour observer la variable contenant distance à l’obs- tacle. La valeur de la variable n’est lisible que lorsque le programme est stoppé dans une zone programme située dans son scope.
| ☞ Attention :
| Pour plus de sécurité, il vaut mieux lancer la surveillance des fronts avant l’activation de la PWM. Voyez-vous pourquoi ?

### 4.2 Programmation de l’acquisition et du traitement des données issues des

capteurs IR

| 4.2.1 Partie expérimentale (séance 4)
✔ | Q.4.2-1 Parcourez la documentation du TCRT5000 identifiant les valeurs électriques et mécaniques importantes.
✔ | Q.4.2-2 Proposez un schéma de câblage en précisant les valeurs des composants.
| Il s’agit à présent de réaliser le montage électronique et mécanique d’un capteur pour pouvoir effectuer des relevés expérimentaux.
✔ | Q.4.2-3 Réalisez une platine (en époxy de CI) dotée de 4 vis périphériques de réglage de hauteur et d’un capteur TCRT5000 fixé en son centre comme présenté sur la figure 16.

TCRC5000

Fig. 16 : Dispositif de mesure

✔ | Q.4.2-4 En supposant qu’une source de tension de 5V est utilisée, déterminez les valeurs des résistances à placer en série avec la diode d’émission et sur le collecteur du phototransistor pour obtenir un fonctionnement correct. Câblez le TCRT5000 avec ces composants en identifiant le point de mesure à exploiter.
M. COLAS/D. CARTON | 18

✔ Q.4.2-5 En utilisant votre dispositif ainsi que Matlab ou Excel, effectuez un relevé pour différentes hauteurs de la courbe de tension du phototransistor en fonction de la position latérale à la ligne.

☞ Attention :

Validez la robustesse de vos mesures en effectuant si besoin plusieurs relevés identiques et en modifiant les conditions d’éclairage. Conclusion.

✔ Q.4.2-6 Quelle sont d’aprés vous les valeurs optimales d’écartement et de distance des capteurs par rapport au sol ? Pourquoi ?

✔ Q.4.2-7 Déduisez-en le nombre N de capteurs adéquat pour le projet.

### 4.2.2 Réalisation de la carte sous Eagle®

(séances 5 à 7)

Il est nécessaire pour poursuivre de disposer de la carte capteurs.

✔ Q.4.2-8 Recensez les fonctionnalités mobilisées par la carte ainsi que les pins du microcontôleur associées.

☞ Indication :

Pour éviter de consommer des I/O nécessaires à l’acquisition analogique ou à la détection d’obstacle, on utilisera en priorité les pins du port E (sauf RE0) pour commander l’allumage des LEDs IR. On prendra également soin de prévoir un montage à transistor permettant de limiter le courant consommé sur chacune de ces sorties.

✔ Q.4.2-9 En utilisant :

- la librairie de composants , (https://cours.univ-reims.fr/pluginfile.php/86178/mod_folder/content/0/EEA0601-770-20190313.lbr?forcedownload=1)
- les consignes de réalisation prodiguées par vos enseignants,
- le mode d’emploi d’Eagle® , (https://cours.univ-reims.fr/mod/resource/view.php?id=18075)

disponibles sur le cours Moodle, réalisez le schéma de principe et le routage de la carte. Le typon sera réalisé en deux couches avec plan de masse sur la couche supérieure. On prendra soin de positionner les connecteurs en périphérie de la carte.

☞ Informations :

- N’utilisez jamais l’auto-routage ;
- Placez précisément vos capteurs IR (ils doivent être alignés et régulièrement espacés) ;
- Soyez rigoureux : composants positionnés du bon côté de la carte, pistes dimensionnées en fonction du courant qui y circule, présence de condensateurs de filtrage d’alimentation, angles des pistes à 45◦
, limitation du nombre de vias . . .
- Après | validation | par | l’enseignant, | vous | transmettrez | vos | fichiers | à
david.carton@univ-reims.fr | et/ou | maxime.colas@univ-reims.fr | pour
tirage de la carte.

### 4.2.3 Acquisition de la mesure sur microcontrôleur (séance 9)

Suite aux questions précédentes, vous disposez :

- du nombre N de capteurs nécessaires TCRC5000 au projet ;
- de l’entraxe D des capteurs permettant une estimation optimale de la distance à la ligne.
- d’une courbe tension versus distance à la ligne (centre du ruban pris pour origine) pour chaque capteur.

Le microcontôleur est doté de convertisseurs analogique-numérique 10 bits multiplexés.

M. COLAS/D. CARTON | 19

✔ Q.4.2-10 Quelles devraient être les valeurs numériques min et max observées lors de l’acquisition sur un capteur ?

✔ Q.4.2-11 Repérez sur le connecteur 26 points de la carte microcontrôleur la connection à l’entrée AN0 du convertisseur analogique-numérique et raccordez-y la sortie collecteur du phototransistor.

✔ Q.4.2-12 Ecrire un programme qui acquiert en boucle les données d’un capteur en utilisant les fonctions initADC0() pour initialiser le convertisseur et startADC0(&IRValue) pour récupérer la valeur convertie dans la variable IRValue.

☞ Astuce :

On pourra utiliser le mode pas à pas et la visualisation de variables (Window|Debugging|Variables) pour observer les valeurs acquises sur le convertisseur et ainsi valider les résultats de la question Q.4.2-10. La valeur des variables n’est lisible que lorsque le programme est stoppé dans une zone programme située dans son scope.

Vérifiez les valeurs min et max obtenues expérimentalement en faisant varier latéralement et verticalement les distances au centre d’une ligne noire.

Il s’agit à présent de récupérer les mesures sur l’ensemble des capteurs. Pour cela, on propose d’utiliser une interruption périodique de période T =

1
100Nt s durant laquelle on acquerra la mesure d’un seul capteur à la fois. Pour éviter les interférences entre capteurs, on propose de n’allumer que la led correspondant au phototransistor mesuré. Lorsque l’ensemble des capteurs aura été passé en revue, c’est à dire toute les 10ms, on utilisera les acquisitions pour estimer la position du ruban puis les transmettre.
✔ | Q.4.2-13 Donnez l’organigramme décrivant le traitement à effectuer dans cette interruption.
✔ | Q.4.2-14 Sachant que la fréquence d’incrémentation des timers 16bits est fixée par défaut à Fcy =
29,488MHz, quel est le plus faible prescaler permettant d’assurer une période supérieure ou égale à T ?

✔ Q.4.2-15 Initialisez le timer1 pour obtenir une interruption selon cette période. Pour cela, on définira une fonction startTimer1(int periode) qui :

- initialise la valeur maximale de comptage (registre PR1),
- le compteur (registre TMR1),
- le prescaler,
- réinitialise le drapeau d’interruption (registre IFS0) et demasque l’interruption (registe IEC0) du timer 1.
- active le timer (registre T1CON).

☞ Indication :

Utilisez les informations founies dans la section 12 du dsPIC30F Family Reference Manual . (http://ww1.microchip.com/downloads/en/devicedoc/70046d.pdf)

✔ Q.4.2-16 Sur la base de l’organigramme proposé dans la question Q.4.2-13, écrivez la routine d’interruption du Timer1 permettant d’acquérir la mesure infrarouge d’un seul capteur à la fois et collecte les acquisitions dans un vecteur measuresIR[nSensors]. On rappelle la syntaxe de déclaration de la routine d’interruption du timer 1 :

1 | void __attribute__((__interrupt__,no_auto_psv)) _T1Interrupt( void )
2 | {
3 | ...

4
5 | IFS0bits.T1IF=0; | //raz flag
6 | }
M. COLAS/D. CARTON | 20

### 4.2.4 Conversion des mesures en position (séances 9 et 10)

Quantification simple
La conversion des mesures en position est une opération qui peut être menée de façon plus ou moins complexe selon la précision de mesure souhaitée. Dans le cas le plus simple, il s’agit de définir pour chaque capteur un seuil Sp sur la mesure au delà duquel la ligne est supposée présente. Si l’espace entre capteurs successifs E et le seuil Sp sont correctement choisis, il est possible d’observer une présence sur deux capteurs consécutifs lorsque la ligne se situe entre ces capteurs. La figure 17 présente pour un dispositif à 5 capteurs, les 10 observations distinctes valides avec cette méthode en fonction de la position de la ligne au sol. Pour chacune de ces observations, un secteur est alors associé qui à son tour sera converti en position.

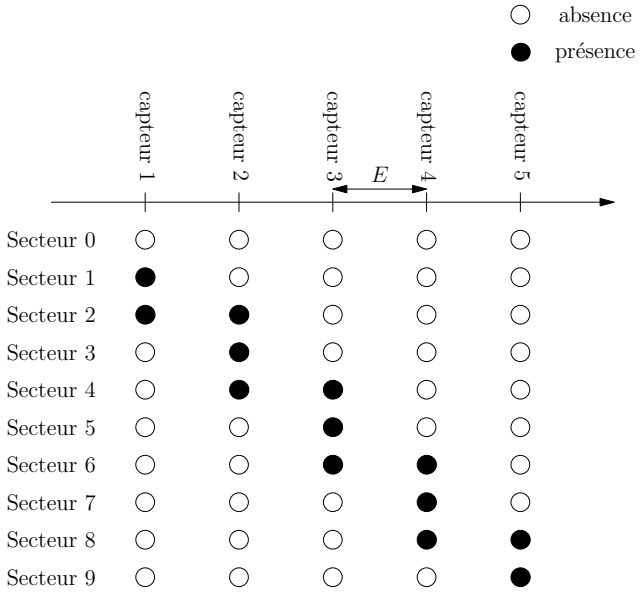
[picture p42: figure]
pr´esence; absence; capteur 1; capteur 2; capteur 3; capteur 4; capteur 5; Secteur 0; Secteur 1; Secteur 2; Secteur 3; Secteur 4; Secteur 5; Secteur 6; Secteur 7; Secteur 8; Secteur 9

Fig. 17 : Correspondance entre secteurs et observations dans le cas d’une quantification simple de la position par rapport à la ligne

✔ Q.4.2-17 Proposez une méthode simple permettant de convertir ces observations en secteur puis en
mesure de distance du capteur central par rapport à une ligne au sol en mm.

✔ Q.4.2-18 Produisez le code C associé à votre méthode et insérez-le dans une fonction char sensorsToDist(unsigned int sensors[],int Nsensors,unsigned int e, unsigned int sp) où sensors[] représente le tableau de taille Nsensors contenant les mesures des capteurs, e est l’entraxe des capteurs, et sp est le seuil de binarisation des valeurs infra-rouge converties.

Quantification fine (étape facultative)
Compte tenu de l’allure de la réponse des capteurs infra-rouge observée dans la question Q.4.2-5, il est possible d’obtenir une estimation plus précise de la position que celle issue d’une quantification simple.

✔ Q.4.2-19 En modélisant les courbes obtenues dans la question Q.4.2-5 comme présenté sur la figure 18, expliquez en quoi la conversion proposée par l’organigramme de la figure 19 améliore l’estimation tout en restant simple à implémenter. Dans cet organigramme, on retiendra les définitions suivantes :

f1(c) = −2E + (c[1] − 2

N b)

E
2Nb
f9(c) = 2E + (2N b − c[5]) E
2Nb
fP (c) = (Sec−5)E
2 + (c[

Sec
2 + 1] − c[

Sec
2

]) E
2Nb+1 ;
fI (c) = 5(Sec − 5)E + (c[

Sec+3
2

] − c[

Sec−1
2

]) P
2Nb ;
M. COLAS/D. CARTON | 21

☞ Indication :

On pourra notamment comparer (dans Matlab par exemple) les erreurs maximales des 2 méthodes ainsi que l’erreur quadratique moyenne de chacune.

x
C | P
E

2Nb − 1

Fig. 18 : Modélisation de la réponse des capteurs IR en fonction de leur distance x au centre d’une ligne au sol de largeur fixée. Nb correspond au nombre de bits du convertisseur analogique numérique utilisé.

### 4.3 Transmission des mesures et tests (séance 11)

Les informations de position et de distance doivent être transmises à la carte IHM, développée par un autre binôme. La mise en place de cette communication nécessite d’utiliser un standard de signalisation électrique et un protocole d’échange d’informations compréhensibles par l’émetteur et le récepteur.

### 4.3.1 Standard d’interconnexion

Le standard retenu met en œuvre le module UART du microcontrôleur (voir section 3.7) pour piloter une liaison série asynchrone sur niveaux TTL, paramétrée comme suit :

- 9600 Bauds ;
- 1 bit de stop ;
- pas de contrôle de parité.

### 4.3.2 Format des remontées d’information de position et de distance

Les mesures sont transmises sur ce bus sous la forme d’un octet dont le bit de poids fort indique la nature de l’information :

- 0 : position par rapport à la ligne
- 1 : ultra-son

Les 7 bits de poids faibles doivent être interprétés comme une valeur V :

- Mesures infra-rouge : V représente la distance algébrique (donc signée) à la ligne exprimée en mm. Lorsque la ligne est perdue ou que la mesure est incohérente, la valeur -64 est retournée.
- mesure ultra-son : V représente la détection d’un objet situé à V
2

cm. au delà de 63cm, la valeur 127 est retournée.

✔ | Q.4.3-1 Créez une fonction destinée à mettre les mesures infra-rouge et ultra-son au format requis par le protocole.
✔ | Q.4.3-2 En considérant un rythme de modulation de 9600 bauds sur la liaison asynchrone, quel est le nombre maximal de transmissions par seconde de chaque information (infra-rouge et ultra-son) possible.
| Compte tenu de la dynamique attendue du robot, il peut être considéré qu’un rythme de transmission de chacune des mesures toute les 100ms est suffisant.
M. COLAS/D. CARTON | 22

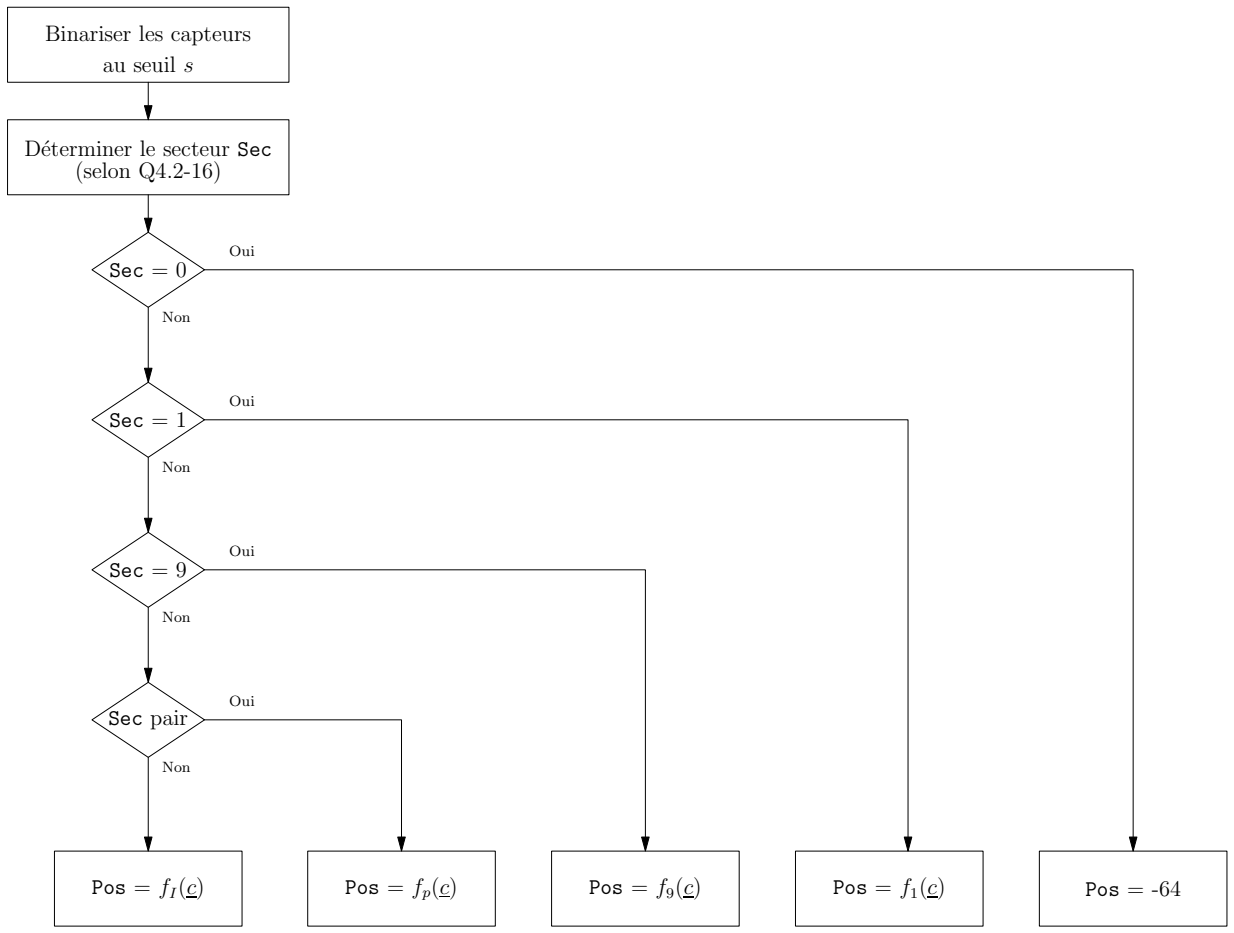
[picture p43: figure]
Binariser les capteurs au seuil s; D´eterminer le secteur Sec (selon Q4.2-16); Oui; Non; Sec = 0; Sec = 1; Sec = 9; Sec pair; Pos = fI (c); Pos = fp(c); Pos = f9(c); Pos = f1(c); Pos = -64

Fig. 19 : Estimation fine de la distance latérale du centre du robot par rapport à une ligne au sol de largeur fixée (cas N = 5)

## 5 Commande des moteurs du Traxter II

Le robot Traxter II est équipé de deux moteurs à courant continu monté en tête bêche et munis de motoréducteurs. Ils possédant les caractéristiques suivantes :

- Tension nominale : 7.2V
- Courant maximal d’induit : 4A
- Vitesse maximale en sortie de motoréducteur : 160 T/mn
- Couple de démarrage : 7.2kg.cm

Un codeur rotatif, fixé sur l’axe de chaque moteur permet de récupérer une image de sa vitesse de rotation. Ces codeurs sont aliments en 5V et délivrent 624 impulsions par tour.

### 5.1 Rappels : variation de la vitesse d’un moteur à courant continu

Un moteur à courant continu est constitué d’un inducteur (généralement le stator) destiné à créer un champ magnétique Bs au travers d’un induit (généralement le rotor). Lorsque l’induit est le siège d’un courant Ii

, le couple généré par la force de Laplace le met en rotation. Ce couple est donc proportionnel au courant Ii qui traverse le conducteur de l’induit :

C = kIi

M. COLAS/D. CARTON | 23

b7 | b6 | b5 | b4 | b3 | b2 | b1 | b0

0 : IR
1 : US

Distance ligne : sign´e et en mm (-64 = pas de ligne)
Distance obst. : non sign´e et par pas de 5 mm (123 = obstacle + de 63cm)

Fig. 20 : Protocole de communication

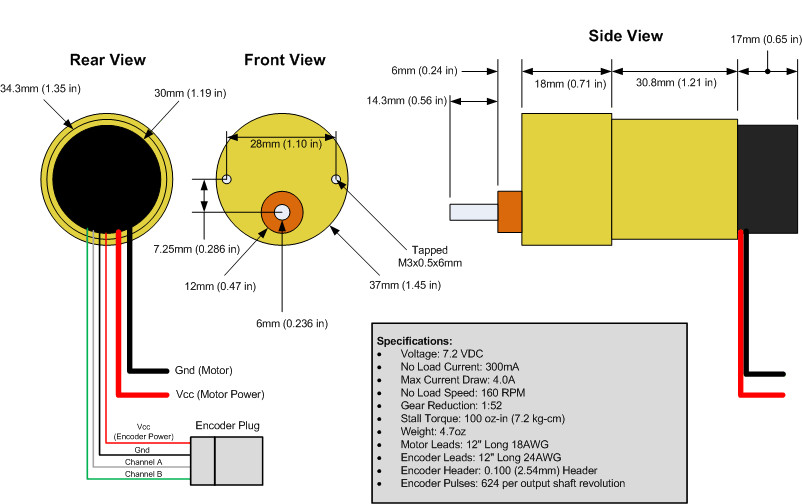
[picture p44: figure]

Fig. 21 : Caractéristiques des moteurs à courant continu du Traxter II

Il est également lié à la vitesse de rotation du moteur par l’équation mécanique :

J

dΩ
dt = C − Cr

où J est le moment d’inertie du moteur et des éléments accouplés et Cr un couple résistant (charge, frottement secs ou visqueux).
En tournant, une force contre-électromotrice formalisée par la loi de Lenz est engendrée aux bornes de l’induit proportionnelle à la vitesse de rotation :

E = k

0Ω

et l’équation de l’induit (en alimentation continue) vaut alors :

U = RIi + E

En supposant un rendement idéal, l’ensemble de la puissance électrique est convertie en puissance mécanique si bien que :
P = UIi = EIi = CΩ

soit k = k

0
Cette approximation est valable si RI2
i

est faible au regard des puissances mécaniques en jeu, ce qui est vrai par exemple lorsque le couple résistant est faible. Selon cette approximation on trouve :

Ω = k

−1U

La vitesse du moteur est alors directement proportionnelle à la tension d’alimentation appliquée sur son induit.

### 5.2 Commande numérique en vitesse du moteur

Il est simple de faire varier la tension moyenne appliquée sur l’induit en utilisant le hacheur monophasé présenté sur la figure 22.
En fermant K2 et en ouvrant simultanément K1 durant une proportion α de chaque période T la tension moyenne appliquée à l’induit vaut :

< U >= αVs

M. COLAS/D. CARTON | 24

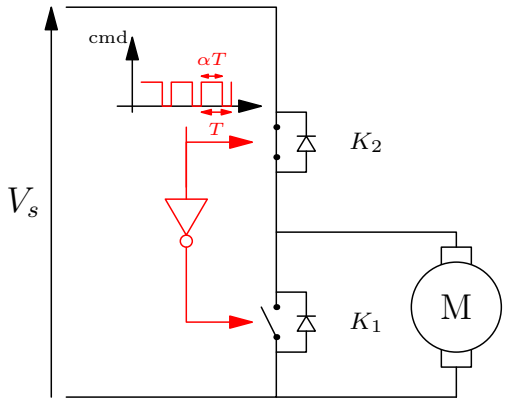
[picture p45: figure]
cmd

Fig. 22 : Hacheur monophasé

Compte tenue de l’inertie du moteur, les acoups de vitesse ne sont pas perceptibles dès que la période de commande T est suffisamment faible soit :
Ω = kαVs
Enfin, étant constitué d’un bobinage, l’induit présente une auto-induction non négligeable lorsque le courant d’induit est fluctuant si bien qu’un modèle électrique plus fidèle de l’induit est en fait :

u(t) = Rii(t) + e(t) + L

dii(t)
dt
Là encore, une commande à période suffisamment faible permet de lisser le courant d’induit et donc les variations de couple.
✔ | Q.5.2-1 Connectez directement un des moteurs à une alimentation stabilisée (capable de débiter le courant requis) puis relevez la vitesse de rotation pour différents niveaux de tension et différents couples résistants : que constatez-vous à faible tension ? Pourquoi ?
✔ | Q.5.2-2 Estimez la vitesse maximale d’avancement du robot Traxter II en km/h.
| 5.2.1 Le BTN8982 (séances 1 et 2)
| Le BTN7970 intègre le bras de pont présenté sur la figure 22 dans un unique circuit intégré.
✔ | Q.5.2-3 Etudiez la documentation technique du BTN7970 (https://docs.rs-online.com/2f05/0900766b80f8a49b.pdf) en précisant notamment :
| • les tension et courant maximums d’alimentation ; • la tension de commande logique ; • la fréquence maximale de commande ; • les caractéristiques thermiques importantes (température maximale de fonctionnement, ré- sistance thermique) ;
| • le RDSON des MOSFET ; les temps de montée et de descente ; • le rôle de chaque broche du circuit.
✔ | Q.5.2-4 Proposez un shéma de cablage du BTN8982 sur plaquette Labdec.
| ☞ Attention :
| N’oubliez pas la capacité de filtrage de l’alimentation ainsi que les résistances de protection sur IN et INH destinées à limiter les pics de courant circulant dans ces broches.
✔ | Q.5.2-5 Validez par des observations à l’oscilloscope, et à l’aide d’un générateur d’impulsions, le fonc- tionnement du BTN sur une charge résistive de 100Ω. Quelle est la puissance moyenne dissipée dans la résistance pour une tension d’alimentation de 7V et un rapport cyclique α ?
| ☞ Attention :
| Une résistance standard est généralement construite pour dissiper un maximum de 0.25W.
M. COLAS/D. CARTON | 25

Estimation des dissipations thermiques

Les dissipations thermiques provoquées par les MOSFET en commutation proviennent :

- des pertes de commutation :
- de la resistance du transistor à l’état passant.

Les pertes de commutation sur charge inductive dépendent de la fréquence de commutation, de la tension d’alimentation et des temps d’établissement et d’extinction du courant et sont évaluables lorsque les MOSFET sont modélisés comme des interrupteurs imparfaits. Lorsque K2 s’ouvre et même sans commande de fermeture sur K1, ce dernier devient passant du fait de sa diode de roue libre intrinsèque et du caractère inductif de la charge qui tend à maintenir son courant constant. La tension aux bornes de K2 vaut donc immédiatement V s. Le courant dans K2 s’éteint aproximativement linéairement sur une durée tf .
Lorsque K2 se ferme, K1 s’ouvre mais le courant ne circulant pas instantanément dans K2, la diode de roue libre intrinsèque à K2 est en conduction si bien que VK2 = VS. Le courant croit approximativement linéairement dans K2 durant le temps tr puis la diode cesse de conduire et la tension VK2 s’annule instantanément. Un raisonnement identique d’applique sur K1. La puissance dissipée par les commutations de chaque transistor est alors :

Pcomm =

(tr + tf )VsIi
2T

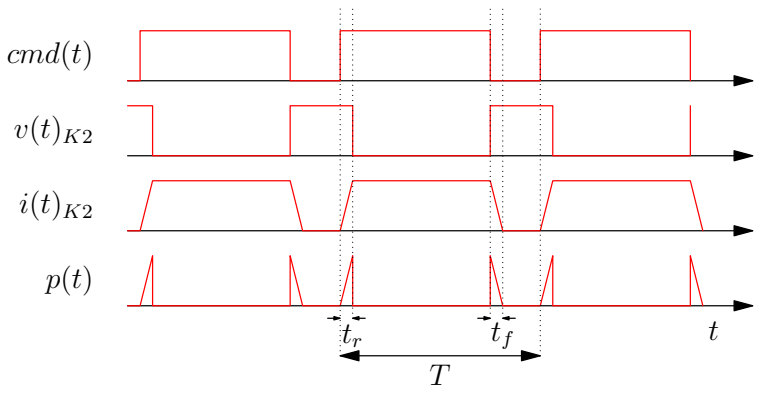
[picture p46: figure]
cmd(t)

Fig. 23 : Pertes de commutation

En conduction, la puissance dissipée provient de la résistance résiduelle du canal RDSON . Elle vaut :

Pcond =

(
RDSON I

2
i α | dans le transistor supérieur
RDSON I

2
i

(1 − α) dans le transistor inférieur

✔ Q.5.2-6 Calculez la puissance dissipée par un BTN pour une tension d’alimentation de 7V, un courant de 4A et une fréquence de commutation de 20kHz.

En l’absence de dissipateur, l’élévation de température de la jonction est obtenue par l’expression :

∆T[

◦C] = Rth(j−a)
[

◦C/W]P[W]

où ∆T est l’élévation de la température de la jonction par rapport à celle du milieu, Rth(j−a) est la résistance thermique jonction-ambient du composant et P la puissance qu’il dissipe.

✔ | Q.5.2-7 Déduisez-en la temprérature du boitier nu dans un environnement à 20◦C.
✔ | Q.5.2-8 Reprenez le calcul en utilisant un dissipateur pour boitier TO-263 (ref 573300 AAVID THER-
MALLOY) (https://www.mouser.fr/datasheet/2/2/Aavid-Board-Level-Heatsinks-Catalog-2018-1507171.pdf) puis discutez de son utilité.

✔ Q.5.2-9 Remplacez la résistance par un des moteurs du Traxter II et validez le fonctionnement de l’ensemble pour différents rapports cycliques du générateur d’impulsion.

M. COLAS/D. CARTON | 26

Hacheur 4 quadrants
Dans l’état actuel, la commande du moteur n’est possible que selon un sens de rotation. Pour pouvoir inverser ce sens, il est nécessaire de mettre en place un hacheur 4 quadrants.
✔ | Q.5.2-10 Proposez un schéma de câblage destiné à piloter les moteurs dans les deux sens de rotation. La commande en opposition des deux bras de pont nécessite d’inclure un inverseur dans votre schéma : proposez une référence de composant et insérez-la dans votre schéma.
✔ | Q.5.2-11 Donnez l’expression de la tension moyenne aux bornes du moteur en fonction du rapport cyclique du signal de commande du pont.
✔ | Q.5.2-12 Câblez et testez ce schéma sur plaquette Labdec et sur une charge résistive de 100Ω. Quelle est la puissance moyenne dissipée dans la résistance pour une tension d’alimentation de 7V en fonction du rapport cyclique ?
✔ | Q.5.2-13 Lorsque les tests sont probants, remplacez la résistance par le moteur et validez la commande pour différents rapports cycliques.
✔ | Q.5.2-14 Quelle est la vitesse de rotation attendue pour une commande MLI de rapport cyclique 50% ? Dans ces conditions, est-il nécessaire d’alimenter le moteur ? Quel fonctionnalité du BTN8982 pourriez-vous utiliser pour couper l’alimentation logiciellement ?
| 5.2.2 Commande du pont par microcontrôleur 3 Comme expliqué en section 3.5, le module PWM permet de générer un signal MLI de période et de rapport cyclique souhaité.
✔ | Q.5.2-15 En utilisant les librairies periph_pwm.h et periph_pwm.c, produisez un signal PWM de période 50µs et de rapport cyclique 25% sur la sortie PEN1H et son complément sur la sortie PEN1L.
✔ | Q.5.2-16 Connectez ces sorties à votre hacheur et actionnez le moteur pour différentes valeurs program- mées de rapports cycliques.
✔ | Q.5.2-17 En vous basant sur la vitesse de rotation obtenue pour une tension de commande continue V s = 7V , exprimez le lien entre le rapport cyclique et la vitesse de déplacement du robot.
✔ | Q.5.2-18 Déterminez la valeur de prescaler la mieux adaptée à un fonctionnement à des vitesses com- prises entre -2.5km/h et 2.5km/h par pas maximal de 0.02km/h.
✔ | Q.5.2-19 Quel serait l’inconvénient de choisir un prescaler trop grand ?
✔ | Q.5.2-20 Créez une fonction void SetLeftMotorSpeed(int speed) permettant d’obtenir une vitesse algébrique de roulage speed en mm/s sur le moteur gauche (on suppose ici qu’aucun couple résistant n’existe sur le moteur).
✔ | Q.5.2-21 Dupliquez cette fonction pour le second moteur en notant que pour une même commande, ils tournent en sens opposés.
✔ | Q.5.2-22 Validez le bon fonctionnement de vos commandes.
✔ | Q.5.2-23 Que constatez-vous à nouveau à faible vitesse identique sur chaque moteur ? Comment remédier à ce problème ?

### 5.3 Obtention d’une image de la vitesse de rotation des moteurs (séance 3)

Compte tenu du problème soulevé à la question précédente, il est nécessaire de prévoir un système d’asservissement de la vitesse des moteurs. Cela nécessite d’acquérir une image de leur vitesse réelle de rotation. La vitesse de rotation d’un moteur peut être obtenue en fixant un codeur rotatif à son arbre de rotation. Ces codeurs sont soit optiques, soit basés sur l’effet Hall mais leur principe de fonctionnement est identique : ils sont alimentés et délivrent des impulsions rectangulaires dont la période dépend de

3Cette partie peut être réalisée à compter de la séance 8 lors de la phase de programmation.

M. COLAS/D. CARTON | 27

la résolution du capteur (mesurée en impulsions par tour) et varie avec la vitesse de rotation. Dans le cas optique, un disque perforé à intervalle angulaire régulier et à rayon constant est intercalé entre l’émetteur et le récepteur d’une fourche optique. Le faisceaux lumineux est passant lorsqu’il se trouve à l’aplomb d’une perforation et bloqué sinon. Les codeurs rotatifs à effet Hall détectent la présence d’un champ magnétique généré par de petits aimants disposés sur le disque identiquement aux perforations des capteurs optiques à l’aplomb d’un capteur.
La figure 24 présente le shéma d’un codeur optique. L’utilisation de deux séries d’encoches concentriques disposées en quadrature permet de doubler la résolution angulaire du capteur mais aussi de discriminer son sens de rotation. Les signaux A et B fournissent une image électrique de la détection de ces encoches. Ainsi, une rotation horaire (resp. anti-horaire) correspondra à un front descendant de B sur état haut (resp. bas) de A ou à un front montant de B sur état bas (resp. haut) de A. Une variable booléenne vraie lorsque le sens de rotation est horaire et fausse sinon pourra donc être définie par :

X = B ↑ .A + B ↓ .A¯

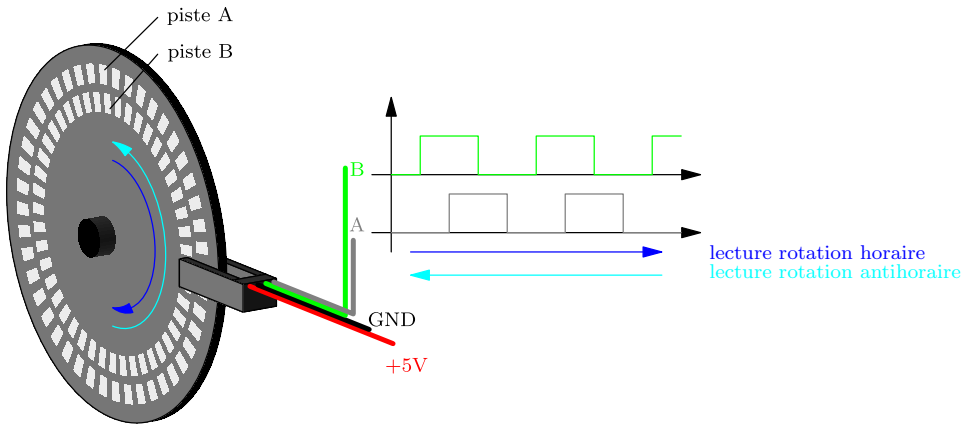
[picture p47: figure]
lecture rotation horaire lecture rotation antihoraire

Fig. 24 : Principe du codeur optique

✔ | Q.5.3-1 Cablez un des codeurs rotatifs (alimentation et observation des voies A et B sur oscilloscope) puis entrainez le moteur associé en lui appliquant une tension variable. Que constatez-vous ?
| 5.3.1 Acquisition de la vitesse de rotation sur microcontrôleur 4 L’image de la vitesse du moteur peut être construite par mesure de l’intervalle de temps entre deux
| impulsions grâces aux entrées d’input-capture IC7 et IC8.
✔ | Q.5.3-2 A partir des grandeurs mécaniques et des caractéristiques des codeurs, exprimez la vitesse de roulage du robot en fonction de l’intervalle de temps entre deux impulsions sur une même voie (A ou B). Sur la base de la question Q.5.2-18, déduisez-en les intervalles min et max observables.
✔ | Q.5.3-3 Quelle valeur de prescaler vous semble-t’il judicieux d’utiliser ? Pourquoi ?
✔ | Q.5.3-4 Que se passe-t’il lorsque la vitesse de rotation s’annule ? Comment résoudre ce problème ?
✔ | Q.5.3-5 Sous MPLab® , initialisez le module input-capture, un timer et son prescaler afin d’estimer la vitesse de rotation d’une roue.
✔ | Q.5.3-6 Mettez en place la routine d’interruption associée : celle-ci doit calculer l’intervalle entre deux impulsions (voir figure 9) puis fournir une image de la vitesse.
✔ | Q.5.3-7 Testez le fonctionnement de votre code à vitesse non nulle en plaçant judicieusement un point d’arrêt dans la routine d’interruption et en utilisant les watchs de MPLab® .
✔ | Q.5.3-8 Ajoutez le code permettant de prendre en charge une vitesse nulle et testez le bon fonctionnement de l’ensemble. 4Cette partie peut être réalisée à compter de la séance 8 lors de la phase de programmation.
M. COLAS/D. CARTON | 28

### 5.4 Réalisation de la carte sous Eagle®

(séances 5 à 7)

✔ Q.5.4-1 En utilisant :

- les librairies de composants ,
- les consignes de réalisation ,
- le mode d’emploi d’Eagle®
,

disponibles sur le cours Moodle, réalisez le schéma de principe et le routage de la carte. Le typon sera réalisé en deux couches avec plan de masse sur la couche supérieure. On prendra soin de positionner les connecteurs en périphérie de la carte.

☞ Informations :

- N’utilisez jamais l’auto-routage ;
- Soyez rigoureux : composants positionnés du bon côté de la carte, pistes dimensionnées en fonction du courant qui y circule, présence de condensateurs de filtrage d’alimentation, angles des pistes à 45◦
, limitation du nombre de vias . . .
- Après | validation | par | l’enseignant, | vous | transmettrez | vos | fichiers | à
david.carton@univ-reims.fr | et/ou | maxime.colas@univ-reims.fr | pour
tirage de la carte.
✔ | Q.5.4-2 Percez, placez puis soudez au four de refusion les composants de surface.
✔ | Q.5.4-3 Soudez au fer les composants traversants puis testez votre carte sur charge résistive dans un
premier temps.

### 5.5 Récupération des consignes par liaison série et tests (séance 8)

En fin de projet, les consignes de commandes des moteurs devront provenir de la carte de contrôle du robot, dite carte IHM, développée par un autre binôme. La mise en place de cette communication nécessite d’utiliser un standard électrique d’interconnexion et un protocole d’échange d’informations compatibles sur l’émetteur et le recepteur. L’interface série RS-232 est le standard électrique et de connexion retenu dans ce projet. Sa connectique au format DB-9 telle que présente sur de nombreux PC est précisée sur la figure 25.

RI | CTS RTS DCD
DCD | Rx | Tx | DTR GND

Fig. 25 : Connectique RS232 SUB-D coté PC

Lors de la mise en place d’un échange bidirectionnel sans gestion de trafic, seules les broches TxD, RxD et GND sont utiles. Si l’application se limite à la réception (resp. l’émission) de données sur la carte, seules les broches GND et Tx (resp. Rx) doivent être raccordées.

☞ Attention :

Un PC comme un microcontrôleur sont des DTE (Data Terminal Equipment). A ce titre, ils émettent des données sur TxD et en reçoivent sur RxD. Leur interconnexion nécessite donc de croiser les lignes RxD et TxD.

Le protocole de communication exploite le module UART présent dans le micro-contrôleur mais aussi sur la majorité des ordinateurs PC pour transmettre des octets sur une liaison série. Il est convenu d’utiliser la configuration suivante des UART pour l’ensemble des projets (Capteurs, IHM et Commande) :

- 9600 Bauds ;
- 1 bit de stop ;
- pas de contrôle de parité.
M. COLAS/D. CARTON | 29

### 5.5.1 Format des échanges

Au niveau applicatif, le protocole spécifie le contenu de deux octets transmis consécutivement ou non :

- un octet encode la vitesse tangentielle du robot ;
- un octet encode sa vitesse de lacet (rotation autour de son centre i.e. intersection des diagonales joignant ses roues opposées).

La signification de ces octets est précisées sur la figure 26.

b7 | b6 | b5 | b4 | b3 | b2 | b1 | b0

0 : vitesse tangentielle
1 : vitesse de lacet

vitesse tangentielle : sign´e et par pas de 0.02km/h vitesse de lacet : sign´e et par pas de 2◦/s (sens trigonom´etrique)

Fig. 26 : Protocole de communication

### 5.5.2 Lecture et conversion des consignes

Le déplacement du robot résulte d’une composition de son déplacement rectiligne localement et d’une rotation autour de son centre.

✔ | Q.5.5-1 En considérant nulle la vitesse de déplacement rectiligne R, calculez la différence de vitesse de rotation des moteurs ∆V en fonction de la vitesse de lacet ωL , de la voie du robot D et du diamètre de ses roues.
✔ | Q.5.5-2 En déduire les vitesses de rotation de chaque moteur ωG et ωR lorsque la vitesse rectiligne (ou vitesse tangentielle) n’est plus nulle.
✔ | Q.5.5-3 En considérant le protocole décrit sur la figure 26, quelles sont les vitesses de rotation maximales des moteurs atteignables ?
✔ | Q.5.5-4 En considérant les informations de vitesse délivrées par le code développé en section Q.5.3-2, pour un couple (R, ωL), déduire les consignes CG et CD à transmettre aux moteurs.
| 5.5.3 Interfaçage PC Comme indiqué en début de section 5.5, tant que la carte IHM n’est pas disponible pour les tests, ceux-ci doivent être menés à l’aide d’un système tierce tel un PC. Toutefois, votre carte microcontrôleur ne peut être directement raccordée à l’un des ports série présent sur un PC car les niveaux électriques de la norme RS-232 (±8V ) ne sont pas compatibles avec les tensions délivrées ou attendus sur les broches U1ATX et U1ARX (0-5V). La translation de tension bidirectionnelle indispensable à cette interconnexion est fournie par un circuit intégré nommé MAX232 . (http://www.ti.com/lit/ds/symlink/max232.pdf)
✔ | Q.5.5-5 Après avoir étudié sa documentation technique, câblez le MAX232 sur plaquette Labdec puis raccordez-le au PC : on câblera pour cela un connecteur SUBD-9 femelle.
| Dans un premier temps, il est aisé de transmettre des informations (codes ASCII) sur le port RS-232 en utilisant un terminal.
✔ | Q.5.5-6 Après avoir configuré le terminal TeraTerm, vérifiez que les niveaux de tension et les débits présents sur le MAX232 coté 0-5V sont bien ceux attendus.
✔ | Q.5.5-7 En utilisant les informations fournies en section 3.7, insérez le code permettant la configuration de l’UART et la réception des données sur le microcontrôleur.
M. COLAS/D. CARTON | 30

### 5.5.4 Utilisation de Matlab pour l’émulation de la carte commande

Matlab® permet d’ouvrir une interface de communication série de type RS-232 présente sur la majorité

des ordinateurs PC puis d’y injecter ou d’y lire des octets très simplement. A la différence d’un terminal, les octets transmis ainsi ne sont pas nécessairement des codes ASCII issus d’un clavier mais n’importe quelle valeur binaire. Ainsi :

- s=serial('COM1','BaudRate', 9600,'Parity','even') crée un objet s associé au port COM1 pour un débit de 9600 bauds et une parité paire. L’interface est ensuite ouverte identiquement à un fichier par fopen(s) ;
- la transmission de la valeur numérique n au format 8 bits non signés utilise alors write(s,n, 'uint8') ;
- La lecture de n octets non signés sur le port COM1 est réalisée par val = read(s,n, 'uint8 '). Pour plus d’informations, on consultera la documentation Matworks® (https://fr.mathworks.com/help/matlab/ref/serialport.html) .
✔ | Q.5.5-8 Créez un script Matlab permettant d’ouvrir un port de communication puis à communiquer la succession de 2 octets selon le protocole décrit sur la figure 26.
✔ | Q.5.5-9 Côté microcontrôleur, développez le code d’interprétation de ces octets et de réglage des consignes moteurs.
✔ | Q.5.5-10 Validez le fonctionnement de l’ensemble.
M. COLAS/D. CARTON | 31

### 5.6 Asservissement de la vitesse de rotation des moteurs (séances 9 et 10)

L’asservissement de la vitesse de rotation des moteurs à la consigne assure un fonctionnement à basse vitesse du robot ainsi que le respect des trajectoires souhaitées (absence de déviation en ligne droite par exemple).
Typiquement, un asservissement est mis en œuvre selon le schéma illustré sur la figure 27 où C est un correcteur généralement de type PID.

+

C | moteur
ΩC | ǫ | Vc | ΩM

Fig. 27 : Schéma d’asservissement de vitesse

✔ | Q.5.6-1 Identifiez chacune des grandeurs du schéma.
✔ | Q.5.6-2 Donnez l’expression de Laplace d’un correcteur PID puis expliquez brièvement l’interêt de cha-
cune des actions (P, I et D).

### 5.7 Identification de la fonction de transfert d’un moteur

Pour valider la période d’échantillonnage choisie et régler ensuite les paramètres du correcteur, il est nécessaire de procéder à l’identification de la fonction de transfert des moteurs. Classiquement, la fonction de transfert M(p) = Ω
U
(p) d’un moteur à courant continu est modélisée par un second ordre :
M(p) = | A
(1 + τep)(1 + τmp)

où τe =

R
L

est un constante de temps électrique et τm =

RJ
k²+Rf , f frottement visqueux, est une constante de temps mécanique. Généralement τe τm si bien que le modèle peut être approché par un premier ordre aux fréquences d’utilisation :

M(p) = A
(1 + τmp)

Pour identifier A et τm, le plus simple est d’appliquer un échelon de tension et de façon synchrone, de stocker à chaque période d’échantillonnage la vitesse mesurée du moteur.

✔ Q.5.7-1 Créez dans votre code une table pouvant accueillir 500 entiers (variables globales) puis écrivez une routine d’interruption déclenchée sur évènement d’input-capture dans laquelle vous mémoriserez l’instant des fronts sur la voie A du codeur relié à l’un des moteurs. Seuls les instants d’un front sur trois seront mémorisés. Dans le programme principal, activez la PWM du moteur considéré avec un rapport cyclique de 0.75.

✔ Q.5.7-2 Placez un point d’arrêt dans la routine de telle sorte qu’il ne soit atteint qu’après remplissage de la table puis positionnez un watch dans MPLab®
sur la table. Exécutez ensuite votre programme.

✔ Q.5.7-3 Lorsque l’exécution stoppe sur le point d’arrêt, sauvez les données du watch au format csv (menu contextuel : Export Data|CSV file|Displayed format).

✔ Q.5.7-4 Exploitez ce fichier dans Matlab® afin d’identifier les paramètres de M(p). Vous pouvez réitérer

l’opération pour différents rapports cycliques et différentes charges (réalistes) sur l’arbre moteur.

### 5.7.1 Discrétisation de l’asservissement

L’implantation d’une commande numérique sur un microcontrôleur requiert de travailler avec une boucle d’asservissement numérique. Cela nécessite d’agir sur le système à période T e constante, et de définir une version discrête du correcteur. Concernant la période d’échantillonnage, plusieurs solutions sont envisageables :

M. COLAS/D. CARTON | 32

- Se baser sur le rythme de réception des octets de consigne depuis la carte de commande ;
- Définir une horloge propre à la carte moteur quitte à être asynchrone avec les changements de consigne.
✔ | Q.5.7-5 Compte tenu de l’identification menée en section 5.7, mais aussi d’autres considérations (ca- pacités de calcul du microcontrôleur, résolution des codeurs. . . ) discutez du choix d’une période d’échantillonnage adaptée à votre système.
| L’interface entre le système de commande numérique et le moteur par nature analogique utilise un convertisseur numérique-analogique dont la forme la plus simple est appelée bloqueur d’ordre 0. Celui-ci a pour effet de maintenir en sortie une valeur analogique constante sur toute la période d’échantillonnage égale à la valeur numérique d’entrée. Un bloqueur d’ordre 0 associé à une période d’échantillonnage T e a pour fonction de transfert : BOZ(p) = 1 − e −T ep p et en conséquence, la fonction de transfert discrête de l’ensemble constitué du bloqueur et du moteur est modélisée par :
| G(z) = (1 − z −1
)Z
| H(p) p
| = K 1 − z0 z − z0 avec z0 = e − T e τ
✔ | Q.5.7-6 Sur la base de l’équivalence d’expression de la dérivée dans l’espace en Z et celui de Laplace (sT e = 1 − z −1 ), donnez une expression en z du correcteur PID.
| Dans ce projet, on se limite à une correciton PI.
✔ | Q.5.7-7 Donnez un organigramme modélisant l’implantation détaillée du correcteur.
✔ | Q.5.7-8 Programmez ce correcteur pour chaque moteur.
✔ | Q.5.7-9 Adaptez la sortie de votre correcteur pour qu’elle puisse s’interfacer avec le dispositif de com- mande des moteurs (PWM).
| ☞ Attention : La programmation d’un correcteur incluant un intégrateur nécessite de prendre en considération les éventuels dépassements de capacité des variables utilisées dans l’algorithme ainsi que les limites min et max admissibles par la commande des moteurs.
✔ | Q.5.7-10 Déterminer les valeurs des gain P et I empiriquement ou en vous aidant d’une simulation. Matlab® .
✔ | Q.5.7-11 Testez le bon fonctionnement de la boucle d’asservissement d’un moteur à faible vitesse ou en appliquant sur l’axe un couple résistant variable lorsque la consigne est maintenue constante.
M. COLAS/D. CARTON | 33

## 6 Commande du robot et interface graphique

Si la section 4 constitue les yeux du robot et que la section 5 décrit ses jambes, cette partie s’intéresse à son cerveau. Il s’agit dans ce sous-projet d’atteindre les deux objectifs suivants :

- Concevoir une interface homme-machine destinée à reporter ou fixer les paramètres de fonctionnement et à mettre en action ou stopper le robot ;
- Programmer l’algorithme de suivi de ligne en tirant partie des informations de position délivrées par la partie capteurs et en fournissant la commande à la partie moteurs.

### 6.1 Développement électronique de l’interface homme-machine

L’IHM à développer est constituée d’un afficheur LCD alphanumérique de 3 lignes et 16 caractères par ligne ainsi que de trois boutons.

### 6.1.1 Afficheur LCD (séances 1 à 3)

L’afficheur est alimenté en 5V et piloté via une interface SPI. Le principe de fonctionnement et le cablage d’une interface SPI sont fournis en section 3.8. l’afficheur est équipé d’un rétro-éclairage indépendant qui doit être soudé et alimenté au travers d’une ou plusieurs résistances comme indiqué en page 2 de la datasheet du composant . (https://www.lcd-module.com/eng/pdf/doma/dog-me.pdf)

✔ | Q.6.1-1 Soudez le rétroéclairage aux broches de l’afficheur puis câblez-le sur plaquette Labdec confor- mément au shéma de la figure 28.
| ☞ Indications : On connectera un cable nappe à la carte micro-contrôleur sur laquelle on pren- dra soin d’isoler l’alimentation (utilisée pour alimenter l’afficheur), la masse ainsi que les signaux nécessaires au fonctionnement de l’écran LCD : SDO_PIC, CLK_PIC, RB0, RB1 et RB2. Pour cela, on pourra consulter le schéma électrique de la carte DSPIC (https://cours.univ-reims.fr/pluginfile.php/86193/mod_resource/content/1/Schema_de_la_carte_Dspic.pdf) . Un soin particulier doit être apporté à ce câblage pour éviter les confusions. En particulier : • la longueur des fils doit être limitée au maximum ; • leur couleur doit être choisie avec soin ; • si plusieurs broches consécutives sont fixées au même potentiel, le plus simple est d’utiliser des embases à broches au pas 2.54mm type (https://fr.rs-online.com/web/p/embases-circuits-imprimes/6007473) que l’on soudera entre-elles ; • les contacts non utilisés sur la nappe doivent absolument être isolés.

Validation du fonctionnement
La programmation de l’afficheur repose sur l’intégration à votre projet des fichiers LCD.c et LCD.h disponibles sur le Moodle II0601. Ces fichiers définissent les fonctions suivantes :
- void InitLCD(void) : paramétrage du bus SPI et des I/O utilisées par l’afficheur puis transmission des commandes d’initialisation ;
- void LCDDataWrite(char c) : affichage d’un caractére à l’emplacement courant du curseur ;
- void LCDWriteStr(char * str) : affichage d’une chaine de caractères à partir de l’emplacement courant du curseur ;
- void LCDGoto(unsigned int r, unsigned int c) : déplacement du curseur en ligne l et colonne c ;
- void LCDContrastSet(unsigned int c) : réglage du contraste de l’écran entre 0 (contraste nul) et 63 (contraste fort) ;
M. COLAS/D. CARTON | 34

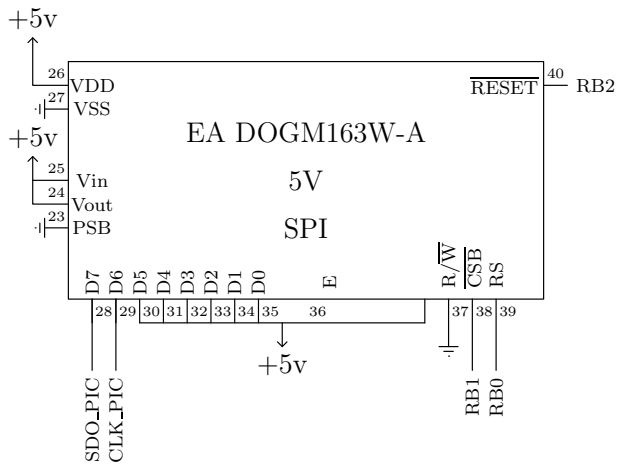
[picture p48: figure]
EA DOGM163W-A; SPI; VDD; VSS; Vin; Vout; PSB; SDO PIC; CLK PIC; RB1 CSB 38 RB0 RS 39; RESET

D7 28 D6 29 D5 30 D4 31 D3 32 D2 33 D1 34 D0 35

Fig. 28 : Câblage de l’afficheur LCD

- LCDDisplayOn() : activation de l’afficheur (et non du rétro-éclairage) ;
- LCDDisplayOff() : extinction de l’afficheur (et non du rétro-éclairage) ;
- LCDClearDisplay() : effacement de l’écran ;
- LCDHome() : retour du curseur en ligne 0 et colonne 0 (haut à gauche de l’écran).
✔ | Q.6.1-2 Créez un programme minimale inscrivant une chaine de caractères sur le première ligne de l’afficheur.
| 6.1.2 Boutons (séances 1 à 4) Afin que l’utilisateur puisse interagir avec l’IHM, il est proposé de mettre en place trois boutons dont les fonctionnalités sont les suivantes : • un bouton + destiné à incrémenter des valeurs numériques ou à sélectionner l’entrée précédente dans un menu ; • un bouton - destiné à décrémenter des valeurs numériques ou à sélectionner l’entrée suivante dans un menu ; • un bouton entrée servant à valider une valeur ou à sélectionner une entrée dans un menu. Un appui prolongé (plus d’une seconde) sur les touches + et - provoque un comptage continu au rythme de deux incréments par seconde. Ce rythme est triplé après trois secondes de pression continu et ce jusqu’au relachement du bouton.
✔ | Q.6.1-3 Choisir trois entrées sur le microcontrôleur puis câbler les boutons sur ces entrées.
| ☞ Indications : On utilisera des boutons de type DT6 ainsi qu’un tirage à 5V. Ce dernier sera cablé dans un premier temps à l’aide de résistances qui pourront ensuite être supprimées grâce à l’activation des pullup du micro-contrôleur sur les entrées sélectionnées (voir le paragraphe CN Control register de la section 11 du dsPIC30F Family reference manual ). (http://ww1.microchip.com/downloads/en/devicedoc/70046d.pdf)
✔ | Q.6.1-4 Programmez une fonction permettant d’initialiser les entrées du micro-contrôleur.
✔ | Q.6.1-5 Créez une fonction reportant l’état des boutons à l’écran. Un X représentera un bouton pressé et un O un bouton relaché.
M. COLAS/D. CARTON | 35

### 6.1.3 Réalisation de la carte sous Eagle®

(séances 5 à 7)

Il est fortement conseillé pour poursuivre de disposer d’une carte électronique sur circuit imprimé.

✔ Q.6.1-6 En utilisant :

- la librairie de composants , (https://cours.univ-reims.fr/pluginfile.php/86178/mod_folder/content/0/EEA0601-770-20190313.lbr?forcedownload=1)
- les consignes de réalisation prodiguées par vos enseignants,
- le mode d’emploi d’Eagle® , (https://cours.univ-reims.fr/mod/resource/view.php?id=18075)

disponibles sur le cours Moodle, réalisez le schéma de principe et le routage de la carte. Le typon sera réalisé en deux couches avec plan de masse sur la couche supérieure. On prendra soin de positionner les connecteurs en périphérie de la carte. Les boutons de type DT6 seront placés de sorte à faciliter l’utilisation de l’interface. Enfin, on tâchera de ne pas oublier les connecteurs de communication série de type SPOX permettant de s’interfacer aux cartes capteur et moteur.

☞ Informations :

- L’afficheur doit impérativement être monté sur support.
- N’utilisez jamais l’auto-routage ;
- Soyez rigoureux : composants positionnés du bon côté de la carte, pistes dimensionnées en fonction du courant qui y circule, présence de condensateurs de filtrage d’alimentation, angles des pistes à 45◦
, limitation du nombre de vias . . .
- Après | validation | par | l’enseignant, | vous | transmettrez | vos | fichiers | à
david.carton@univ-reims.fr | et/ou | maxime.colas@univ-reims.fr | pour
tirage de la carte.

✔ Q.6.1-7 Percez, placez puis soudez les composants avec soin.

### 6.2 Maquettage de l’IHM (séances 8 et 9)

La figure 29 propose un exemple d’enchaînement de menus adaptés au projet. Bien entendu toute évolution justifiée est recevable.
Dans cet exemple, le signe > représente un item de menu actif, c’est à dire pour lequel un appui sur la touche entrée provoque :
- une navigation vers un autre menu (e.g. item Action du menu racine) ;
- l’activation de la zone de saisie associée le cas échéant (e.g. item Gauche du menu Manuel) ;
- la sélection de l’item le cas échéant (e.g. item Vit. moteurs du menu Aff. etat) ;
- l’exécution d’une fonction (e.g. item Marche lente) du menu Action.

Lorsqu’une zone de saisie est activée, la variable numérique associée est modifiée à l’aide des touches + et -.
Le menu Aff. etat offre une sélection des mesures à afficher lorsque le robot est en action. Chaque type de mesure utilise un écran complet et il est donc proposé de prévoir un cyclage de l’affichage comme présenté sur la partie droite de la figure 29. Le menu Manuel est principalement destiné aux tests de fonctionnement. Il permet de modifier la consigne de chaque moteur entre 0 et 100%. La modification de ces consignes prend effet en cours de réglage, c’est à dire avant même l’appui sur la touche entree. Après appui sur cette touche, les valeurs de consigne sélectionnées sont conservées et l’affichage passe immédiatement en mode cyclage.

### 6.3 Programmation de la navigation

### 6.3.1 Gestion des touches

Concernant la gestion des appuis sur les touches, on propose d’utiliser la structure d’état suivante :

M. COLAS/D. CARTON | 36

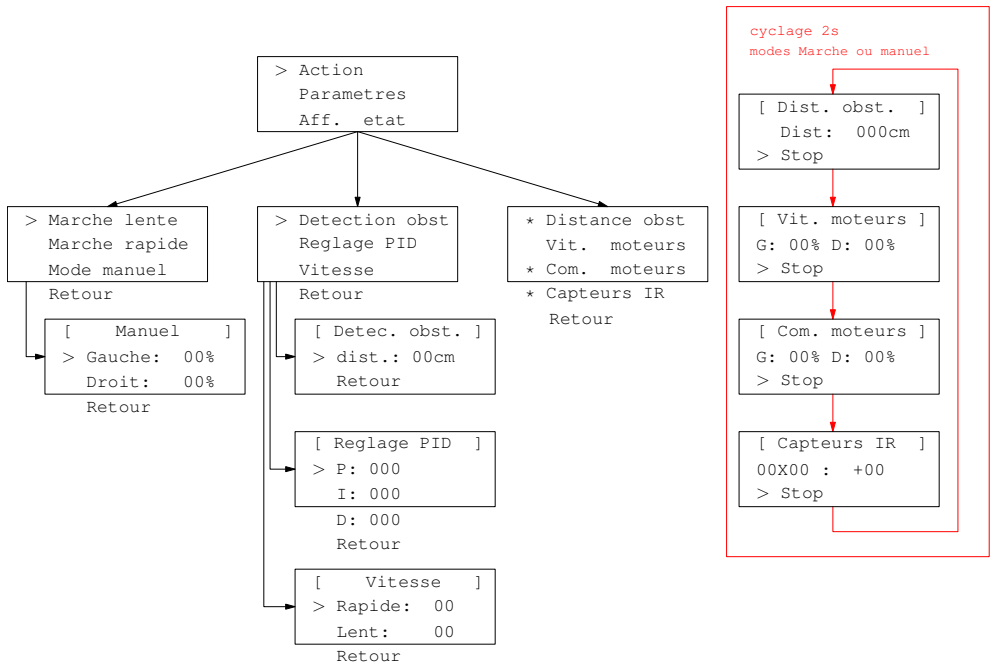
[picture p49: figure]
cyclage 2s; modes Marche ou manuel; [ Dist. obst.; Dist:; > Stop; [ Vit. moteurs ]; [ Com. moteurs ]; [ Capteurs IR; > Action; Parametres; Aff.; etat; > Marche lente; Marche rapide; Mode manuel; Retour; > Detection obst; Reglage PID; Vitesse; * Distance obst; Vit.; moteurs; * Com.; * Capteurs IR; Manuel; > Gauche:; Droit:; [ Detec. obst. ]; > dist.: 00cm; [ Reglage PID; > Rapide:; Lent:

Fig. 29 : Navigation offerte par l’interface graphique

1 | typedef struct {
2 | int upState : 2;
3 | int upEdge : 2;
4 | int downState : 2;
5 | int downEdge : 2;
6 | int enterState : 2;
7 | int enterEdge : 2;
8 | } Keyboard;
- upState, downState, enterState indique l’état respectif de ces boutons. Ces états peuvent prendre les valeurs suivantes : 0 : released, 1 : pressed, 2 : pressed1s, 2 : pressed3s où pressedxs indique un état enfoncé depuis plus de x secondes.
- upEdge, downEdge, enterEdge indique l’occurrence d’un front sur ces boutons. Les valeurs associées peuvent valoir : 0 : noEdge, 1 : risingEdge, 2 : fallingEdge.
✔ | Q.6.3-1 Créez une fonction void ihmKeyb(Keyboard *) non bloquante permettant de mettre à jour un élément de type Keyboard qui sera déclaré en portée globale.
| ☞ Indications : Pour les mesures de durée de pression, on utilisera la librairie ticks.c et ticks.h qui exploite le timer 1.
| 6.3.2 Gestion de l’afficheur La programmation de la navigation dans les menus de l’afficheur nécessite une approche structurée afin de conserver un code propre et évolutif. Pour cela, il est proposé de définir deux types : • le type Menu représente un écran de l’IHM :
M. COLAS/D. CARTON | 37

1 | typedef struct {
2 | char * title;
3 | Menu * root;
4 | MenuItem * items;
5 | short offset : 6;
6 | short selected : 2;
7 | } Menu;
| où
| – title représente le titre du menu. Il est insrit sur la première ligne entre crochets et ne peut
| se déplacer. Si le pointeur associé est nul, il n’y a pas de titre au menu et les trois lignes de
| l’afficheur sont alors utilisées pour présenter les items de menu.
| – root est un pointeur vers le menu parent ou celui vers lequel se brancher après appui sur la
| touche retour.
| – items pointe sur le tableau des items du menu. Ils sont affichés à partir de la seconde ligne de
| l’écran (si un titre est présent) et dans leur ordre d’apparition. Les items non visibles peuvent
| être affichés à l’aide des touches + et - par scrolling. Par exemple, l’item d’indice 2 du menu
| [ Reglage PID ] n’est initialement pas visible. Un premier appui sur sur - déplace le curseur
| de sélection > devant l’item 1 (I: 000) puis un second appui remplace l’item d’indice 0 par
| celui d’indice 1 et l’item d’indice 1 (P: 000) par celui d’indice 2 (D: 000).
| – offset mémorise le décalage vertical compté algébriquement (positif vers le haut) de l’item
| d’indice 0 par rapport à l’affichage initial du menu. Ainsi, suite aux opérations décrites ci-
| dessus, l’offset du menu vaut 1 .
| – selected indique la ligne de l’élément sélectionné : dans l’exemple précédent, selected vaut
| 2.
- le type MenuItem représente une entrée d’un menu :
1 | typedef struct {
2 | char * label;
3 | void * action;
4 | short type : 2;
5 | short checked : 1;
6 | } MenuItem;

– label est la chaine de caractère affichée à l’écran pour cette entrée du menu ;
– action est un pointeur dont la signification dépend de la valeur du champ type ;
– type peut prendre les valeurs suivantes : 0 : selectable, 1 : function, 2 : submenu ou 3:value. selectable désigne une entrée commutable par appui sur la touche entrée. Lorsqu’une telle entrée est active, elle est précédée d’une étoile (*) et d’une espace dans le cas contraire. function indique qu’action est un pointeur vers une fonction à exécuter sur appui de la touche entrée. submenu indique qu’action est un sous-menu à afficher sur appui de la touche entrée, enfin value indique une valeur numérique modifiable et dans ce cas, action pointe vers une structure de type MenuValue décrite ci-dessous.
– checked indique soit un item sélectionné (type selectable) ou une action engagée (type action.

Le type MenuValue est définit comme suit :

1 | typedef struct {
2 | int tuningValue;
3 | int * tunedValue;
4 | int min;
5 | int max;
6 | short type;
7 | } MenuValue;
M. COLAS/D. CARTON | 38

où type peut valoir :

- 0:direct : ce paramétrage indique une variable à évolution immédiate , i.e. dont la grandeur pilotée change instantanément lors du réglage ;
- 1:batch : ce paramétrage indique une variable dont l’évolution ne sera prise en compte qu’après appui sur la touche entrée.

tuningValue correspond à la valeur temporaire de la grandeur pilotée (mode batch). tunedValue est la variable abritant la grandeur pilotée. min et max indiquent respectivement les valeurs minimales et maximales admissibles sur la grandeur pilotée.

✔ | Q.6.3-2 Déclarez un tableau d’éléments Menu au niveau de visibilité global ainsi que les tableaux d’items associés afin d’implémenter l’enchaînement des écrans présentés sur la branche gauche de la figure
| 29.
✔ | Q.6.3-3 Créez une fonction non bloquante void ihmScreen() de gestion de l’état de l’afficheur pour ces mêmes menus.
| ☞ Indications : On utilisera une variable d’indexation statique permettant de mémoriser l’état de la navigation dans l’interface. En cas de sélection d’un item d’action, cet index sera fournit en argument à la fonction action.
✔ | Q.6.3-4 Ajoutez à votre fonction void ihmScreen() la capacité de gestion d’un item de type value et testez cette fonctionnalité sur le menu Manuel.
✔ | Q.6.3-5 Implémentez le menu Aff. etat et étendez votre fonction void ihmScreen() afin qu’elle gère le type selectable.
✔ | Q.6.3-6 Terminer le développement de votre fonction par la gestion du cyclage.
| ☞ Indications : Le cyclage pourra être implaté sous la forme d’une fonction void cyclicView(Menu *) gérant à la fois la liste des états à afficher, l’état courant, le timing de l’affichage et les actions associées à l’item Stop en fonction des items sélectionnés dans le menu dont l’adresse est passée en argument.

### 6.4 Pilotage du robot (séance 10)

| Lorsque le mode Marche lente ou Marche rapide est actif, le pilotage du robot consiste à exécuter de manière récurrente une routine d’asservissement numérique destinée à maintenir le robot au centre de la ligne représentant la trajectoire souhaitée. Dans ces conditions, la consigne peut être considérée comme une constante nulle représentant la distance souhaitée entre l’axe du robot et la ligne et les méandres de la ligne au sol comme une perturbation du système régulé. Le cadencement de la boucle peut être basé sur le rythme de réception des informations capteur.
| 6.4.1 Lecture de l’information de position Les informations de position en provenance de la carte capteur sont encodées selon le protocole décrit en section 4.3.2 et sur la figure 20.
✔ | Q.6.4-1 Programmez une fonction permettant de lire les informations transmises par la carte capteur.
| 6.4.2 Transmission de la commande des moteurs
| Les informations de commande des moteurs sont communiquées par liaison série à cette carte selon un protocole en section 5.5.1 ainsi que sur la figure 26.
✔ | Q.6.4-2 Proposez une fonction permettant de transmettre ces informations à la carte moteur.
M. COLAS/D. CARTON | 39
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

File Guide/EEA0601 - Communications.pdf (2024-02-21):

# Communications cartes microcontrôleurs du robot mobile

### 1. FORMAT DES COMMUNICATIONS

### 1.1. De la carte capteurs vers la carte commande

La carte capteurs doit envoyer, au moins 10 fois par seconde, deux types de message à la carte commande :

- le premier contient l’information du décalage du robot par rapport à la ligne,
- le second l’information de distance d’un éventuel obstacle devant le robot.

La communication est réalisée au moyen d’une liaison série de type RS232.

Quelle que soit les solutions technologiques retenues pour la mise en place des capteurs, et par soucis d’interopérabilité entre les différentes cartes capteurs et les différentes cartes commande, les messages sont toujours constitués d’un octet sur 8 bits.

Le bit de poids fort représente le type de message :

- 0 : décalage par rapport à la ligne ;
- 1 : distance de l’obstacle.

Les 7 bits suivants représentent la donnée transmise :

- l’écart par rapport à la ligne est un entier signé ;
- la distance de l’obstacle est un entier non signé.

L’écart par rapport à ligne est codé selon le tableau suivant :

Donnée transmise | Signification
-64 | Le robot ne voit plus la ligne et il l’a quittée par la droite.

-63

-62 | Le robot est décalé à droite de la ligne de 62 mm.
⁞ | ⁞
-1 | Le robot est décalé à droite de la ligne de 1 mm.
0 | Le robot est centré sur la ligne
1 | Le robot est décalé à gauche de la ligne de 1 mm.
⁞ | ⁞
62 | Le robot est décalé à gauche de la ligne de 62 mm.
63 | Le robot ne voit plus la ligne et il l’a quittée par la gauche.

La distance de l’obstacle est codée selon le tableau suivant :

Donnée transmise | Signification
0 | Le robot se trouve à 0 cm de l’obstacle.
1 | Le robot se trouve à 0,5 cm de l’obstacle.
⁞ | ⁞
126 | Le robot se trouve à 63 cm de l’obstacle.
127 | Le robot se trouve à plus de 63 cm d’un obstacle.

### 1.2. De la carte commande vers la carte moteurs

La carte commande doit envoyer, au moins 10 fois par seconde, deux types de message à la carte moteurs :

- le premier contient l’information de vitesse linéaire du robot,
- le second l’information de vitesse de rotation autour de son centre du robot.

La communication est réalisée au moyen d’une liaison série de type RS232.

Quelle que soit les solutions technologiques retenues pour la réalisation de la carte moteur, et par soucis d’interopérabilité entre les différentes cartes moteurs et les différentes cartes commande, les messages sont toujours constitués d’un octet sur 8bits.

Le bit de poids fort représente le type de message :

- 0 : vitesse linéaire du robot ;
- 1 : vitesse de rotation sur lui-même du robot.

Les 7 bits suivants représentent la donnée transmise :

- la vitesse linéaire est un entier signé ;
- la vitesse de rotation est aussi un entier signé.

La vitesse linéaire est codée selon le tableau suivant :

Donnée transmise | Signification
63 | La vitesse linéaire est +1,26 km/h (marche avant)
⁞ | ⁞
1 | La vitesse linéaire est +0,02 km/h (marche avant).
0 | La vitesse linéaire est de 0 km/h (arrêt)
-1 | La vitesse linéaire est -0,02 km/h (marche arrière).
⁞ | ⁞
-64 | La vitesse linéaire est -1,28 km/h (marche arrière).

La vitesse de rotation est codée selon le tableau suivant :

Donnée transmise | Signification
63 | La vitesse de rotation est de +126 °/s (rotation vers la gauche).
⁞ | ⁞
1 | La vitesse linéaire est +2 °/min (rotation vers la gauche).
0 | La vitesse de rotation est de 0 °/s (arrêt)
-1 | La vitesse linéaire est -2 °/s (rotation vers la droite).
⁞ | ⁞
-64 | La vitesse linéaire est -128 °/s (rotation vers la droite).

### 2. ASPECTS PHYSIQUES DE LA COMMUNICATION

Pour des soucis d’interopérabilité toutes les cartes utiliseront le même protocole, la même vitesse de transmission et les mêmes connecteurs.

### 2.1. Support de transmission

Au regard de faibles distances (quelques centimètres) et des débits réduits la liaison entre deux cartes microcontrôleurs se fera au moyen d’un câble à 2 conducteurs.

### 2.2. Ressources des microcontrôleurs

Les communications seront réalisées (en émission et en réception) au moyen du module UART des microcontrôleurs.

### 2.3. Caractéristique de la communication

- Protocole : Série, 8 bits de données, 1 bit de stop, pas de bit de parité
- Vitesse de transmission : 9600 bauds,

### 2.4. Format des connecteurs

Connecteur Molex 22035025 (https://www.molex.com/molex/products/part-detail/pcb_headers/0022035025) à deux contacts :

- Le contact n° 1 sera utilisé par le potentiel de référence, en l’occurrence la masse
- Le contact n° 2 sera utilisé pour le signal

### 3. RESSOURCES LOGICIEL POUR LA PROGRAMMATION DES

MICROCONTRÔLEURS

La libraire « periph_uart » disponible sur le moodle de EEA0601 fournit différentes fonctions (routines) pour initialiser les communications ainsi que pour envoyer et recevoir des messages au moyens des UART des microcontrôleurs.

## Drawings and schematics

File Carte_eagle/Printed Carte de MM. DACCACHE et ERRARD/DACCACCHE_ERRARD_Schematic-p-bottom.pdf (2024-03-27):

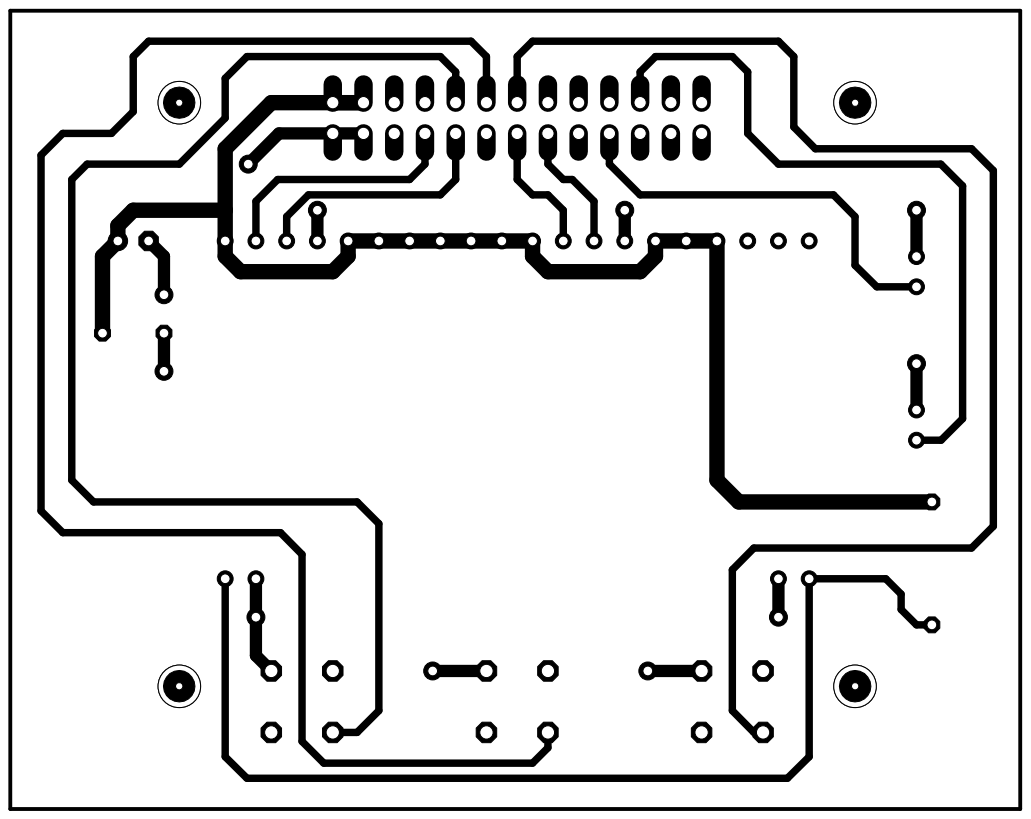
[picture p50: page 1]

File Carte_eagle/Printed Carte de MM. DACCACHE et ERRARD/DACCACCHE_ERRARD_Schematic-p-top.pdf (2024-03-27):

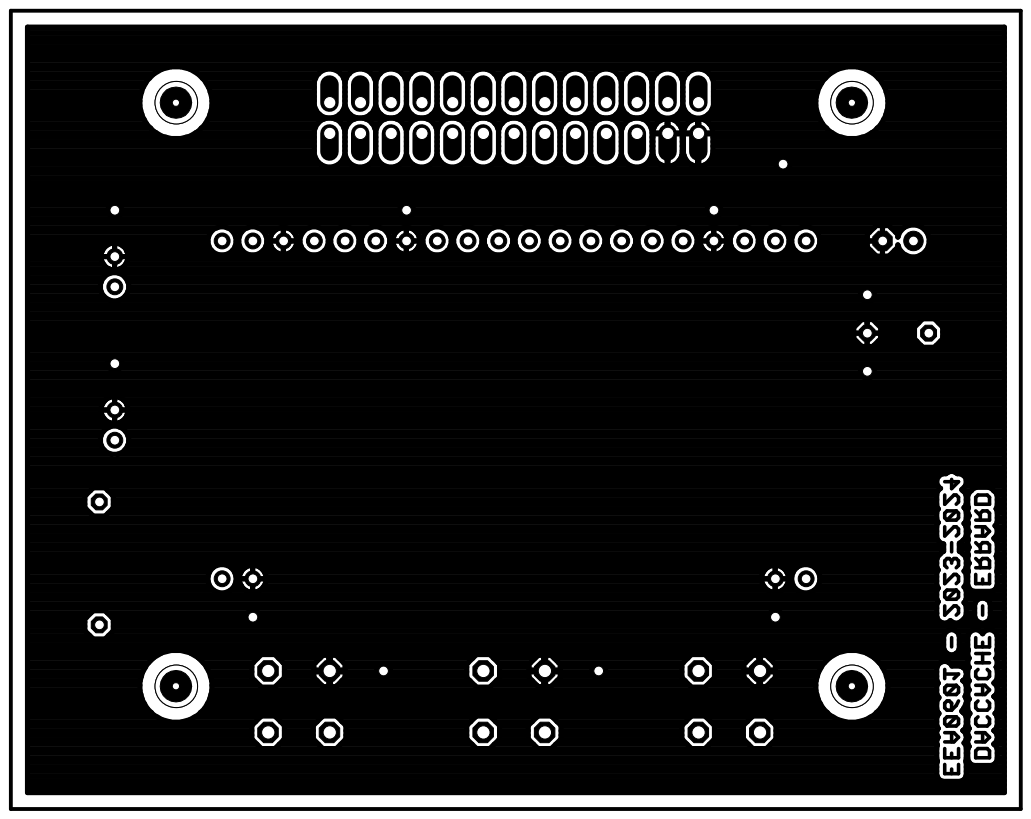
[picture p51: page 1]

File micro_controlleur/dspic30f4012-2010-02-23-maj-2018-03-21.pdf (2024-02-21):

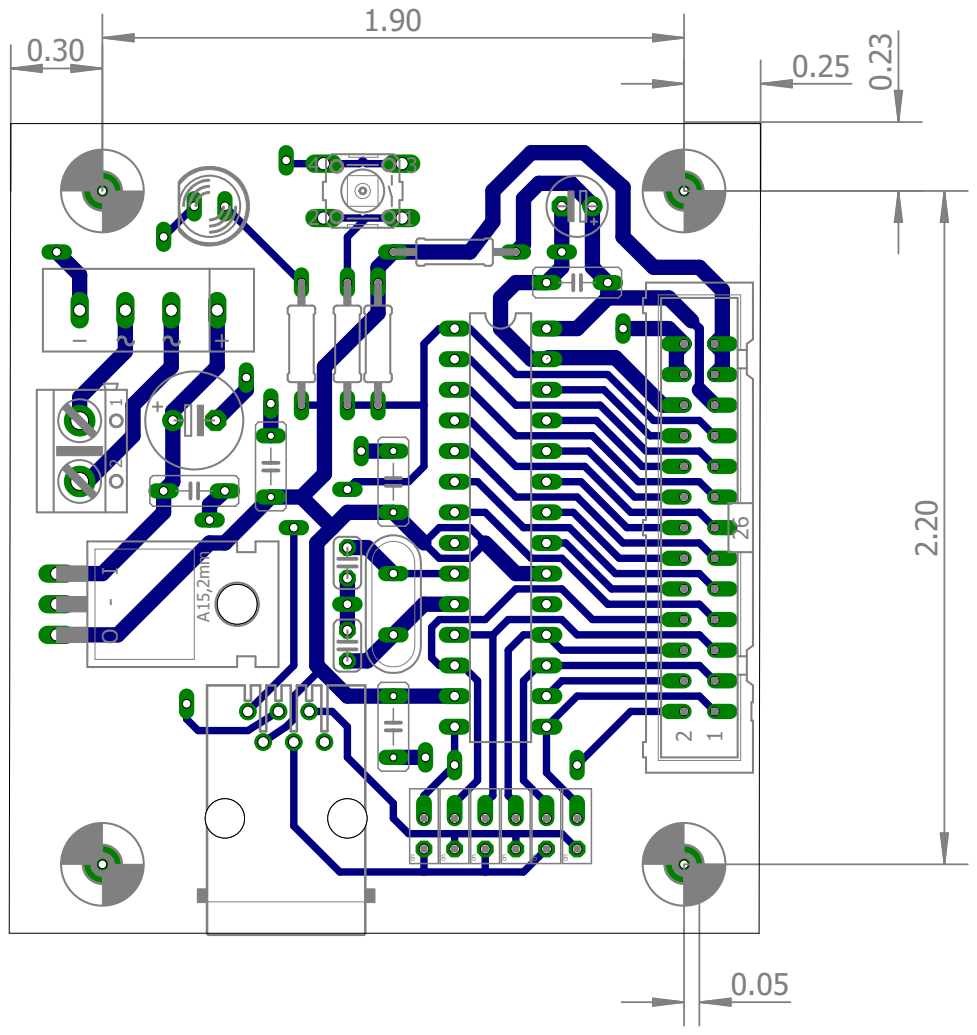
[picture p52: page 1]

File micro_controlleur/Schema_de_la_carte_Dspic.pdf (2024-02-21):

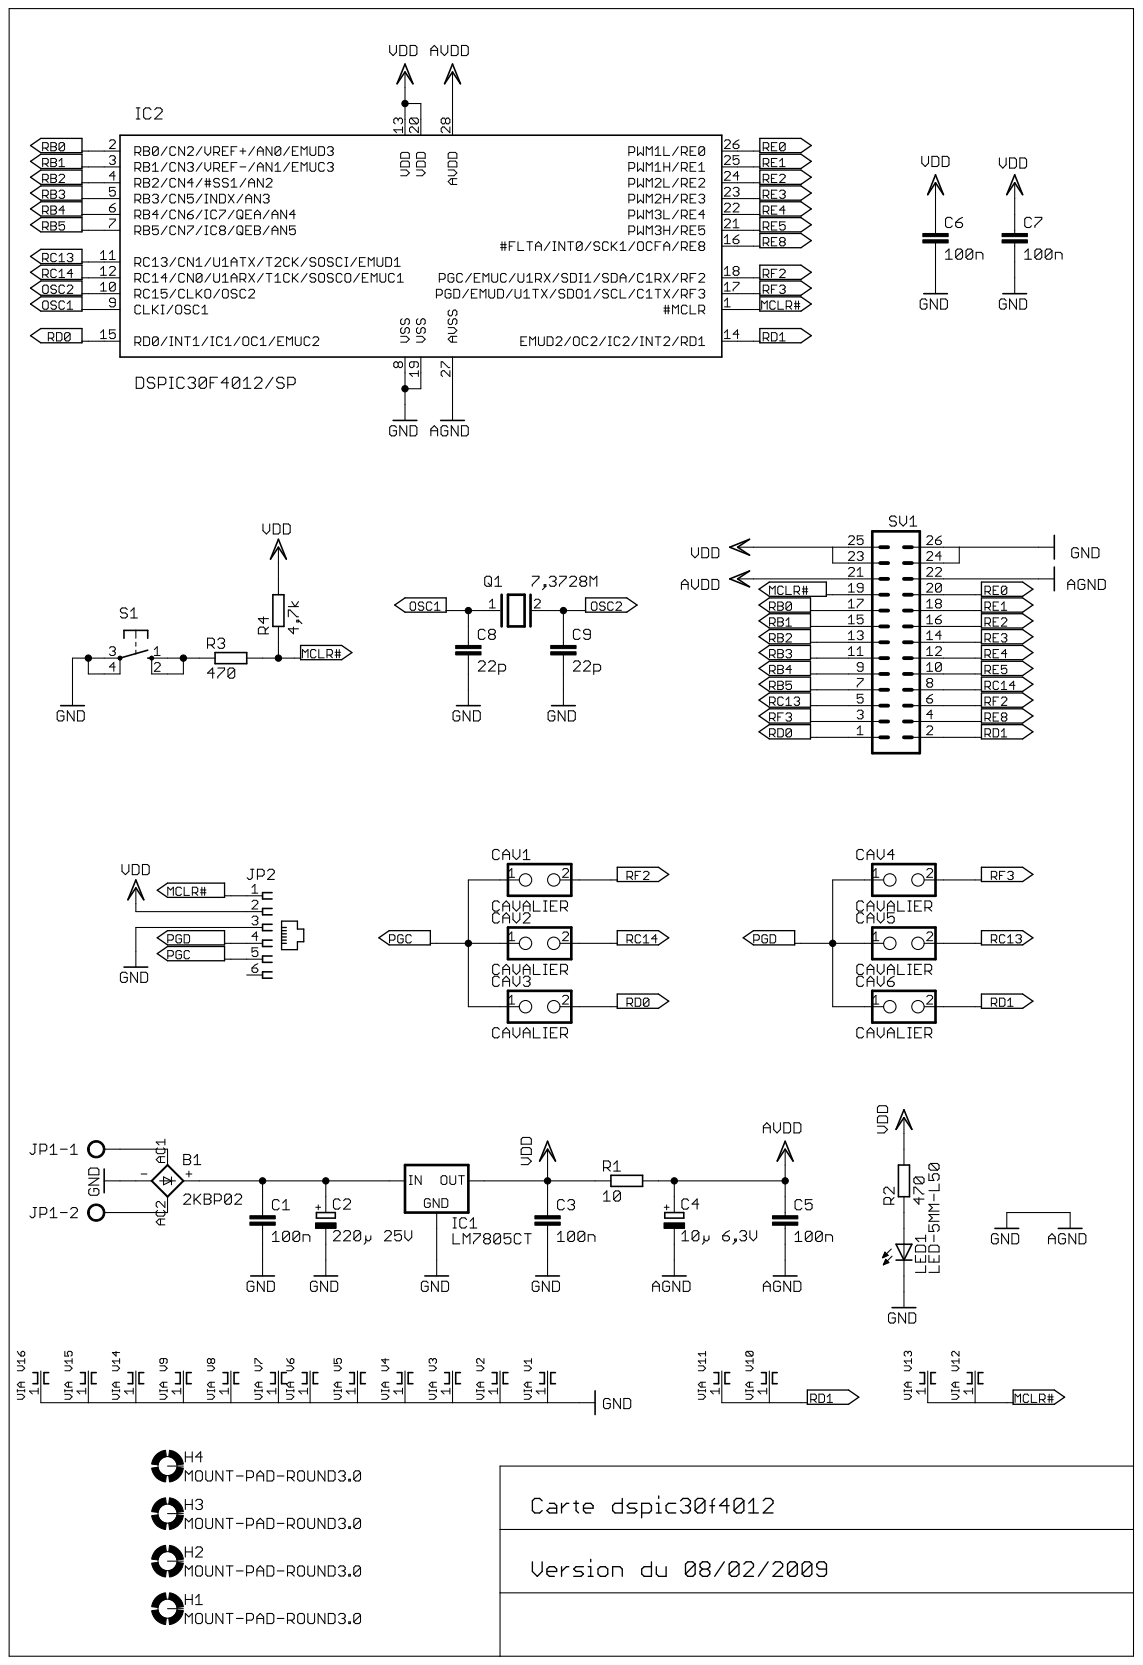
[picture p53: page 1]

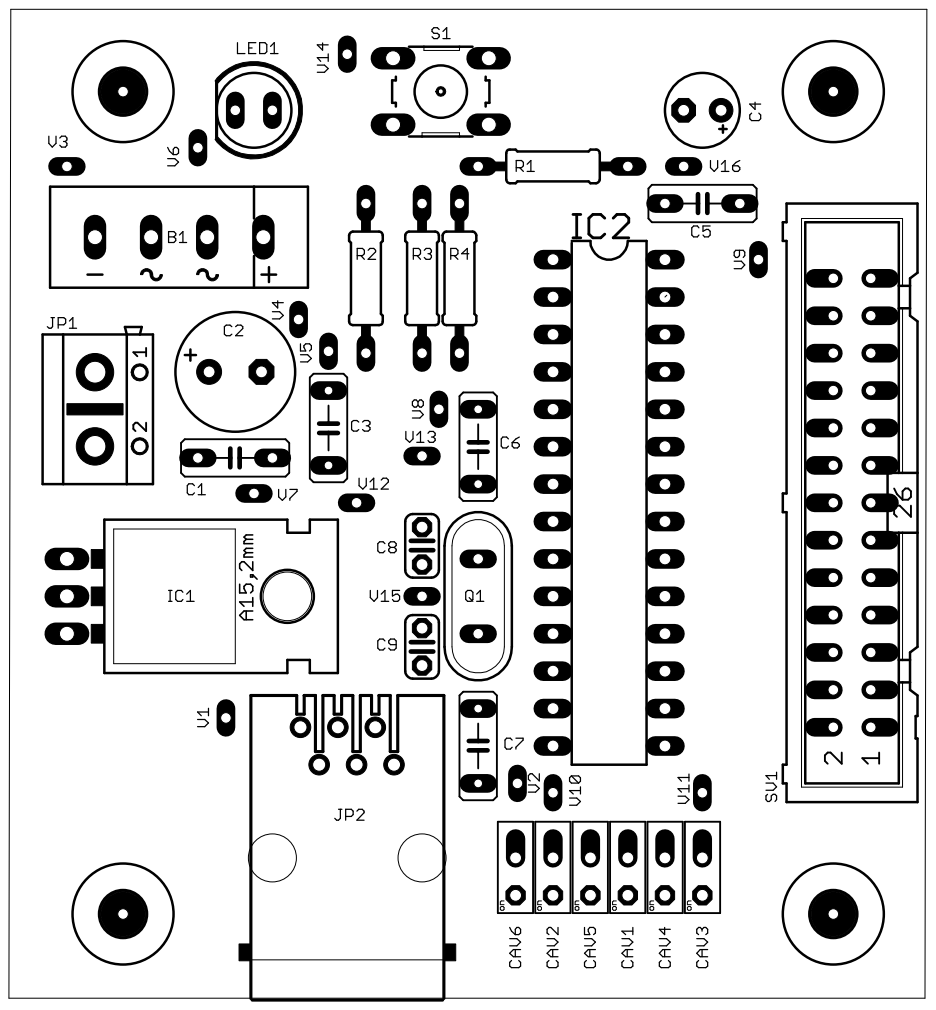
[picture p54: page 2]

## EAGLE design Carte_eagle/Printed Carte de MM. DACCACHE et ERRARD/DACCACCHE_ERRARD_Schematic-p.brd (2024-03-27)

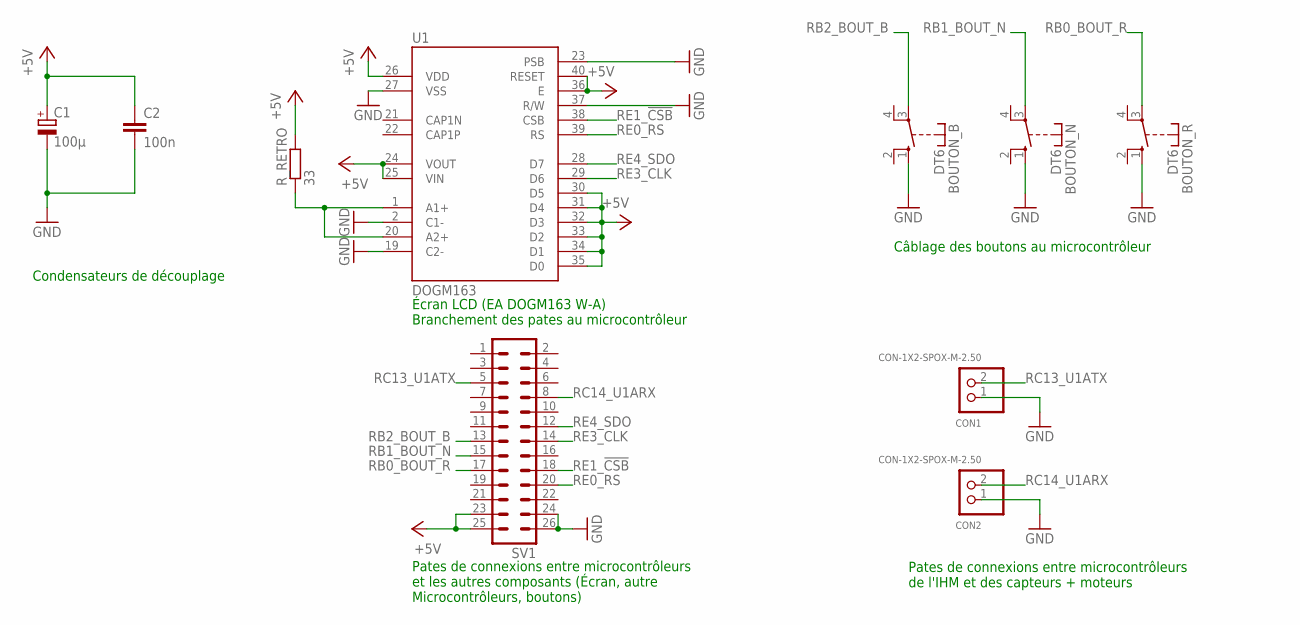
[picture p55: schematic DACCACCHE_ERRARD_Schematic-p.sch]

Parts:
BOUTON_B: DT6
BOUTON_N: DT6
BOUTON_R: DT6
C1: 100µ; E2,5-7
C2: 100n; C050-030X075
CON1, CON2: CON-1X2-SPOX-M-2.50; SPOX-M-2.50-02
R_RETRO: 33; 0207/10
SV1: ML26
U1: DOGM163; DOGM

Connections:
+5V: C1.+, C2.1, R_RETRO.2, SV1.23, SV1.25, U1.24 (VOUT), U1.25 (VIN), U1.26 (VDD), U1.30 (D5), U1.31 (D4), U1.32 (D3), U1.33 (D2), U1.34 (D1), U1.35 (D0), U1.36 (E), U1.40 (RESET)
GND: BOUTON_B.1 (S), BOUTON_N.1 (S), BOUTON_R.1 (S), C1.-, C2.2, CON1.1, CON2.1, SV1.24, SV1.26, U1.2 (C1-), U1.19 (C2-), U1.23 (PSB), U1.27 (VSS), U1.37 (R/W)
RB0_BOUT_R: BOUTON_R.3, SV1.17
RB1_BOUT_N: BOUTON_N.3, SV1.15
RB2_BOUT_B: BOUTON_B.3, SV1.13
RC13_U1ATX: CON1.2, SV1.5
RC14_U1ARX: CON2.2, SV1.8
RE0_RS: SV1.20, U1.39 (RS)
RE1_!CSB: SV1.18, U1.38 (CSB)
RE3_CLK: SV1.14, U1.29 (D6)
RE4_SDO: SV1.12, U1.28 (D7)
RHETRO_RES: R_RETRO.1, U1.1 (A1+), U1.20 (A2+)

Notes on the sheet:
Écran LCD (EA DOGM163 W-A) Branchement des pates au microcontrôleur
Câblage des boutons au microcontrôleur
Pates de connexions entre microcontrôleurs de l'IHM et des capteurs + moteurs
Pates de connexions entre microcontrôleurs et les autres composants (Écran, autre Microcontrôleurs, boutons)
Condensateurs de découplage

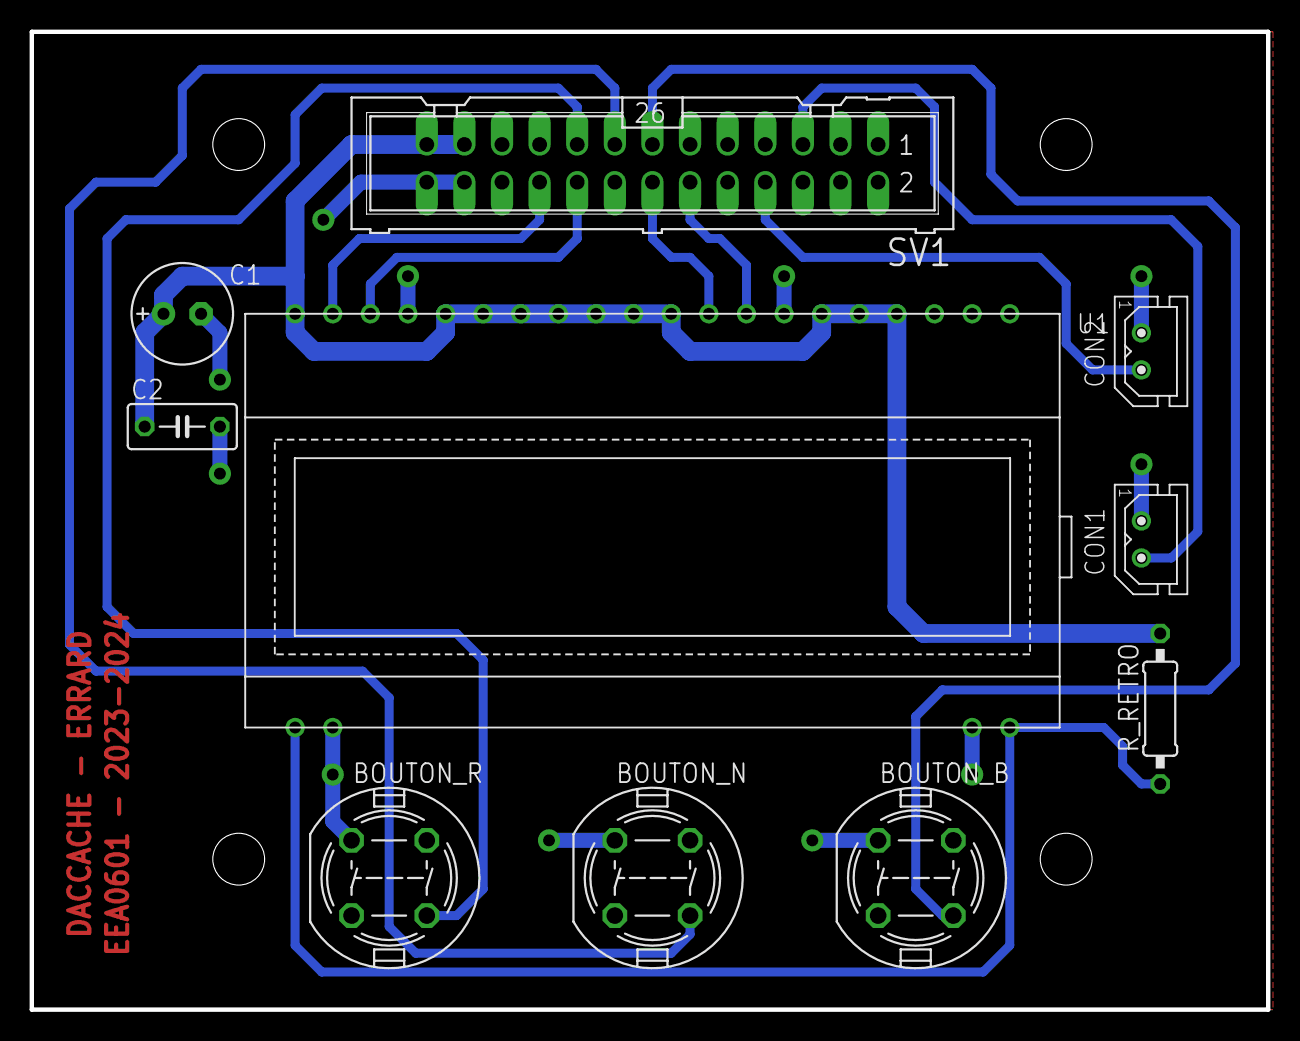
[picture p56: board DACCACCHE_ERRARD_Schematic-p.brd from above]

Board: 2 copper layers, 83.5 x 66.0 mm, 10 parts (0 on the bottom side), 12 nets.

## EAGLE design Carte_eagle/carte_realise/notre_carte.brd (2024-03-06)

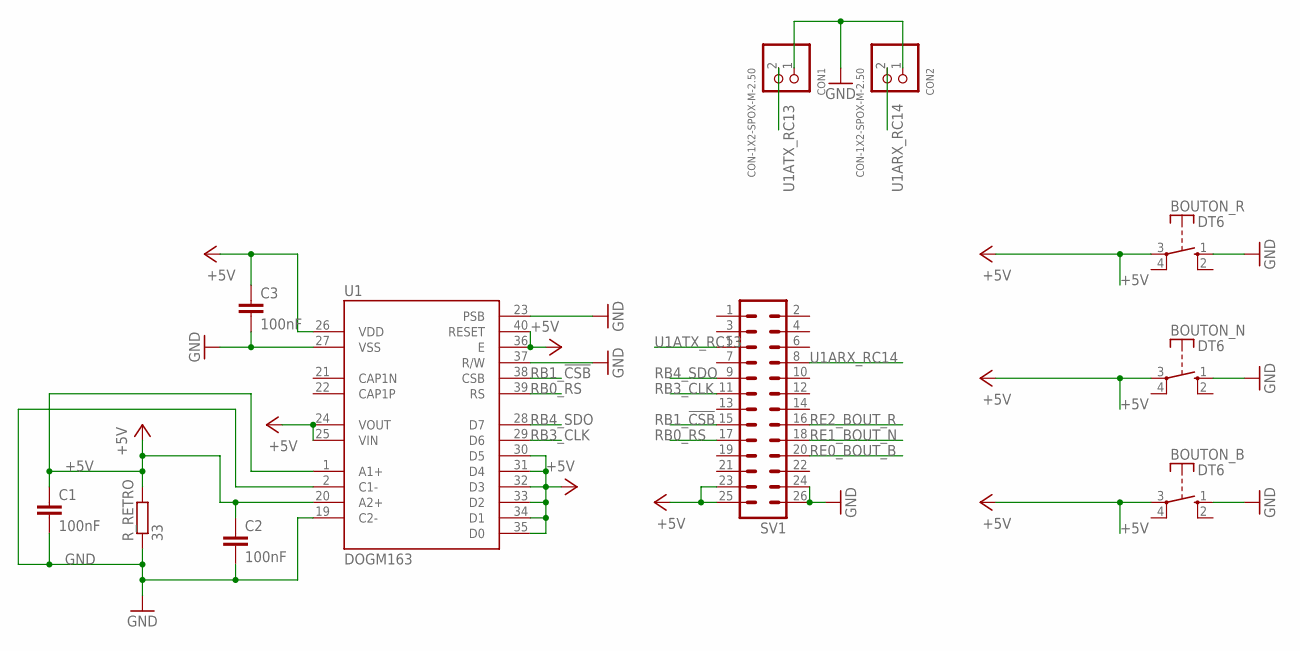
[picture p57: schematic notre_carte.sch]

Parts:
BOUTON_B: DT6
BOUTON_N: DT6
BOUTON_R: DT6
C1, C2, C3: 100nF; C025-025X050
CON1, CON2: CON-1X2-SPOX-M-2.50; SPOX-M-2.50-02
R_RETRO: 33; 0207/15
SV1: ML26
U1: DOGM163; DOGM

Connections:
+5V: BOUTON_B.3, BOUTON_N.3, BOUTON_R.3, C1.1, C2.1, C3.1, R_RETRO.2, SV1.23, SV1.25, U1.1 (A1+), U1.20 (A2+), U1.24 (VOUT), U1.25 (VIN), U1.26 (VDD), U1.30 (D5), U1.31 (D4), U1.32 (D3), U1.33 (D2), U1.34 (D1), U1.35 (D0), U1.36 (E), U1.40 (RESET)
GND: BOUTON_B.1 (S), BOUTON_N.1 (S), BOUTON_R.1 (S), C1.2, C2.2, C3.2, CON1.1, CON2.1, R_RETRO.1, SV1.24, SV1.26, U1.2 (C1-), U1.19 (C2-), U1.23 (PSB), U1.27 (VSS), U1.37 (R/W)
RB0_RS: SV1.17, U1.39 (RS)
RB1_!CSB: SV1.15, U1.38 (CSB)
RB3_CLK: SV1.11, U1.29 (D6)
RB4_SDO: SV1.9, U1.28 (D7)
RE0_BOUT_B: SV1.20
RE1_BOUT_N: SV1.18
RE2_BOUT_R: SV1.16
U1ARX_RC14: CON2.2, SV1.8
U1ATX_RC13: CON1.2, SV1.5

Board: 2 copper layers, 11 parts (0 on the bottom side), 8 nets, no tracks yet.

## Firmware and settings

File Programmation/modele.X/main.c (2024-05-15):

/*============================================================================*/
/* Programme de test de la carte microcontrôleur dspic30f4012                 */
/* ----------------------------------------------------------                 */
/* Environnement : IDE : MPLAX X                                              */
/*                 Compilateur C : XC16                                       */
/* Le programme :                                                             */
/*   - utilise un mécanisame d'interruption lié au timer 3 pour faire         */
/*     osciller la patte RB0 du port B ;                                      */
/*   - utilise le module PWM pour générer un signal impulsion sur la patte    */
/*      RE0 du port E.                                                        */
/*                                                                            */
/* 2023.02.08                                                                 */
/* DRHC & MC                                                     */
/*============================================================================*/

/******************************************************************************/
/* DSPIC30F4012 Configuration Bit Settings                                    */
/******************************************************************************/

// FOSC
#pragma config FPR = XT_PLL16          // Primary Oscillator Mode (XT w/PLL 16x)
#pragma config FOS = PRI               // Oscillator Source (Primary Oscillator)
#pragma config FCKSMEN = CSW_FSCM_OFF  // Clock Switching and Monitor (Sw 
                                       // Disabled, Mon Disabled)

// FWDT
#pragma config FWPSB = WDTPSB_16        // WDT Prescaler B (1:16)
#pragma config FWPSA = WDTPSA_512       // WDT Prescaler A (1:512)
#pragma config WDT = WDT_OFF            // Watchdog Timer (Disabled)

// FBORPOR
#pragma config FPWRT = PWRT_64          // POR Timer Value (64ms)
#pragma config BODENV = BORV20          // Brown Out Voltage (Reserved)
#pragma config BOREN = PBOR_ON          // PBOR Enable (Enabled)
#pragma config LPOL = PWMxL_ACT_HI      // Low-side PWM Output Polarity (Active 
                                        // High)
#pragma config HPOL = PWMxH_ACT_HI      // High-side PWM Output Polarity (Active
                                        // High)
#pragma config PWMPIN = RST_IOPIN       // PWM Output Pin Reset (Control with 
                                        // PORT/TRIS regs)
#pragma config MCLRE = MCLR_EN          // Master Clear Enable (Enabled)

// FGS
#pragma config GWRP = GWRP_OFF          // General Code Segment Write Protect 
                                        // (Disabled)
#pragma config GCP = CODE_PROT_OFF      // General Segment Code Protection 
                                        // (Disabled)

// FICD
#pragma config ICS = ICS_PGD            // Comm Channel Select (Use PGC/EMUC and
                                        // PGD/EMUD)

// #pragma config statements should precede project file includes.


/******************************************************************************/
/* Files to Include                                                           */
/******************************************************************************/

/* Device header file */
#include <xc.h>
#include "p30f4012.h"
#include <stdint.h>             /* Includes uint16_t definition               */
#include <stdbool.h>            /* Includes true/false definition             */
#include "./lib/periph_gen.h"
#include "./lib/periph_tmr.h"
#include "./lib/periph_pwm.h"
#include "./lib/LCDv3.h"
#include "./lib/fonctions_sup.h"
#include "./lib/ticks.h"

/******************************************************************************/
/* Définition des équivalences                                                */
/******************************************************************************/

#define TIMEBASE (Fcy/1000)

/******************************************************************************/
/* Global Variable Declaration                                                */
/******************************************************************************/
#define CONTRAST 40 //0 pour faible et 63 pour max
Keyboard *myKeyboardptr;
Keyboard myKeyboard;


/******************************************************************************/
/* Routines d'interruptions                                                   */
/******************************************************************************/

void initCN(void)
{
    //tris deja fait
    CNEN1bits.CN2IE=1;
    CNEN1bits.CN3IE=1;
    CNEN1bits.CN4IE=1;
}

void CNInterruptEnable(void)
{
    IFS0bits.CNIF=0;   // RAZ flag interruption
    IEC0bits.CNIE=1;   // autorisation interruption 
}
/*----------------------------------------------------------------------------*/
/* Routine d'interruption du timer 3                                          */
/*----------------------------------------------------------------------------*/

void __attribute__((__interrupt__,no_auto_psv)) _T3Interrupt( void )
{
  // Déclaration des variables de la routine d'interruption
  // Par exemple : static unsigned int i = 0;

  // Code de la routine d'interruption
  PORTBbits.RB0 = ~PORTBbits.RB0;  
    
  // Acquitement de l'interruption
  IFS0bits.T3IF=0;  //raz flag

} // Fin du code de la routine d'interruption

/*----------------------------------------------------------------------------*/
/* Routine d'interruption du timer 3                                          */
/*----------------------------------------------------------------------------*/

void __attribute__(( __interrupt__ ,__auto_psv__ )) _CNInterrupt(void) {
    
    if(detect_button_press(1))
    {
        myKeyboardptr->upEdge=1;
        myKeyboardptr->upState=1;
    }
    else if(!detect_button_press(1))
    {
        myKeyboardptr->upEdge=0;
        myKeyboardptr->upState=0;
    }
    if(detect_button_press(2))
    {
        myKeyboardptr->downEdge=1;
        myKeyboardptr->downState=1;
    }
    else if(!detect_button_press(2))
    {
        myKeyboardptr->downEdge=0;
        myKeyboardptr->downState=0;
    }
    if(detect_button_press(3))
    {
        myKeyboardptr->enterEdge=1;
        myKeyboardptr->enterState=1;
    }
    else if(!detect_button_press(3))
    {
        myKeyboardptr->enterEdge=0;
        myKeyboardptr->enterState=0;
    }
  
    
    IFS0bits.CNIF=0;
}



// Fin du code de la routine d'interruption

/******************************************************************************/
/* Programme principal (main program)                                         */
/******************************************************************************/

//initialisation des pates RE0, RE1 et RE2 aux boutons 1, 2 et 3
#define BUTTON1_PIN   PORTBbits.RB0  // Bouton 1 connecter a RB0
#define BUTTON2_PIN   PORTBbits.RB1  // Bouton 2 connecter a RB1
#define BUTTON3_PIN   PORTBbits.RB2  // Bouton 3 connecter a RB2

//fonction d'initialisation des pins RE0, RE1, RE2
void init_pins() {
    TRISBbits.TRISB0 = 1; // Configure RB0 comme une entree du bouton 1
    TRISBbits.TRISB1 = 1; // Configure RB1 comme une entree du bouton 2
    TRISBbits.TRISB2 = 1; // Configure RB2 comme une entree du bouton 3
    //les 3 lignes de code suivantes sont utiliser pour activer les pull up resistors pour RE0, RE1 et RE2
    CNPU1bits.CN2PUE = 1;       // Enable pull-up resistor for RB0
    CNPU1bits.CN3PUE = 1;       // Enable pull-up resistor for RB1
    CNPU1bits.CN4PUE = 1;       // Enable pull-up resistor for RB2  
}

int16_t main(void)
{
    /* -----------------------------------------------------------------------*/
    /* Configurations (notamment des périphériques)                           */
    /* -----------------------------------------------------------------------*/

    // Configuration du port B
    ADPCFG = 0xFFFF;     // Configuration des pattes du port B comme entrées
                         // sorties numériques (par défaut entrées analogiques)
    TRISB = 0b11111110;  // Initialisation de la patte RB0 du port B en sortie, 
                         // les autres en entrées 
    PORTB = 0;           // Mise à zéro des pattes en sorties du port B
    
    //Configurqtion du port E
    
    // Initialisation timer 3 - interruption à la milliseconde
    //InitTimer3(TIMEBASE);    // Initialisation du timer 3
   // Timer3InterruptEnable(); // Autorisation de l'interruption liée au timer 3

    // Initialisation de la PWM : 1ms
    //InitPWM(461,PEN1L);  // Initialisation du module PWM      
    //PWMEnable(ON);       // Mise en route de la PWM
    //PWM1PulseWidth(115); // Réglage du rapport cyclique
    
    /* -----------------------------------------------------------------------*/
    /* Code principal de l'application                                                  */
    /* -----------------------------------------------------------------------*/
    initTime();
    init_pins();                        //initialisation des pins
    InitLCD();                          //initialisation de l'ecran
    LCDDisplayOn();                     //on allume l'ecran
    LCDContrastSet(CONTRAST);           //on defini la luminosite avec contrast 
    LCDGoto(0,0);                       //Commence a ecrire sur l'ecran a la case 0,0
    LCDWriteStr("XXXXXXXXXXXXXXXX");
    LCDGoto(1,0);                       //Commence a ecrire sur l'ecran a la case 1,0
    LCDWriteStr("XX Demarrage! XX");
    LCDGoto(2,0);                       //Commence a ecrire sur l'ecran a la case 1,0
    LCDWriteStr("XXXXXXXXXXXXXXXX");
    delay_en_s(1);                         //pause de 5s    
    int xxx=1;
    //fonction de declanchement de l'interface du menu
    
    //fin de la fonction menu
    
     //debut init de l'interruption de CN
    initCN();
    IFS0bits.CNIF=0;
    CNInterruptEnable();
    myKeyboardptr=&myKeyboard;
    menu_principale(myKeyboardptr);
     //fin init de l'interruption de CN
    LCDClearDisplay();
    
    do{                                 //boucle d'initiation de test
        Time tm7 = getTime();
        while (myKeyboardptr->enterEdge==1)
        {
            LCDGoto(0,0);                       //Commence a ecrire sur l'ecran a la case 0,0
            LCDWriteStr("Button 1 = 1");
        }
        while (myKeyboardptr->upEdge==1 && myKeyboardptr->downEdge==1){
            LCDGoto(0,0);                       //Commence a ecrire sur l'ecran a la case 0,0
            LCDWriteStr("XXXXXXXX");
            LCDGoto(1,0);                       //Commence a ecrire sur l'ecran a la case 0,0
            LCDWriteStr("XXXXXXXX");
            LCDGoto(2,0);                       //Commence a ecrire sur l'ecran a la case 0,0
            LCDWriteStr("XXXXXXXX");
        }
        while (myKeyboardptr->downEdge==1)
        {
            LCDGoto(1,0);                       //Commence a ecrire sur l'ecran a la case 0,0
            LCDWriteStr("Button 2 = 1");
        }  
        while (myKeyboardptr->upEdge==1)
        { 
            LCDGoto(2,0);                       //Commence a ecrire sur l'ecran a la case 0,0
            LCDWriteStr("Button 3 = 1");
            
            while(isTimeOver(tm7,2000)&&detect_button_press(1)){
                LCDGoto(2,0);                       //Commence a ecrire sur l'ecran a la case 0,0
                LCDWriteStr("Button 3 = 2");     
            }   
        }
        while(myKeyboardptr->downEdge==0&&myKeyboardptr->upEdge==0&&myKeyboardptr->enterEdge==0)
        {
            LCDGoto(0,0);                       //Commence a ecrire sur l'ecran a la case 0,0
            LCDWriteStr("Button 1 = 0");
            LCDGoto(1,0);                       //Commence a ecrire sur l'ecran a la case 1,0
            LCDWriteStr("Button 2 = 0");
            LCDGoto(2,0);                       //Commence a ecrire sur l'ecran a la case 1,0
            LCDWriteStr("Button 3 = 0");
        }
        
      }while(xxx==1);
    
    LCDClearDisplay();
    LCDWriteStr(" Configurations ");
    LCDGoto(1,0);
    LCDWriteStr("  Mises a Jour  ");
    
 
    while(1)
    {
    }
}



//watch this for simulations
//https://www.youtube.com/watch?v=O4IpwgWhqLY&ab_channel=BinderTronics

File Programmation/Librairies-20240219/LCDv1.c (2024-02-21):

#include "p30f4012.h"
#include "dsp.h"
#include "LCD.h"

/***********************************************************
************************************************************
*
* Fichier de configuration et de gestion du LCD EA DOG163
* en SPI (5V)
*           D. CARTON, M. COLAS - Mars 2013
*                        V 1.0
*
*
* ----------------------------------------------------------
*                 Exemple d'utilisation
* ----------------------------------------------------------  
*
*   #include "LCD.h"
*
*   void main(void){
*
*   InitLCD();
*   LCDWriteStr("Bonjour");
*   while(1);
*   }
*
*
*
************************************************************
***********************************************************/





void _wait10mus(unsigned int tenmus){
	int k;

	for(k=0;k<tenmus;k++){
		asm("REPEAT #295");
		asm("NOP");
	}
}


void _InitSPI(void){
	SPI1STATbits.SPIROV=0;
	SPI1CON=0b0000000001111001; 		// prescaler=32 : Fclk=921.5kHz
	SPI1STATbits.SPIEN=1;
	while(SPI1STATbits.SPITBF);
}


void _LCDCmdWrite(char c,unsigned int wait){
	_CSB=0;
	_wait10mus(5);
	_RS=0;
	_wait10mus(5);
	SPI1BUF=c;
	while(SPI1STATbits.SPITBF);
	_wait10mus(wait);
	_CSB=1;
}



/***********************************************************
              fonctions publiques
***********************************************************/

void InitLCD(void){
	// prog RS en sortie
	TRISBbits.TRISB0=0;
	// prog CSB en sortie
	TRISBbits.TRISB1=0;	
	// prog RESET en sortie
	TRISBbits.TRISB2=0;

	_InitSPI();

	_LCDCmdWrite(_FUNCTIONSET,25);
	_LCDCmdWrite(_FUNCTIONSET,25);
	_LCDCmdWrite(_BIASSET,25);
	_LCDCmdWrite(_CONTRASTSET+7,25);
	_LCDCmdWrite(_POWERCONTROL+2,25);
	_LCDCmdWrite(_FOLLOWERCONTROL,3000);
	_LCDCmdWrite(_CLEARDISPLAY,500);
	_LCDCmdWrite(_DISPLAYON,25);
	_LCDCmdWrite(_ENTRYMODESET,25);
	_LCDCmdWrite(_HOME,500);

}


void LCDDataWrite(char c){
	_CSB=0;
	_wait10mus(5);
	_RS=1;
	_wait10mus(5);
	SPI1BUF=c;
	while(SPI1STATbits.SPITBF);
	_wait10mus(25);
	_CSB=1;
}

void LCDWriteStr(char * str){
	int i=0;
	while(str[i]!=0) LCDDataWrite(str[i++]);
}


void LCDGoto( unsigned int r, unsigned int c){
	if((r>2)||(c>15)) return;
	_LCDCmdWrite((char)(0x80|(r*16+c)),25);
}

void LCDContrastSet(unsigned int c){
	if(c>63) return;
	_LCDCmdWrite((char)(_POWERCONTROL|((c>>4)&3)),25);
	_LCDCmdWrite((char)(_CONTRASTSET|(c&0xF)),25);
}

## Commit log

2024-02-21 Upload Eagle Schematics
    Upload of first eagle schematics: lcd connections, buttons, microcontroller conections using 26 pins connector ML26, pins for other microcontroller connections.
    [notre_carte.sch]
2024-02-21 Upload of Schematics Screenshot
2024-02-21 Update carte elec
    [notre_carte.brd, notre_carte.sch]
2024-02-22 Updated schematics of the board
    mise a jour du schéma de la carte électronique réalisé sur eagle, (addition des capacités de découplage de 100nF et amélioration des connections de fils)
    [notre_carte.brd]
2024-02-22 Delete Carte_eagle/carte_realise/carte_realise directory
    faute d'addition
    [notre_carte.brd, notre_carte.sch]
2024-03-01 mise a jour du code main.c
    finalisation de la fonction menu dans les fichiers a rajouter apres (fonctions_sup.h et fonctions_sup.c)
2024-03-01 Mise a jour de fonctions_sup.h et fonctions_sup.c
    Finalisation de la fonction du menu (prototype) a essayer en classe
2024-03-06 Modification de fonctions.h et fonctions.c
2024-03-06 mise a jour de la carte et board
    [notre_carte.brd, notre_carte.sch]
2024-03-06 Rename DACCACCHE_ERRARD_Schematic.sch.xml to DACCACCHE_ERRARD_Schematic.sch
    Changement d'extension
    [DACCACCHE_ERRARD_Schematic.sch]
2024-03-06 new board and schematics
    [DACCACCHE_ERRARD_Schematic.brd]
2024-03-07 Reparation du menu fichier fonction_sup.c
    le menu maintenant affiche les choix et on peux bien sélectionner un choix, mais il y a un peut de retard (a rajouter une fonction wait).
    Après avoir sélectionner un choix c'est le bazar (a réparé)
2024-03-11 Upload pictures de code et carte elec
2024-03-11 Upload compte rendu
    Quelques modifications et rajout de la partie programmation
2024-03-11 Modification de schematics eagle
    Rajout des commentaires sur le schéma
    [DACCACCHE_ERRARD_Schematic.sch]
2024-03-11 Update de main.c
2024-03-11 Update de fonctions_sup.h et fonctions_sup.c
2024-03-20 update board et schematics
    finalisation du schema avec le changement des pins de l'ecran et des boutons
    finalisation de la carte avec l'epaisseur des cables et le cassage des angles droits
    [DACCACCHE_ERRARD_Schematic.brd, DACCACCHE_ERRARD_Schematic.sch]
2024-03-27 Upload carte imprimé
    Upload des fichiers imprimé par monsieur Brasseur (carte.brd, carte.sch, top.pdf et bot.pdf)
    [DACCACCHE_ERRARD_Schematic-p.brd, DACCACCHE_ERRARD_Schematic-p.sch]
2024-04-03 update code
    add interruption for CN pins and the functions of initialisation et eneble interrupt
2024-04-09 Update main.c
    correction des pullups (etats des boutons + initerruption)
    [main.c]
2024-04-10 update modelX
    add function menu
    correction interruption buttons
    add struct
    [main.c]
2024-04-12 Update main.c function_suo.h and .c
    utilisation du struct keyboard au lieu des stateR, stateN et stateB
    ajout d'un retour en arriere pour la fonction menu_principale
2024-04-17 update modele.X
    changements dand readme de cette seance
2024-04-19 Update model.X
    On a reussi a incrementer une variable int et l'afficher en meme temps pour la partie distance obstacle dans parametres.
2024-05-06 update fonctions_sup.c et .h
    ajout des structure menu, menuitems et menuvalues
    programmation d'une part du menu avec ces strucutres
2024-05-07 update fonctions_sup.c et .h
    finialisation de la programmation du menu avec les structure
    il nous reste a faire dans la partie parametre (reglage pid et vitesse)
2024-05-14 upload board pic
2024-05-14 Add files via upload
    Photo de la carte après soudure
2024-05-15 update compte rendu
    [code parametre menu.txt]
